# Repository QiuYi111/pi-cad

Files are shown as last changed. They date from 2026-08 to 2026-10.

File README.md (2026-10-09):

<p align="center">
  Reify · 器成 — Make ideas real.
</p>

<p align="center"><strong>From imagination to what exists.</strong></p>

[English](README.md) · [简体中文](README.zh-CN.md)




Reify is a desktop mechanical-design agent built on
[Prime Agent](https://github.com/PrimeIntellect-ai/prime-agent). Describe a part,
assembly, modification, or analysis. Reify can clarify the brief, explore a
concept, write deterministic CAD, build STEP geometry, inspect the result, and
keep the source, model, measurements, and review connected.

It uses your ChatGPT account through OpenAI Codex OAuth. No API key is required.

## Why Reify

Language models are good at searching a design space. Engineering work also
needs durable facts.

Reify gives the model a persistent Python workbench where requirements,
artifacts, calculations, and observations remain usable across a long task. A
small workflow card shows the current goal, available operations, required
deliverables, and legal next steps. The model stays free to reason and write
code; the runtime governs what counts as a valid build, measurement, review,
and release.

- **Programmable tools.** Prime composes CAD, probes, simulations, and image
  generation in a persistent IPython session.
- **Visual feedback by default.** A build returns useful model views to both the
  agent and the user.
- **Artifacts with identity.** Source, STEP files, images, and evidence retain
  their role and revision. Rebuilding invalidates stale evidence.
- **Workflows that enforce completion.** Missing obligations and invalid
  transitions are executable rules, not reminders.
- **Inspectable work.** The app shows model activity, STEP geometry, workflow
  state, processed trajectories, and distillation progress.

## See it work

### Design a new part

> Design a 100 × 80 × 5 mm mounting plate with four 5 mm corner holes. Keep at
> least 8 mm edge distance, add printable fillets, and export STEP.

Reify turns the brief into deterministic source and geometry, returns visual
feedback, measures the built result, and keeps the final files in your project.

### Build an assembly

> Design a compact foldable phone stand for portrait and landscape use. Make
> the hinge, stops, and clearances suitable for FDM printing.

The agent can explore a concept, define interfaces, build individual parts,
inspect the assembly, and revise the actual candidate.

### Modify or inspect an existing model

> Increase these mounting holes from 4.2 mm to 5.0 mm without changing the
> outer envelope. Verify the result.

> Inspect this STEP file and report its exact bounding box and solid count. Do
> not modify it.

Modification and analysis use separate workflows. Measurements remain bound to
the artifact that was actually inspected.

## Install on Windows

Download **`Reify-Setup-x64.exe`** from the latest release and open it.

The first-run setup uses the same interface as the main workbench. It:

1. checks WSL 2 and Ubuntu;
2. offers the standard Windows WSL installation when they are missing;
3. installs the bundled Prime and Reify runtime;
4. connects your ChatGPT account;
5. asks you to choose a project folder.

Administrator approval is only requested if Windows must enable WSL. Windows
may require one restart. Reify keeps its files and continues setup afterwards.

Requirements:

- Windows 10 version 2004 or newer, or Windows 11;
- virtualization enabled in firmware;
- permission to enable WSL when it is not already installed;
- internet access for ChatGPT sign-in and model calls.

The matching Prime Agent and Reify runtime ship inside the installer. Normal
setup does not clone repositories.

## Install on Linux

Download `Reify-Linux-x86_64.AppImage` or the matching `.deb`. Linux runs the
agent runtime directly; WSL is not involved. Install Bubblewrap with the system
package manager before first launch. The app supplies Prime, Reify, and Node,
then prepares its managed Python environment with `uv`.

## Install on macOS

Download `Reify-macOS-arm64.dmg`, drag Reify to Applications, and open it.
The Apple Silicon build runs Prime and Reify directly on macOS and uses the
system `sandbox-exec` boundary for author and reviewer processes. Public builds
must be Developer ID signed and notarized; unsigned CI artifacts are for
testing only.

## Optional FreeCAD part backend

For parts that are edited again and again, the agent can use `cad.part`: a
parametric FreeCAD model that it changes with small JSON operations. Every
change returns the seven standard views (changed faces in orange, features
labelled by name), a summary of what changed, and a structured error when it
fails. It is optional. Install it with `npm run setup:freecad` (about 4 GB, no
sudo; see `docs/installing-reify.md`). Without it, build123d works as before.

## First design

Open Reify, choose a folder, sign in, and enter a request in the Workbench.
Provider, model, reasoning level, reviewer, and workspace permissions are
available in Settings.

The desktop app includes streaming agent state, a workflow rail and editor, an
interactive STEP viewer, semantic tool cards, project switching, and trajectory
distillation.

## Command line

Developers can also run Reify directly on Linux, macOS, or WSL 2. The repository
and compatibility-facing command names remain `pi-cad` during the rename:

```bash
sudo apt-get update
sudo apt-get install -y bubblewrap libglu1-mesa ripgrep

git clone https://github.com/QiuYi111/prime-agent.git
git clone https://github.com/QiuYi111/pi-cad.git

cd prime-agent && npm ci
cd ../pi-cad
npm install
npm run setup:python
PRIME_AGENT_REPO="$PWD/../prime-agent" npm run prime:setup
```

Main workflows:

| Workflow | Purpose |
| --- | --- |
| `mechanical.one-shot` | New part or assembly through release |
| `mechanical.modify` | Controlled revision of an existing design |
| `mechanical.analysis` | Read-only geometric investigation |

Workflow packages may also define trusted Git actions at workflow start and
phase entry or exit. Reify can initialize a repository and commit changed
source files; generated STEP files and images stay outside Git. Remote pull and
push remain disabled unless the workflow explicitly enables them. Each
workspace commit records the matching Git revision.

## Scope

Reify currently targets Windows with WSL 2 and Ubuntu. It provides STEP-first
build123d authoring, B-Rep probes, managed visual feedback, workflow packages,
review isolation, concept-image generation, and packaged engineering recipes.

It does not replace physical tests, manufacturing review, or professional
engineering sign-off.

## License

[MIT](LICENSE). The Codex image-generation compatibility package retains its
upstream attribution in
[`packages/prime-codex-image-gen`](packages/prime-codex-image-gen).

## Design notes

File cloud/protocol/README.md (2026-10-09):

# @reify/cloud-protocol

Shared, dependency-free types and helpers for the Reify hosted service: the bridge
message types and binary frame codec (`src/bridge.ts`), workspace path checks
(`src/paths.ts`), and the exec helper shared with the desktop `NativeBridge`
(`src/native-exec.ts`). Consumers import the TypeScript source directly.

Run tests with `npm test`.

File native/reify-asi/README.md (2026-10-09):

# reify-asi

Command line feature analyzer for B-rep parts. It is the second DFM layer
(see `docs/dfm/implementation-plan.zh-CN.md`, section 7). It reads a `.brep`
file and writes JSON with holes, cavities, blends, per-face wall thickness and
dihedral angles. Face IDs are 1-based in `TopExp::MapShapes` order, the same
order as FreeCAD's `Shape.Faces`.

It links Analysis Situs `asiAlgo` (v2024.2, BSD-3-Clause) and OCCT 7.6 (LGPL-2.1
with the OCCT exception). The OCCT 7.6 toolkit is built from conda-forge
(`occt 7.6.3`, the `novtk` variant without VTK). No Qt, VTK or Tcl is used.

## Install

```sh
bash scripts/bootstrap-asi.sh            # installs to ${XDG_DATA_HOME:-~/.local/share}/pi-cad/runtimes/asi
bash scripts/bootstrap-asi.sh --force    # removes the env, sources and build, and rebuilds
```

Linux x86_64 only. Exit 2 on other platforms. The script downloads the
Analysis Situs archive, checks its SHA-256, applies
`patches/asiAlgo-utils-no-x11.patch`, and builds with the conda compiler.

Rebuild the program only (after editing `src/`), using the environment the
bootstrap created:

```sh
ASI=${PI_CAD_ASI_HOME:-$HOME/.local/share/pi-cad/runtimes/asi}
$ASI/env/bin/cmake --build $ASI/build -j4        # if the build tree still exists
# or a fresh tree:
$ASI/env/bin/cmake -S native/reify-asi -B /tmp/reify-asi-build \
  -DCMAKE_CXX_COMPILER=$ASI/env/bin/x86_64-conda-linux-gnu-g++ \
  -DCMAKE_PREFIX_PATH=$ASI/env \
  -DASI_SRC=$ASI/analysis-situs-2024.2/src \
  -DEIGEN_INCLUDE_DIR=$ASI/env/include/eigen3
$ASI/env/bin/cmake --build /tmp/reify-asi-build -j4
```

The `bin/reify-asi` wrapper sets `LD_LIBRARY_PATH` to the environment's
`lib/` and runs `bin/reify-asi-bin`.

## Command line

```sh
reify-asi analyze --in part.brep --out result.json \
  [--checks holes,cavities,blends,thickness,dihedral] [--thickness-samples 400]
reify-asi analyze --in part.brep --dump-faces     # face table to stdout, no analysis
reify-asi --version
```

- `--checks` defaults to all five. Only the requested checks appear in the JSON.
- `--thickness-samples N` is the number of sample points per face (default 400).
- `--dump-faces` prints `{"faces": [{"id", "centroid", "area"}, ...]}` (the
  values FreeCAD exposes as `Faces[id-1].CenterOfMass` and `.Area`) and exits.
  `--out` and `--checks` are ignored in this mode.

Exit codes: `0` ok; `2` bad command line; `3` input missing, unreadable or
empty; `4` an analyzer failed; `5` output could not be written. On failure one
line is printed to stderr.

Output (abridged; see `docs/dfm/contract.md`):

```json
{"version": 1, "asi": "2024.2", "faces": 10,
 "holes": [{"faces": [7], "diameter": 3, "depth": 5, "axis": [0, 0, 1], "through": true, "bottom": "none"}],
 "cavities": [{"faces": [7], "base_faces": [3, 5]}],
 "blends": [{"faces": [7], "radius": 2, "kind": "concave"}],
 "thickness": [{"face": 3, "min": 5, "at": [1, 0.75, 5]}],
 "dihedral": [{"edge_faces": [3, 4], "angle_deg": 90, "convex": true, "edge_dir": [1, 0, 0]}],
 "timing_ms": {"load": 0.6, "holes": 3.0}}
```

## How each check is computed

- `holes`: `asiAlgo_RecognizeDrillHoles` finds the hole faces. Connected groups
  of cylinder faces form holes. Through or blind is decided by probing the
  solid just past each end of the cylinder. A blind bottom is the face across
  the bottom circle (`flat`, `cone`, `sphere`, otherwise `unknown`). A through
  hole has `bottom: "none"`. `depth` is the cylinder length (the drill point is
  not included).
- `cavities`: `asiAlgo_RecognizeCavities`. `base_faces` are the faces the cavity
  opens into or sits on.
- `blends`: `asiAlgo_RecognizeBlends`. `kind` is the majority vexity recorded by
  the recognizer, or `unknown` when none was recorded.
- `thickness`: OCCT ray casting, not Analysis Situs' own routine (that routine
  needs the optional Mobius library and returns a mesh field). For each face,
  points are sampled over the trimmed face and a ray is cast along the inward
  normal. The face value is the smallest hit distance. Faces with no hit are
  omitted.
- `dihedral`: the AAG arcs from `asiAlgo_AAG`. `angle_deg` is the magnitude of
  the angle between the two face normals (the AAG reports it signed).
  `convex` comes from the AAG arc type. `edge_dir` is the unit tangent of the
  shared edge at its midpoint.

## Patch

`patches/asiAlgo-utils-no-x11.patch` removes the X11/OpenGL screenshot path from
`asiAlgo_Utils.cpp` (`GeneratePixmap` returns null). Nothing in this tool calls
it. The CMake project refuses to configure an unpatched source tree.

## License

- Analysis Situs (`asiAlgo`, `asiActiveData` parts used here): BSD-3-Clause.
  The LICENSE is in the source archive.
- OCCT 7.6: LGPL-2.1 with the OCCT exception. Distribution must follow the
  LGPL terms (dynamic linking, notice).
- The `reify-asi` sources in this directory: same terms as the repository.

## Files

- `CMakeLists.txt`, `cmake/asi_sources.cmake`: build; the list of Analysis Situs sources used.
- `src/`: CLI (`main.cpp`, `analyze.cpp`), checks (`holes.cpp`, `cavities.cpp`,
  `blends.cpp`, `thickness.cpp`, `dihedral.cpp`), face table (`faces.cpp`), JSON (`json.cpp`).
- `patches/`: source patch applied to Analysis Situs.
- `tools/make_test_parts.py`: builds test parts with FreeCAD's Part API (run with the FreeCAD env's Python).
- `tools/check_face_ids.py`: E0-b check; compares `--dump-faces` with FreeCAD's faces.
- `testdata/plate_4holes.brep`: fixture used by the bootstrap smoke test.
- `conda-linux-64.lock`: explicit conda lock for the environment.

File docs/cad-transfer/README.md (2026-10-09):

# cad.transfer: Fusion and SolidWorks files with feature history

`cad.transfer` sends a Reify part (a FreeCAD `.FCStd` document) to Autodesk Fusion (`.f3d`) or SolidWorks (`.SLDPRT`). The CAD program builds the part again, feature by feature. The file has a feature tree with the Reify feature names. The user can change a dimension in Fusion or SolidWorks and the model rebuilds.

The CAD program runs on the user's own computer. The Reify desktop app starts it. Reify never runs Fusion or SolidWorks on a server.

The wire formats are in [protocol.md](protocol.md).

## Setup

The text below is the same text as Settings > CAD exports in the desktop app.

### Autodesk Fusion

1. Install Autodesk Fusion on this computer.
2. Click **Install add-in**. Reify copies the ReifyExport add-in into Fusion.
3. Start Fusion. If Fusion is open, close it and start it again.
4. In Fusion, open Utilities, then Add-Ins. On the Add-Ins tab, select ReifyExport. Click Run. Turn on Run on Startup.
5. Sign in to Fusion. Then click **Test export**.

Keep Fusion open while you export. The card shows "Add-in running" when the add-in writes its heartbeat. It shows "Add-in not running" when the heartbeat is older than 15 seconds.

Add-in folder:

- Windows: `%APPDATA%\Autodesk\Autodesk Fusion 360\API\AddIns\ReifyExport`
- macOS: `~/Library/Application Support/Autodesk/Autodesk Fusion 360/API/AddIns/ReifyExport`

### SolidWorks (Windows only)

1. Install SolidWorks 2022 or a newer version. SolidWorks must run on Windows.
2. Start SolidWorks one time. Wait until SolidWorks is fully open. Then you can close it.
3. Click **Test export**. Reify starts the ReifyExport program that comes with Reify.

SolidWorks must be activated (licensed). The first export starts SolidWorks if it is closed. Close modal dialogs in SolidWorks before you export, because a modal dialog blocks the export program. The minimum version, 2022, is a proposal. It has not been tested.

The SolidWorks section is hidden on macOS and Linux. In a WSL setup, Reify copies the project files to Windows and back. You do not change any path.

### Test export

**Test export** builds a reference plate (40 x 30 x 5 mm, 4 through holes, 1 pocket), exports it, runs the equivalence check and shows pass or fail and the log path.

## API

```python
import cad

await cad.transfer.status()
# TransferStatus(fusion='ready', solidworks='not_installed')

features = await cad.transfer.features("parts/bracket.FCStd")   # dry run, no CAD program needed
# TransferFeatures(part='bracket', features=7, path='build/transfer/bracket.features.json')

job = await cad.transfer.export("parts/bracket.FCStd", target="fusion", output="exports/bracket.f3d")
result = await job.result()
# TransferResult(target='fusion', file='exports/bracket.f3d', check='passed', features=7)
```

- `doc` is a `.FCStd` path or a `PartDocument`. The tool reads the committed, recomputed document. It never changes it.
- `output` defaults to `exports/<stem>.f3d` or `exports/<stem>.SLDPRT`.
- `check=False` is for debugging. The result then has `check='skipped'`.
- `TransferResult` fields: `target`, `file`, `check_step`, `check`, `features`, `log`, `detail`. A result can be stored in a commit.

| Error code | Meaning |
|---|---|
| `TRANSFER_TARGET_NOT_READY` | The target is not set up. The hint points to Settings > CAD exports. |
| `TRANSFER_UNSUPPORTED_OP` | A feature is outside the supported set. `target` is the semantic path of the feature. |
| `TRANSFER_EXECUTOR_FAILED` | Fusion or SolidWorks could not build a feature. `target` names it. |
| `TRANSFER_CHECK_FAILED` | The exported shape differs. `target` is the first feature that differs. The files are kept for debugging. |
| `TRANSFER_TIMEOUT` | The CAD program did not finish in time. |
| `TRANSFER_UNAVAILABLE` | The Reify desktop app is not running for this project. |

Sidecar operations: `transfer-status`, `transfer-features`, `transfer-export`. In desktop read-only mode, `transfer-export` is denied. The dry run is allowed.

## How it works

1. `export_features` runs in the FreeCAD worker on the recomputed document. It writes canonical feature JSON (`reify.features/1`). It does not replay `ops.jsonl`.
2. The sidecar writes a request in `.pi-cad/transfer/requests/`. The desktop app picks it up. The UI button uses the same code.
3. The desktop app starts the executor: it writes a job file for the Fusion add-in, or starts `ReifyExport.exe` for SolidWorks. One job runs at a time for each executor.
4. The executor builds the part, writes the native file and a verification STEP, and copies the result back into the project.
5. The sidecar compares the verification STEP with the Reify STEP: relative volume error at most 1e-6, equal bounding boxes (1e-6 of the part size), and face fingerprints that match one to one.

The coordinate system stays Z up. A Y-up option is a later change. If it is added, it must also apply to STEP and assemblies.

## Supported features

| Reify feature | Fusion | SolidWorks |
|---|---|---|
| `pad` (length, `midplane`, `reversed`, `up_to_face` on a planar face) | yes | yes |
| `pocket` (length or `through_all`) | yes | yes |
| `hole`: through, blind, counterbore, countersink, drill point | yes (native hole) | yes (Hole Wizard) |
| `hole`: cosmetic thread | no (a warning is written; the diameter stays) | yes |
| `fillet`, `chamfer` (constant size, edges found by geometry) | yes | yes |
| `polar_pattern`, `linear_pattern` (axis along X, Y or Z) | yes | yes |
| `mirror` (origin plane or offset plane) | yes | base or offset plane |
| Sketch geometry: line, arc, circle | yes | yes |
| Sketch plane: XY, XZ, YZ plus offset, Body placement; sketches on planar faces | yes | yes |
| Sketch dimensions (level 1: values) | yes | yes |
| Reify parameters (level 2: user parameters / equations) | yes | yes |
| Density | yes (warning if the API cannot set it) | mass override only (always a warning) |
| Assemblies: part positions only | yes (one `.f3d`) | yes (`.SLDASM` plus part files) |
| Island inside a loop (nesting depth 2 or more) | yes (even-odd rule) | **no** |

In an assembly, a part can come in through `link` or through `import_step` of a STEP that Reify wrote from a project part. Reify records the source `.FCStd` and its hash in `<step>.source.json` when it writes the STEP. If the part changed since (`stale_step`), or the STEP has no record (`unknown_step_source`, for example a bought-in STEP), the export stops and names the unit. Use `link` for project parts.

When an expression is outside the supported grammar (numbers, parameter names, `+ - * /`, parentheses, `mm`, `deg`), the executor uses the value and writes an entry in `result.json` `warnings`. It never skips a feature.

Everything else stops the export with `TRANSFER_UNSUPPORTED_OP`, and the error names the feature: modeled threads, taper, midplane pockets, pad `up_to_last`/`two_lengths`, variable fillets, non-planar faces, bought-in STEP units in an assembly. Joints and mates are not exported: an assembly goes out with the pose its joints solved to (the parts are placed, not jointed), and the result carries a `notes` entry that says so. Reify never skips a feature silently. The canonicalizer deviations are in [protocol.md](protocol.md) section 8.

## Known limits

- The two executors have not run against a real Fusion or SolidWorks yet. Both READMEs list every API assumption that needs a real install: [Fusion](../../executors/fusion/README.md), [SolidWorks](../../executors/solidworks/README.md). The SolidWorks executor has not been compiled.
- A dimension change in Fusion or SolidWorks changes that file only. It does not change the Reify parameter. Parameters that Reify exports become user parameters (Fusion) or equations (SolidWorks), so one change there rebuilds all features that use it.
- The highest-risk unverified parts are the assembly code (both targets) and the SolidWorks Hole Wizard call. Its constants are placeholders. Record a macro in SolidWorks and replace them.
- Fusion shows the new document tab during a job. The add-in closes the document without a cloud save (`close(False)`). Check on a real install that nothing reaches the cloud project.
- The Fusion and SolidWorks API versions that were tested are not pinned yet. Record them after the manual checks.
- SolidWorks runs only on the customer's licensed copy.
- The C# executor needs a code signature, or Windows SmartScreen warns the user. The signing step is a hook in `apps/desktop/scripts/package-windows.mjs`. It does nothing until the signing variables are set.

## Manual checks before the issue closes

Record each result in the PR.

1. Export `body_shell`, `axle`, `roller_screw` and the reference plate to Fusion (and to SolidWorks), once from the UI and once from the agent. The equivalence check must pass.
2. The feature tree shows named features in the same order as Reify.
3. Change one dimension in Fusion or SolidWorks. The model must rebuild.
4. **WSL:** run one export from a project in WSL (`/mnt/c/Users/...` paths). The job folder crosses the Windows/WSL boundary, so check that the native file and the verification STEP come back into the project.
5. An assembly of project parts: export once with `link` and once with `import_step` of the part STEPs (the second must work only while the STEPs are current).
6. Record the Fusion and SolidWorks versions that were tested, and whether Fusion left anything in the cloud project.

## Phases

P0 and P1 (parts, through holes, polar patterns) and P2/P3 (the table above) are written. Nothing in the executors has run against a real Fusion or SolidWorks. Treat P2 and P3 as unverified until the manual checks in the issue pass.

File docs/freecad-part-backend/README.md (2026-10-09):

# FreeCAD part backend: implementation notes

This note records what was built for the plan "FreeCAD Part backend (one PR)", what was measured, and where the installed FreeCAD differs from the plan. The user-facing text is in `docs/installing-reify.md` and `skills/parametric-cad-modeling/references/freecad-part-ops.md`.

## Measured

| Item | Value |
|---|---|
| FreeCAD | 1.1.0 (conda-forge `freecad=1.1.0`, build snapshot `20260325`) |
| OpenCASCADE | 7.9.3 |
| Python in the FreeCAD environment | 3.11 |
| Disk use after install | 4.2 GB (4.1 GB environment + 18 MB micromamba; the download cache is cleaned) |
| Install time (`npm run setup:freecad`, fast network, Linux x86_64) | 41 s |
| Cold start (spawn worker, import FreeCAD, create a document) | 0.31 s |
| `worker.selftest` (Pad, Pocket, Fillet, STEP export) | 0.67 s including interpreter start |
| `part-apply`, first build (plate, 4 holes, fillet) with identity bind, geometry check, 7 renders, evidence | 5.5 s (includes the first start of the uv `cadctl` kernel) |
| `part-apply`, one edit, warm | 2.1 s (worker part about 0.15 s; the rest is bind, inspect and rendering) |
| `part-try`, warm | 1.7 s |
| `cad.model.build` (build123d), same part, for comparison | 1.3 to 1.6 s |
| Pose sweep, 33 samples with refine, two bodies | 0.35 s |

## What the views look like

Hole widened from 6 mm to 8 mm with one op, `{"op": "set", "target": "Params", "prop": "hole_d", "value": 8}`. Only the four hole walls are orange, `mount_hole` is labelled, and the first image's text says `volume -527.788 mm³`.

| Before (rev 1) | After (rev 2) |
|---|---|
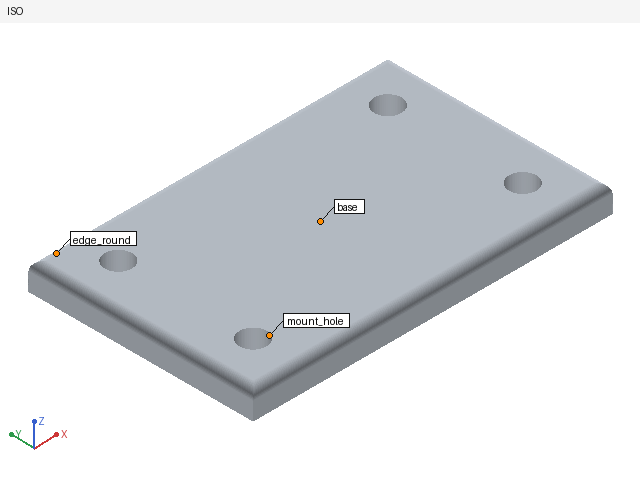
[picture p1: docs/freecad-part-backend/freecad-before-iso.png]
before
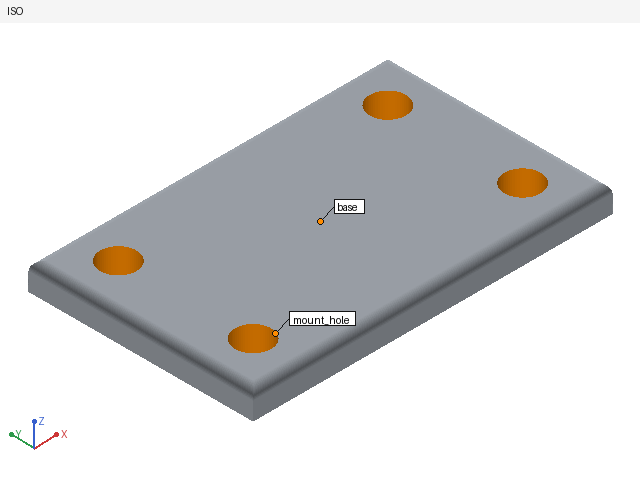
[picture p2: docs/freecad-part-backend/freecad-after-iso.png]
after
|  |  |

The same feature with build123d: a wider plate and one bigger hole, rebuilt with `cad.model.build`. The new faces are orange and the summary reports the volume and bounding box change.

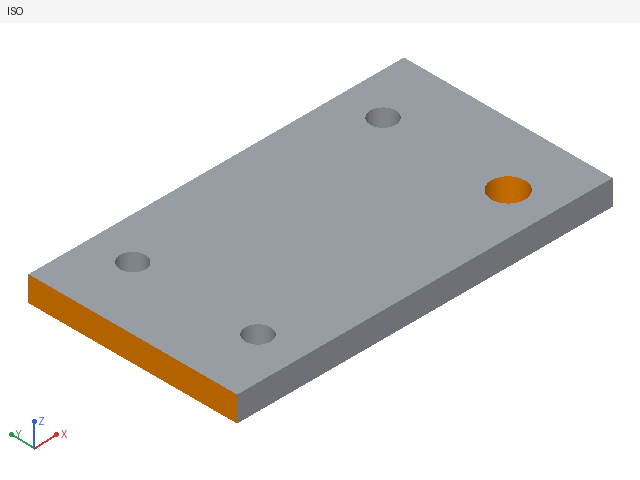
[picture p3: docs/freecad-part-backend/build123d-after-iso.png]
build123d


## Deviations from the plan

1. **micromamba comes from conda-forge**, not from `micro.mamba.pm`. The bootstrap script downloads `micromamba-2.9.0-0.tar.bz2` from the conda-forge channel and checks a pinned SHA-256. It is the same host that serves the FreeCAD packages, so one allowed host is enough.
2. **`FreeCAD.so` is in `<env>/lib`**, which is not on `sys.path`. `runtime.json` therefore has a `libPath` field, and the worker is started with `PYTHONPATH=<repo>/python:<libPath>`.
3. **Roles do not use FreeCAD's element map.** `getElementHistory` returns nothing for faces, and a mapped name changes when a later feature touches the face (a pad's top face after a hole is cut through it). Roles come from the geometry each feature defines: the faces a feature created are the faces of its result that are not inside a face of its base shape; a face of the final body belongs to a created face when both lie on one surface and the final face is inside it (`python/reify_freecad/roles.py`). `ROLE_FALLBACK_GEOMETRIC` is reported only when a role cannot be derived at all. The role-stability test records five edits (diameter, thickness, fillet, slot pocket) with the wall still the right cylinder.
4. **Rollback reloads the saved file** instead of `abortTransaction`. The disk file is the only trusted state. Transactions are still opened.
5. **The highlight shows new surfaces, not every touched face.** A plate that gains a hole keeps its top face grey; the hole wall is orange. `faces.new` and `faces.removed` still count every face whose fingerprint changed, with the rule of section 3.1. If more than 60% of the faces changed, nothing is coloured. Fingerprints carry one extra field, `ap` (a point on a cylinder or cone axis), for this.
6. **The identity selector grammar gained `axisPoint` and `bboxCenter`.** `centroid` of a curved face in cadctl is a parametric centre that depends on the seam. FreeCAD cannot reproduce it. See `docs/identity-protocol.md`.
7. **A `part-apply` that fails after the commit is undone.** If identity binding or the geometry check fails after the worker committed, the sidecar calls `undo` and reports `rolledBack: true`, so no half-applied revision remains.
8. **`part-open` of an existing document with geometry also builds and observes it**, so the Agent sees the model when it opens it. A document without geometry returns no images.
9. **Pose sweep views label the two parts** (centres of the two named bodies) instead of colouring them.
10. **No CJK label font.** The repository has none. Labels are ASCII; other characters become `?`.
11. **Not changed**: the desktop activity cards. A `doc.apply(...)` call shows as a generic Python card with its images.

## Assemblies and review fixes

- Units are `body`, `occurrence` and `reference`. The ops `link`, `import_step` and `joint` add them.
- An occurrence is an `App::Part` container that holds a `Part::Feature` copy of the part shape. The copy refreshes when the sha256 of the part file changes. This is a deviation from the plan: it does not use a cross-document `App::Link`, because that link is not stable when documents reload.
- A joint computes the child pose from role frames. Its `value` is bound by an expression. `apply_joints` runs after each recompute. `sweep` can sweep a joint value.
- Named export writes a flat STEP: one product per unit, named by its semantic path, with its pose. `cadctl assembly-tree` and render `focus`/`hide` use these names.
- `cad.part` is now the default modeling path. build123d stays for compatibility.
- If FreeCAD is not installed, the error is `FREECAD_NOT_INSTALLED`. Tell the user the one command (`npm run setup:freecad`, about 4.2 GB, no sudo, once) and stop. There is no silent build123d fallback.

## Version checks (plan section 7)

1. `App::VarSet` works. Dynamic properties (`ReifyPath`, the `Params` attributes, requirement fields) are stored in the `.FCStd` and survive a reopen (`test_the_document_reopens_with_the_same_model`).
2. Sketch properties `DoF`, `ConflictingConstraints`, `RedundantConstraints`, `MalformedConstraints` and `solve()` exist as named. Constraint expressions need units: `Params.w - 3` fails with a unit mismatch, so generated expressions write `3 mm`, and an `=expression` the user writes without units is reported as `EXPRESSION_INVALID` with a hint.
3. `ElementMap`, `ElementReverseMap` and `getElementHistory` exist, but see deviation 3.
4. `PartDesign::Hole`: `Diameter`, `Depth`, `DepthType` (`Dimension`, `ThroughAll`), `Threaded`, `ThreadType`, `ThreadSize` (spelled `M6x1`, so `M6` is expanded), `HoleCutType` (`Counterbore`, `Countersink`), `DrillPoint` (default angled, so a cone is a countersink only when the hole has one).
5. `import PartDesign` needs no GUI.
6. `openTransaction`, `commitTransaction` and `abortTransaction` work headless with `UndoMode = 1`.

Other differences that cost time:

- Features and sketches inside a body are in the body's local frame; only `Body.Shape` carries the pose. Roles are found in the local frame and moved to world coordinates by the body placement.
- A pattern must be added to the body after `Originals` is set (`doc.addObject`, then `body.addObject`). With `body.newObject` the body does not move its Tip to the pattern.
- `Pad.Type` values: `Length`, `UpToLast`, `UpToFirst`, `UpToFace`; `Pocket.Type` has `ThroughAll`.
- There is no `isTouched()`. "Recomputed" comes from a document observer that sees `Shape` assigned during `recompute()`. FreeCAD touches every object that references the `Params` object when one parameter changes, so `features.recomputed` lists those objects, not only the ones whose value changed.
- A body's single solid can come wrapped in a compound, which has no `CenterOfMass`; queries unwrap it.
- The conda-forge `freecad` package has newer weekly builds (`2026.09.16`). The environment pins `1.1.0`.

## Not verified here

- **osx-arm64.** The lock file was solved on Linux (`CONDA_OVERRIDE_OSX=11.0`) and has not been installed on a Mac. The default macOS install path contains a space (`Application Support`); conda environments in paths with spaces can break scripts with shebang lines. If the install fails there, set `PI_CAD_FREECAD_HOME` to a path without spaces.
- **Desktop manual demo** (acceptance item 4) was done through the Agent API, not through the Reify desktop window.

## Tests

| Where | What | Needs FreeCAD |
|---|---|---|
| `tests/test_reify_freecad_pure.py` | op schema, shared path vectors with cadctl, expressions, error mapping, no FreeCAD import in pure modules | no |
| `tests/freecad/` (34 tests) | nine features, recompute scope, rollback, conflicts, role stability, undo, pose sweep, budget, requirements, the examples in the reference document | yes |
| `tests/freecad-worker.test.ts` | worker bridge with a fake worker: order, timeout kill, restart and reopen, errors, abort | no |
| `tests/part-ops-authorization.test.ts` | `model.build` versus `probe.run`, read-only author, reviewer | no |
| `tests/part-e2e.test.ts` | open, build, edit, resolve the named hole, try, failing fillet, budget kill, undo | yes (skipped otherwise) |
| `tests/build-changes.test.ts`, `tests/test_face_fingerprints.py`, `tests/test_render_highlight.py`, `tests/test_bind_identity.py` | change summary, fingerprints (shared vectors), render highlight and labels (pixel-identical without them), identity binding | no |

Run the FreeCAD tests with `PYTHONPATH=python:<env>/lib <env>/bin/python -m unittest discover -s tests/freecad`.

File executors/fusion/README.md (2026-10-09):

# ReifyExport: Autodesk Fusion add-in

Executes Reify canonical feature JSON (`reify.features/1`) in Fusion and exports `.f3d` plus a STEP file for the equivalence check. The wire contract is `docs/cad-transfer/protocol.md` (sections 1 and 2). Version 0.2.0 (P0 to P3).

## Install

Copy the folder `ReifyExport/` to:

- Windows: `%APPDATA%\Autodesk\Autodesk Fusion 360\API\AddIns\ReifyExport`
- macOS: `~/Library/Application Support/Autodesk/Autodesk Fusion 360/API/AddIns/ReifyExport`

The desktop app reads `ReifyExport.manifest` (`version`) to show the installed version. `ReifyExport.py` `__version__` must match (a test enforces it).

## Enable

In Fusion: Shift+S (Scripts and Add-Ins), tab Add-Ins, select ReifyExport, Run. Tick "Run on Startup" so it starts with Fusion. The manifest has `runOnStartup: false` as a default.

## Job protocol (summary)

Job root: Windows `%LOCALAPPDATA%\Reify\transfer`, macOS `~/Library/Application Support/Reify/transfer`. Env `REIFY_TRANSFER_ROOT` overrides it.

- Add-in writes `fusion/heartbeat.json` every 5 s (atomic): pid, version, app, `signedIn`, `updatedAt`.
- Dispatcher writes `fusion/inbox/<jobId>.json` (tmp + rename). The add-in claims it by renaming it to `fusion/outbox/<jobId>/job.json`, builds, and writes `part.f3d`, `check.step`, `log.txt`, and last `result.json` (atomic).
- Result errors: `{code: EXECUTOR_FAILED | UNSUPPORTED_OP | BUSY, message, feature, step}`. `feature` is the Reify semantic name. Steps: `plan`, `document`, `sketch` (sketch failures report the feature that uses it), `profile`, `extrude`, `pattern`, `export`, `timeout`, `job`.
- One job at a time. Plan errors (unsupported feature) are raised before Fusion is touched.

## Code layout

Pure Python, no `adsk` import, unit tested with `python3 -m unittest discover -s tests/fusion_addin -v`:
`jobroot.py`, `jobs.py` (claim, validate, result, error mapping), `plan.py`, `profiles.py` (even-odd), `geom.py`, `workers.py` (watcher and heartbeat threads).
Thin Fusion layer: `fusion_exec.py` (all `adsk` calls), `ReifyExport.py` (run/stop, custom events).

Threading: the watcher thread only calls `app.fireCustomEvent`. The event handler runs on the Fusion main thread and does all API calls. The heartbeat thread uses a cached snapshot (refreshed by a tick event and after each job), so the heartbeat stays fresh while a long job blocks the main thread.

## What it builds (0.2.0)

Each group sits behind a flag of `plan.build_plan(enable_p1, enable_p2, enable_p3, native_holes, bind_params)` so it can be switched off.

- P0: `pad` (length, midplane), `pocket` (length or through_all).
- P1: extrude-cut `hole` of circles (used when `native_holes=False`), `polar_pattern` (CircularPatternFeature, origin axis X/Y/Z through the origin only).
- P2: `linear_pattern` (RectangularPatternFeature, one direction along a world axis, spacing mode), `mirror` (MirrorFeature; plane must be parallel to XY/XZ/YZ: origin plane when through the origin, else an offset construction plane; tilted planes are `UNSUPPORTED_OP` naming the feature), sketch `dimensions`, top-level `material.density_kg_m3`, assembly jobs.
- P3: user parameters, native `holeFeatures` (through/blind, counterbore, countersink, drill point flat/angled), `fillet`, `chamfer` (edges resolved by `edgematch.py`), `face_ref` (`facematch.py`) for sketches on tilted faces and for `pad` `up_to_face`.
- Sketch geometry: line, arc, circle, polyline. Each profile region is chosen with the even-odd rule (see `profiles.py`); profiles are never selected blindly.
- Anything else raises `UNSUPPORTED_OP` naming the feature (and the option) in the plan, before Fusion is touched. Nothing is skipped silently.

Behaviour worth knowing:

- **Parameters (level 2).** `parameters[]` become `design.userParameters`. A scalar `expr` is bound (as a Fusion expression string) only when it passes `params.py`: grammar of protocol section 7, known names, the expected unit dimension (length or angle), and it evaluates to the scalar's `value` (1e-6). A bare number next to a quantity adopts its unit (`=hole_d + 2` becomes `hole_d + 2 mm`). Anything else uses the value and adds `{feature, field, expr, reason}` to `result.json` `warnings`. If Fusion rejects an accepted expression at feature creation, the feature is rebuilt from the value and a warning `field: "expression"` is added. The feature is never skipped. Parameters are design-global, so assembly jobs do not create them (one warning per part).
- **Warnings.** `result.json` always has `warnings` (a list). Besides expressions it carries: cosmetic thread not created, hole-sketch dimensions not added (the hole sketch is rebuilt from `positions`), a dimension skipped because Fusion's sketch axes are rotated against the canonical u/v (horizontal/vertical is undefined), and a density that could not be applied.
- **Holes.** `native_holes=True` (default) uses `holeFeatures` with sketch points at `positions`. A `thread` is NOT created: a Fusion tapped hole changes the hole diameter, which would break the equivalence check, so the hole keeps its diameter and a warning is added. `thread.modeled: true` is `UNSUPPORTED_OP`.
- **Sketch dimensions.** Added after the geometry is drawn: `distance` (aligned), `distance_x`/`distance_y` (horizontal/vertical), `radius`, `diameter`, `angle`. A dimension that the API rejects fails the job with `EXECUTOR_FAILED`, `step: "dimension"`, and the message names the sketch. If the dimension carries a valid parameter expression, it is bound to the dimension.
- **Edge and face refs.** Edges are matched by curve type, midpoint, length (and radius/centre/axis/start/end when given) with tolerance `1e-4 x max(part diagonal in mm, 1)`. Zero or several matches fail with `step: "edge_ref"` / `"face_ref"` naming the feature. The tolerance reading of "1e-4 mm times the part diagonal" is ours (protocol section 7 is ambiguous).
- **Assemblies.** `job.kind == "assembly"` with `assembly` inline. One new design, one component per occurrence (`addNewComponent(matrix)`, matrix columns are the rotation columns, origin in cm), each built with the part's feature plan. The STEP and the single `part.f3d` contain the whole assembly. `feature_volumes` has one entry per occurrence name. Mirrored (det < 0) transforms are `UNSUPPORTED_OP`. `files.extra` is not produced.
- **Material.** The density is set by copying a library material (`design.materials.addByCopy`), setting `structural_Density` (kg/cm^3) and assigning it to the bodies. If anything fails it is a warning, never a failed job.

Other decisions and limits (from 0.1.0):

- A second `pad` joins the existing body (first pad is a new body). A `pocket`/`hole`/`fillet`/`chamfer` before any body is an error. Only one body per part.
- `polar_pattern` and `linear_pattern` need a world axis; `mirror` accepts patterns as originals, patterns do not. For angles below 360 the angle is the span from first to last occurrence.
- Distances are passed with `ValueInput.createByReal` in cm (the API unit), or `createByString(expression)` when a parameter is bound.
- Sketch plane: base origin plane when the offset is 0, else a construction plane by offset. Offset sign and extrude direction are measured against the real Fusion plane normal at run time (point mapping uses `sketch.modelToSketchSpace`), so a flipped Fusion normal is handled.
- Reify is Z-up. The add-in forces `defaultModelingOrientation = ZUp` while creating the document and restores the preference afterwards.

## Unsaved and cloud documents (read this)

- `app.documents.add(FusionDesignDocumentType)` creates a NEW, UNSAVED document in memory. It is not on the cloud until someone saves it (Save asks for a project and name). The add-in never calls `save` or `saveAs`.
- `doc.close(False)` closes the document and discards it; `False` means "do not save". The add-in does this in a `finally` block after the exports, also when the job fails.
- `design.exportManager` (`createFusionArchiveExportOptions`, `createSTEPExportOptions`, `execute`) writes to the local path we pass and does not upload anything.
- Side effects: the new document becomes the active document, so the user sees a tab appear and disappear while a job runs. The user's own open documents are not modified or closed.

UNVERIFIED - check on a real install (each becomes a PR risk):

1. `doc.close(False)` on a never-saved document closes without a prompt, and nothing appears in the cloud project list or the "Recent" list afterwards.
2. `documents.add` does not trigger a "save to project" dialog or a cloud autosave for a new document (for example when the user has autosave or "save on close" prompts enabled).
3. `Application.preferences.generalPreferences.defaultModelingOrientation` exists, applies to `documents.add`, and the exported STEP is Z-up. If it does not apply, the equivalence check will report a rotated bounding box.
4. `design.designType = ParametricDesignType` can be set on a fresh document without a dialog. `design.fusionUnitsManager.distanceDisplayUnits` exists (only affects display; failure is logged as a warning).
5. `ProfileCurve.geometry` is in sketch space. (If not, the code retries as model space and logs `WARN`.) `geometry.evaluator.getParameterExtents/getPointAtParameter` work on all profile curve kinds.
6. Timeline/sketch/plane `name` accepts `/` (otherwise the code falls back to `_` and logs a warning; the Reify semantic name is then not preserved in Fusion).
7. `ExtentDirections` lives in `adsk.fusion`; `setOneSideExtent`, `setSymmetricExtent(distance, isFullLength=True)` (total length), `setAllExtent(SymmetricExtentDirection)`.
8. `CircularPatternFeatureInput` accepts `ValueInput.createByReal` for `quantity` and `totalAngle` (radians), and the pattern of a cut feature recomputes correctly.
9. `physicalProperties.volume` is cm^3 and the sum over `rootComponent.bRepBodies` is the solid volume after each feature.
10. `app.currentUser` / `app.isOffline` give a usable `signedIn`. These are read on the main thread only.
11. `app.fireCustomEvent` from a non-main thread is safe (documented as thread safe) and `registerCustomEvent` after an unclean shutdown needs the `unregisterCustomEvent` we do first.
12. The add-in runs on Fusion's bundled Python; only the standard library is used.
13. A custom-event handler that runs for a long time (a minute or more) does not make Fusion show "not responding" or kill the add-in.
14. Through-all cut with `setAllExtent` cuts all material on the chosen side only (sketch plane is the top face in the sample).

### New UNVERIFIED items for P2 and P3

15. `features.rectangularPatternFeatures.createInput(entities, axis, quantity, distance, SpacingPatternDistanceType)` accepts an origin construction axis and feature entities; a negative distance reverses the direction.
16. `features.mirrorFeatures.createInput(features, plane)` accepts origin planes and offset `ConstructionPlane`s for feature mirroring.
17. `sketch.sketchDimensions.addDistanceDimension / addRadialDimension / addDiameterDimension / addAngularDimension` signatures (point/entity, text position), `DimensionOrientations` enum names, and that setting `dimension.parameter.expression` to a parameter expression does not move the geometry. Dimensions on a point of a mirrored sketch, and `originPoint` use.
18. `holeFeatures.createSimpleInput / createCounterboreInput / createCountersinkInput`, `setPositionBySketchPoints`, `setAllExtent(direction)`, `setDistanceExtent`, `isDefaultDirection` (assumed: default direction is opposite to the sketch normal), `tipAngle` (assumed: 0 means flat bottom, 118 deg default). Hole depth semantics (to the full diameter shoulder) versus FreeCAD.
19. Cosmetic threads are not created at all (see Holes above). A real implementation needs `HoleFeatureInput` tapped-hole options and a check that the hole diameter is unchanged.
20. `filletFeatures.createInput().addConstantRadiusEdgeSet(edges, radius, isTangentChain=False)` and `chamferFeatures.createInput2().chamferEdgeSets.addEqualDistanceChamferEdgeSet(edges, distance, False)`. If Fusion propagates the fillet along tangent edges anyway, the volume check will show it.
21. `BRepEdge.geometry.objectType` strings (`adsk::core::Line3D`, `Circle3D`, `Arc3D`), `BRepEdge.evaluator.getPointAtParameter` at the parameter midpoint equals the arc-length midpoint, `BRepEdge.length` in cm, `BRepFace.geometry.objectType == "adsk::core::Plane"`, `BRepFace.area` in cm^2, `BRepBody.boundingBox`.
22. `sketches.add(BRepFace)` for a sketch on a tilted face, and that `modelToSketchSpace` on it maps as assumed. `ExtrudeFeatureInput.setOneSideToExtent(face, matchShape, offsetDistance, directionHint)` signature (we pass `directionHint` by keyword).
23. `design.userParameters.add(name, ValueInput, units, comment)` with `createByReal` in internal units (cm, radians) for `mm`/`deg` and with an expression string; Fusion's reserved names (we reject a short list in `params.RESERVED`); `createByString("thickness - 2 mm")` style expressions evaluate in the units we assume.
24. Material: `app.materialLibraries`, `design.materials.addByCopy`, the property id `structural_Density` and its unit (assumed kg/cm^3), assigning `body.material`.
25. Assemblies: `rootComponent.occurrences.addNewComponent(Matrix3D)` and `Matrix3D.setWithCoordinateSystem(origin, x, y, z)`; whether `sketch.modelToSketchSpace` inside an occurrence's component uses component-local space (assumed) or assembly space; whether features of different components stay independent in one parametric design; the single `.f3d` and the root STEP export contain all occurrences at their transforms.
26. A pattern of a hole feature in a component, and a mirror of a pattern feature, recompute without error.

## Verified in a live Fusion (2705.1.25)

Items 5, 7, 9, 14, 15, 16, 20, 21, 22 (sketch on a tilted face), 23 and 25 held. These did not, and the code now follows what Fusion does:

- Hole direction: a hole's default direction is opposite to the sketch normal, and `PositiveExtentDirection` means that default direction. `isDefaultDirection` follows the same rule (item 18).
- Flat drill point: `tipAngle` 180 deg. 0 is rejected (item 18).
- `ExtrudeFeatureInput` has no `setOneSideToExtent`. Pad up to a face uses `setOneSideExtent(ToEntityExtentDefinition.create(face, False), direction)` (item 22).
- A sketch created on a face can come with auto-projected reference curves. They are deleted, otherwise they become extra profiles.
- `BRepEdge.geometry` can be `None`. Such edges are skipped when matching edge references.
- A negative dimension expression flips the sketch geometry, so it is not bound.
- A rotation rounded to 6 decimals is rejected by `addNewComponent`; the frame is orthonormalized first.
- The midpoint of a full circle is where the kernel's seam is, so circle edge references match on centre, radius and axis.
- The equivalence check places cylinders and cones by axis, not by centroid, for the same reason.
- A part keeps its place in the assembly (an aircraft tail is 800 mm from the origin) and the new document's camera looks at the origin, so the add-in fits the view before it writes the .f3d. Otherwise the file opens on an empty canvas, and `fit` on it does nothing: a body saved without display graphics draws nothing until Fusion generates them. Fitting before the save generates them and stores them in the file (checked by importing the .f3d again: camera on the body, solid drawn).
- Fusion refuses a dimension on geometry it already holds in place (`VCS_SKETCH_OVER_CONSTRAINTS`): the second of two concentric circles, rectangles that line up with each other. The dimension is skipped with a warning; the equivalence check still proves the shape.

Still UNVERIFIED: items 1 to 4, 6, 8, 10 to 13, 17, 19, 24, 26.

How it was run: the "Fusion MCP Addin" `execute_api_script` tool, loading the add-in sources from a copy and calling `jobs.process_job` per fixture. That reproduces a job without restarting the add-in.

## Tests

`python3 -m unittest discover -s tests/fusion_addin -v` (plain `unittest`, no Fusion).
`tests/fusion_addin/fake_adsk.py` is a stub of the used `adsk.core` / `adsk.fusion` surface. It catches typos, call order, unit conversion and sign handling. It cannot prove that the real API has these members or behaves the same (see its docstring).

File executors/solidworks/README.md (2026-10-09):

# ReifyExport (SolidWorks executor)

`ReifyExport.exe` is a small .NET console program. The Reify desktop app starts it once per job. It reads the job folder
`<jobRoot>\solidworks\jobs\<jobId>\job.json` (protocol: `docs/cad-transfer/protocol.md`, sections 1 and 2), builds a native
SolidWorks part with feature history through the SolidWorks COM API, and writes into the same folder:
`part.SLDPRT`, `check.step`, `result.json`, `log.txt`.

```
ReifyExport.exe --version        prints: ReifyExport 0.1.0
ReifyExport.exe --check          prints: {"version":"0.1.0","swInstalled":true,"swVersion":"2023"}
ReifyExport.exe --job <dir>      runs one job; exit code 0 = ok, 1 = failed (result.json says why), 2 = bad arguments
```

## Status: NOT COMPILED, NOT RUN

The environment this was written in has no `dotnet` SDK and no SolidWorks (the SDK download host was blocked by the proxy).
Nothing here was compiled, no test was run, and no call was made against SolidWorks. The code was written carefully from
knowledge of the public SolidWorks API. Treat the first build on a Windows machine as the first compile, and the first
job as the first test of every API call listed under UNVERIFIED below.

## Layout

| Project | Target | Content |
| --- | --- | --- |
| `ReifyExport.Core` | net8.0, no Windows/SW dependency | JSON models, planner (validation, unit and plane math), `JobRunner`, `result.json` writer, log, CLI parsing, `--check` logic behind `ISwProbe`, watchdog |
| `ReifyExport` | net8.0-windows, x64 | `Program` (mutex, watchdog, COM STA thread), `SwPartBuilder` (all SolidWorks calls), `RegistrySwProbe`, `ComHelper` |
| `ReifyExport.Core.Tests` | net8.0, xunit | parsing of a sample canonical file, plan order, mm to m, direction logic, error mapping, runner with a fake builder, `result.json` shape, `--check` with a fake probe |

All sequencing and error handling is in `Core.JobRunner` and talks to SolidWorks only through `IPartBuilder`, so it is tested without SolidWorks.

## Build

Tests (any OS):

```
dotnet test executors/solidworks/ReifyExport.Core.Tests
```

Executor (Windows, SolidWorks installed, or the two interop DLLs copied somewhere):

```
dotnet publish executors/solidworks/ReifyExport -c Release -r win-x64 --self-contained false
# interop DLLs not in the default location:
dotnet publish executors/solidworks/ReifyExport -c Release -r win-x64 --self-contained false /p:SwApiDir="D:\sw\api\redist"
```

The project references `SolidWorks.Interop.sldworks.dll` and `SolidWorks.Interop.swconst.dll` by HintPath
(`C:\Program Files\SOLIDWORKS Corp\SOLIDWORKS\api\redist` by default, override with `/p:SwApiDir`). They are not in the repo.
The packaging step supplies them; `Private=true` copies them next to the exe. Requires the .NET 8 Desktop/Runtime on the
customer machine (framework-dependent publish) or switch to `--self-contained true` in packaging.

## Signing

Sign `ReifyExport.exe` (and the interop DLLs if the packaging policy requires it) in the desktop packaging step, with the same
Authenticode certificate as the desktop app:
`signtool sign /fd SHA256 /tr <timestamp-url> /td SHA256 /a ReifyExport.exe`.
An unsigned exe started from `%LOCALAPPDATA%` can trigger SmartScreen ("Windows protected your PC") or be blocked by AV or
AppLocker. SmartScreen reputation builds per certificate, so use the app's certificate rather than a new one.

## Minimum SolidWorks version: proposal 2022

Proposal only, not a tested bound. Reasons: the calls used (`FeatureExtrusion3`, `FeatureCut4`, `FeatureCircularPattern5`,
`ModelDocExtension.SaveAs3`, `InsertAxis2`) are all older than 2022, but the author could not run any version, so 2022 is a
recent, still widely deployed release that the lead can confirm or move after the first real run. `--check` reports the newest
installed year it finds, so the app can gate on it.

## How the plan works

- Planning happens completely before SolidWorks is touched. Anything unsupported stops the job with `result.json`
  `ok:false`, `error.code: "UNSUPPORTED_OP"`, `error.feature` = the feature (never skipped silently): unknown feature type,
  unknown sketch geometry (only line, arc, circle, polyline), open loops, loop depth >= 2, oblique extrusions, extents other than
  length / through_all, multiple bodies, polar pattern axes not parallel to a world axis or not through the origin.
- Units: JSON mm / degrees. The SolidWorks API takes meters / radians / m3 regardless of document units. All conversion is in
  `Units`. The document is also set to mm. Reported volumes are mm3.
- Coordinates: Z-up world coordinates are used unchanged as SolidWorks model coordinates (no rotation). Mapping (UNVERIFIED):
  `XY` -> Front plane (SW normal +Z), `XZ` -> Top plane (normal +Y), `YZ` -> Right plane (normal +X). Base planes are the first three
  `RefPlane` features of the new part by type order (Front, Top, Right in the default template).
- Offset planes: a frame origin off the base plane creates a distance reference plane; offset = dot(frame.origin, SW plane
  normal).
- Sketch points: world point (m) -> `Sketch.ModelToSketchTransform` -> sketch (x,y). The transform is authoritative. Checks:
  the transformed point must lie on the sketch plane (|w| < 1e-7 m) else `EXECUTOR_FAILED` (wrong plane order or offset sign);
  a predicted mapping (`SketchMath.ExpectedSketchCoords`) is compared and only logs a warning. Arc direction is derived from
  the sketch-space images of the canonical U and V axes, so a mirrored sketch frame still gives the same arc.
- Nested contours: all geometry of a canonical sketch is drawn into one SolidWorks sketch, the sketch feature is pre-selected
  and the extrude/cut is called. SolidWorks builds the regions from the contours. A depth-0 loop with depth-1 loops inside (plate
  with holes, pocket ring) matches the protocol's even-odd rule. Depth >= 2 (island inside a hole) is rejected with
  `UNSUPPORTED_OP`: a pocket with an island is a known limit.
- Directions: pad default = +sketch normal, cut default = -normal (UNVERIFIED, one constant: `PlanConventions.CutDefaultsToMinusNormal`).
  `Dir` (reverse) is set when the canonical `direction` differs from that default. `midplane` -> `swEndCondMidPlane`.
  `through_all` -> `swEndCondThroughAll`. A pad that adds no volume, or a cut that removes none, fails the job with a clear message,
  which also catches a wrong direction convention.
- Hole: see P3 below (Hole Wizard, with a cut-extrude fallback for plain holes).
- Polar pattern: reference axis from two base planes (`InsertAxis2`), then `FeatureCircularPattern5`, equal spacing for a full
  circle; partial angle uses spacing = angle / (n-1).
- After every feature the volume is read and written to `feature_volumes` (mm3).
- Semantic names are applied to sketches and features (`Feature.Name`), e.g. `bracket/base`.

## P2 and P3 additions (protocol sections 6 and 7)

All planning stays in `ReifyExport.Core` (`Planner`, `ExprParser`, `EdgeMatch`, `FaceMatch`, `AssemblyPlanner`, `TransformMath`), so everything except the actual SolidWorks calls is covered by xunit tests with a fake `IPartBuilder`.

- `linear_pattern`: `FeatureLinearPattern5`, direction = the reference axis of the world axis (axis-parallel directions only; `reversed` -> reverse flag). Spacing is checked against `length/(occurrences-1)`.
- `mirror`: `InsertMirrorFeature2`. Normal must be axis-parallel. The base plane is used when the plane passes through the origin, otherwise a distance reference plane is created. Tilted mirror planes are `UNSUPPORTED_OP`.
- Sketch `dimensions`: added after the geometry is drawn (AddToDB off) with `AddDimension2` / `AddHorizontalDimension2` / `AddVerticalDimension2` on selected segments or points. The measured value is compared with the canonical value (circle = diameter, arc = radius in SolidWorks) and never overwritten. Failure -> `EXECUTOR_FAILED`, step `sketch_dimension`, message names the sketch and the dimension. `distance_x`/`distance_y` need an axis-aligned sketch and are `UNSUPPORTED_OP` on tilted-face sketches. Polyline geometry cannot be dimensioned.
- Material: `material.density_kg_m3` is applied as a mass override (`MassProperty.OverrideMass = density x volume`). The SolidWorks material is NOT set. A warning is always added to `result.json warnings` saying so (setting `MaterialPropertyValues` by index was judged too risky without a real SolidWorks).
- Assemblies (`job.kind == "assembly"`): each part is built and saved as `<part name>.SLDPRT` in the job dir, then closed. A new assembly (default assembly template) is created and each part inserted with `AddComponent5`, then `Component2.Transform2` is set from a `MathTransform` built with `MathUtility.CreateTransform` (`TransformMath.ToSwArray`: 9 rotation values, translation in meters, scale, padding). The assembly is saved as `output.native` (`part.SLDASM`), the whole assembly goes to `check.step`. `files.extra` lists the per-part `.SLDPRT` names. `feature_volumes` has one entry per occurrence (the final volume of its part; a rigid placement does not change it). `features_built` counts features over all parts.
- Parameters: `parameters[]` become global variables (`"name" = 40mm`) through `EquationMgr.Add3`. A scalar with an expression in the protocol grammar (numbers, names, + - * /, parentheses, mm, deg) whose evaluated value equals the exported value is bound with an equation `"D1@<feature>" = ("width" / 2)`. Bound today: pad/pocket depth, fillet radius, chamfer size, linear pattern spacing, sketch dimension values. Everything else with an `expr` (hole dimensions, counterbore ...) keeps its value and gets a `warnings` entry. Any expression problem (outside the grammar, unknown name, value mismatch, bind failure in SolidWorks) is a warning, never a skipped feature.
- Hole: `HoleWizard5` on a position sketch made of points (blind/through, counterbore, countersink, drill point flat/angled, cosmetic thread -> Tap type). The Hole Wizard constants and the Value1..12 slot meaning are PLACEHOLDERS (class `Hw` in `SwPartBuilder.cs`): record a Hole Wizard macro on the target version and copy the numbers. If the call returns null and the hole is plain (no counterbore, countersink, thread or drill point) it falls back to circles + cut and adds a warning; otherwise the job fails.
- Fillet and chamfer: `EdgeMatch.Resolve` (curve type, midpoint, length; circles by centre and radius, because the seam differs between kernels) on the edges of the body BEFORE the feature, tolerance 1e-4 x part diagonal (diagonal from the body box). Zero or several matches -> `EXECUTOR_FAILED`, step `edge_match`, names the feature. The matched `Edge` is selected with `Entity.Select4`; fallback `SelectByID2("", "EDGE", point)` using the edge midpoint. `SelectByRay` is NOT used (deviation from the brief, because the entity handle is already known from the body traversal).
- Face references: `FaceMatch.Resolve` (planar, plane contains the point, normal parallel either sign, area within 1e-4 relative). Used for tilted-face sketches (sketch on the selected face; direction logic uses the face normal) and `up_to_face` (end condition `swEndCondUpToSurface` with the face selected with mark 1).
- Nesting depth 2 (island inside a hole) is still rejected with `UNSUPPORTED_OP`: it cannot be done with confidence without running SolidWorks.

### Final unsupported list (all reported as `UNSUPPORTED_OP` naming the feature, before SolidWorks is touched)

Feature types other than pad, pocket, hole, polar_pattern, linear_pattern, mirror, fillet, chamfer; sketch geometry other than line, arc, circle, polyline; open loops; loop depth >= 2; oblique extrusions; pad extents other than length / up_to_face, pocket extents other than length / through_all; midplane together with through_all / up_to_face / holes; more than one body; polar pattern axes not parallel to a world axis or not through the origin; linear pattern directions not axis-parallel; tilted mirror planes; modeled threads; counterbore together with countersink; hole sketches with anything but equal-diameter circles, or sharing a sketch with another feature; edge_ref curves other than line, circle, arc; sketch dimension kinds other than distance, distance_x, distance_y, radius, diameter, angle; `distance_x/y` on a tilted-face sketch; dimensions on polylines. Planning errors that are not unsupported constructs (bad schema, duplicate names, unknown sketch, bad refs, inconsistent pattern spacing, bad assembly transforms) are `EXECUTOR_FAILED` with step `plan`.

## Runtime behaviour and COM caveats

- Licensing: the exe drives the customer's own licensed SolidWorks. It cannot run without it. Nothing is redistributed except
  the interop DLLs from the `redist` folder.
- First export starts SolidWorks (slow, often 30 to 90 s, part of `timeoutS`). A running instance is reused. The executor never
  quits SolidWorks.
- Jobs are serialized with the named mutex `Global\ReifyExport.SolidWorks` (waits up to min(timeoutS, 60) s, then
  `error.code: "BUSY"`).
- Timeout: a watchdog starts after the lock is taken. On expiry it writes `result.json` `ok:false`,
  `EXECUTOR_FAILED`, message `timeout after N s` (with the current feature and step) and exits with code 1.
- Modal dialogs: SolidWorks blocks every COM call while a modal dialog is open (rebuild error, missing template, license
  prompt). The worker thread then hangs and only the watchdog ends the job. The executor sets `UserControl = false` and uses
  `CloseDoc` and silent save options to avoid prompts, but it cannot dismiss a dialog. After a timeout the document may stay open in SolidWorks and the user may have to
  close the dialog by hand.
- The executor runs on an STA thread (`[STAThread]`).
- `Marshal.GetActiveObject` does not exist on .NET 8, so `ComHelper` calls the OLE `GetActiveObject` directly.

## UNVERIFIED API usage (for the PR description)

Everything below was written without running SolidWorks or compiling.

1. SolidWorks classic interop assemblies (built for .NET Framework) loading and casting under net8.0-windows (expect NU1701 warnings).
2. Plane mapping XY/XZ/YZ -> Front/Top/Right, and that the first three `RefPlane` features are Front, Top, Right (also for customer templates).
3. `Sketch.ModelToSketchTransform` + `MathUtility.CreatePoint(double[])` + `MathPoint.MultiplyTransform` + `ArrayData` as written; predicted sketch axes (Front (x,y), Top (x,-z), Right (-z,y)).
4. `SketchManager.AddToDB` while drawing, `CreateLine`, `CreateCircleByRadius`, `CreateArc(..., short direction)` argument order and direction sign.
5. `model.FeatureByPositionReverse(0)` returns the sketch / axis feature just created (type names `ProfileFeature`, `RefAxis`).
6. `Feature.Name` accepts names containing `/`.
7. `FeatureManager.InsertRefPlane` argument meaning and the sign of the distance for offset sketch planes.
8. `FeatureExtrusion3` (23 args) and `FeatureCut4` (27 args) parameter order; meaning of `Dir` for cuts; default cut direction (-normal); `D1` = total depth for mid-plane; through-all with `Dir`; nested contours with the whole sketch pre-selected (`Select2(false, 0)`).
9. `ModelDoc2.InsertAxis2(true)` creating an axis from two selected planes; selection marks 1 (axis) and 4 (features) for `FeatureCircularPattern5` (14 args); equal-spacing semantics; partial-angle spacing.
10. `ModelDocExtension.CreateMassProperty()`, `MassProperty.UseSystemUnits`, `.Volume` in m3.
11. `ModelDocExtension.SaveAs3` signature with null `ExportData` / `AdvancedSaveAsOptions`; STEP export by file extension; `swUserPreferenceIntegerValue_e.swStepAP` = 214.
12. `ModelDocExtension.SetUserPreferenceInteger(swUnitsLinear, 0, swMM)`; `swApp.UserControl = false`; `swApp.Visible = true`; `NewDocument` with the default template string; `RevisionNumber()` format for the app string.
13. Registry layout for `--check`: `HKLM\SOFTWARE\SolidWorks\SOLIDWORKS <year>` sub keys and `HKCR\SldWorks.Application\CLSID`.
14. `CloseDoc(title)` using `GetTitle()` after save (title may carry the `.SLDPRT` extension).
15. (P2/P3) `FeatureLinearPattern5` argument list and direction handling (reference axis with unknown sign); `InsertMirrorFeature2(BMirrorBody, BGeometryPattern, BMerge, BKnit, ScopeOptions)` and selection marks 1 (features) and 2 (plane).
16. (P2) Sketch dimensions: `ModelDoc2.AddDimension2/AddHorizontalDimension2/AddVerticalDimension2` placement coordinates (sketch space), `DisplayDimension.GetDimension2(0)`, `Dimension.Name` setter, `Dimension.SystemValue` in SI, `SketchSegment/SketchPoint.Select4`, `SketchLine/SketchArc.GetStartPoint2/GetEndPoint2/GetCenterPoint2`, origin selection `SelectByID2("Point1@Origin","EXTSKETCHPOINT")`; circle dimensioned as diameter, arc as radius.
17. (P2) `MassProperty.OverrideMass` as the density mechanism and that it persists in the saved file.
18. (P2) Assemblies: `swDefaultTemplateAssembly`, `OpenDoc6` silent open before `AddComponent5`, `AddComponent5` arguments, `MathUtility.CreateTransform(double[16])` data layout (rotation row order, translation at 9..11, scale at 12), `Component2.Transform2` setter, `ActivateDoc3`, STEP export of an assembly through `SaveAs3`, closing the opened part docs after the assembly.
19. (P3) `EquationMgr.Add3(-1, equation, true, swAllConfiguration, null)`, global variable syntax with `mm`/`deg` suffix, dimension full names `D1@<feature>` for extrude depth, fillet radius, chamfer size and pattern spacing (the default dimension name `D1` is a guess), and that names containing `/` work in equations.
20. (P3) `HoleWizard5` (27 arguments, all constants and the Value1..12 slot use are placeholders), selection of a point sketch for it, cosmetic thread through Tap type.
21. (P3) `FeatureFillet3` (14-argument recorded form with Options 195) and `InsertFeatureChamfer(0, 4 = equal distance, size, ...)`.
22. (P3) Body queries: `PartDoc.GetBodies2`, `Body2.GetBodyBox/GetEdges/GetFaces`, `Edge.GetCurve`, `Curve.GetEndParams/Evaluate2/GetLength3/IsLine/IsCircle/CircleParams`, `Face2.GetSurface/Normal/GetArea` (m2), `Surface.PlaneParams` layout `[nx,ny,nz,px,py,pz]`, `Entity.Select4` on edges and faces, `SelectionMgr.CreateSelectData().Mark`.
23. (P3) Sketch on a selected planar face: the sketch normal equals the face's outward normal (the reverse flag logic relies on it), and `swEndCondUpToSurface` with a mark-1 face for a boss.
24. Not handled: the exported STEP is whatever SolidWorks writes; the equivalence check is done afterwards by the Reify sidecar with cadctl (`src/agent-api/transfer-check.ts`).

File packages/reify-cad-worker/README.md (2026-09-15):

# Reify CAD worker MCP

A local MCP server that delegates CAD/mechanical work to the existing Prime Agent + Pi-CAD runtime. It is a transport/control layer: it launches the long-lived Prime RPC session, keeps cwd stable, returns compact status/events, and exposes artifact handles. It does not add a second CAD API or return the full Prime transcript.

## Tools

- `cad_worker.start(cwd, workflow?, prompt?, model?, permission?)`
- `cad_worker.send(session_id, prompt)`
- `cad_worker.status(session_id)`
- `cad_worker.events(session_id, after?, limit?)`
- `cad_worker.artifacts(session_id)`
- `cad_worker.steer(session_id, instruction)`
- `cad_worker.interrupt(session_id)`
- `cad_worker.cancel(session_id, reason?)`
- `cad_worker.request_checkpoint(session_id)`
- `cad_worker.close(session_id)`

`USER_DECISION_REQUIRED` and `BLOCKED` are preserved rather than guessed away. `events` is bounded and cursor-based. Results expose Linux/WSL plus Windows UNC paths when the caller is Windows.

## WSL Codex

From the Pi-CAD checkout, register the local server:

```bash
repo=$(realpath .)
codex mcp add reify-cad-worker -- node "$repo/packages/reify-cad-worker/mcp.mjs"
codex mcp list
```

The host must have Pi-CAD runtime dependencies, `/usr/bin/bwrap`, Prime credentials/config, and a project directory. The worker resolves Prime from `$PRIME_AGENT_REPO` or `~/.prime/agent/prime-cad.json`. Defaults can be overridden with `REIFY_PI_CAD_REPO`, `REIFY_NODE`, `REIFY_WORKER_PROVIDER`, `REIFY_WORKER_MODEL`, and `REIFY_WORKER_THINKING`.

## Windows Codex

Use the Windows Node executable to start the WSL bridge. Replace the Linux user
and checkout path with paths that exist on your machine:

```powershell
$entry='\\wsl.localhost\Ubuntu\home\<linux-user>\pi-cad\packages\reify-cad-worker\mcp.mjs'
$wslEntry='/home/<linux-user>/pi-cad/packages/reify-cad-worker/mcp.mjs'
codex mcp add reify-cad-worker --env REIFY_WSL_DISTRO=Ubuntu --env "REIFY_WORKER_WSL_ENTRY=$wslEntry" -- node.exe $entry
codex mcp list
```

It converts the MCP entry and Windows project paths through `wsl.exe`, then runs the identical WSL server. Set `REIFY_WSL_DISTRO` if the distro is not `Ubuntu`. Set `REIFY_PI_CAD_REPO` to a native WSL Pi-CAD checkout/runtime for best performance. No Windows-side Pi-CAD process is created.
The `cad_worker.start` project directory must already exist. Use a WSL absolute
path or `\\wsl.localhost\Ubuntu\...` for `cwd`. Windows mapped drives such as
`V:\...` cannot be converted reliably; conversion errors return a clear MCP
argument error instead of passing the Windows path to Prime. If the WSL login
shell cannot find Node, add `--env REIFY_WORKER_WSL_NODE=/absolute/wsl/node/path`
to the Windows registration command.

## Local checks

```bash
node tests/reify-cad-worker.test.mjs
```

The test suite covers lifecycle/follow-up/cancel/close/stale IDs, compact context boundary, canonical blocker/resume, repeated-failure monitoring, same-session steering/interrupt, MCP catalog/call mapping, and host path policy.

## Windows entry variables

On Windows the bridge needs a native WSL Node path when the default shell cannot find one:

```powershell
$env:REIFY_WSL_DISTRO="Ubuntu"
$env:REIFY_WORKER_WSL_ENTRY="/home/<you>/pi-cad/packages/reify-cad-worker/mcp.mjs"
$env:REIFY_WORKER_WSL_NODE="/home/<you>/.local/lib/nodejs/node-v22.23.2-linux-x64/bin/node"
node .\packages\reify-cad-worker\mcp.mjs
```

If the package is checked out on `C:\`, only `REIFY_WORKER_WSL_NODE` normally needs to be set. The bridge converts Windows `cwd` arguments through `wslpath`; artifact results contain Windows UNC forms.

## Limitations and recommendation

Keep this worker local-only for now. Prime credentials, CAD project files, bwrap isolation, and long-running sessions assume a trusted local desktop/WSL boundary; a remote worker would need an authenticated service boundary, workload authorization, artifact transport, and reconnectable sessions.

Current limitations:

- `pause`/`resume` are not exposed; `interrupt` preserves the session, but Prime controls whether queued steering is accepted.
- `request_checkpoint` consumes one Prime turn.
- Windows→WSL transport, path conversion, status, artifact handles, and a real `mechanical.quick-build` delivery E2E were exercised.
- `mechanical.mechanism-design` is not in the current workflow catalog; callers choose the closest available workflow such as `mechanical.design`.
- MCP status uses a child Agent API read; simultaneous status calls are best kept modest.

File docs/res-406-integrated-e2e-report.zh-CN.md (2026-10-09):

# RES-406 集成端到端验证报告

## 本次基线与场景

验证分支基于已合并的 Pi-CAD `master`：`306a7f1544ba8052690927fa3bba5985c6f86ead`（RES-420 PR #56）。Prime 源码固定为 `dfaee8067c5def339d1ca0d7b9f3573bc86c948c`。inline 路径使用 Prime 的真实 faux provider 与独立子代理；Desktop 路径通过生产 RPC sidecar 启动 Prime。两条路径均要求父代理和子代理调用 Prime typed image 通道。

集成夹具要求两个子代理各自先构造错误尺寸的模型、Probe、修正并再次 Probe。子代理 A 构造嵌套装配，改变销参数、插入无语义名称的 spacer 并逆序输出；验证器按 `arm/pin_a`、`arm/pin_b`、`arm/pin_a/hole_axis`、`arm/bracket_left/rib_face`、`arm/bracket_left`、`arm/bracket_right` 语义路径解析实例、孔轴与面组，确认重新排序后位置和实例数量保持，销体积从约 125.664 mm³ 变为 282.743 mm³。另验证旧实体引用失效、将 v1 清单错配至 v2 STEP 时拒绝 Probe、删除命名特征时构建失败。

同一轮还运行了 21 个离散运动姿态的真实干涉 Probe：两端无碰撞，首个碰撞样本位于归一化位置 0.3，最大交叠体积约 8000 mm³；结果明确标记样本之间的区间未验证。碰撞 pose 上注入 Boolean common 失败，集成 Probe 取得 `interference facts are unresolved` 错误；故障没有被分类为 clearance/contact，也没有返回零碰撞。另由真实 probe worker 抛出异常并核实错误显式返回。10 姿态批处理读取一次目标 STEP，完成 10 项、0 跳过、0 错误。inline 运行中，10 次独立 STEP 导入耗时 0.0697 秒，一次导入加批处理耗时 0.0324 秒；Desktop RPC 分别为 0.0815 秒和 0.0348 秒，返回 7621 字节 JSON。这是两次单机同轮微基准，不是旧版本对合并版本的端到端 Agent 对比，不据此宣称跨版本收益。

子代理在完成态 `done` 后读取工作流状态并使用显式、哈希绑定的 v2 `ArtifactRef` 执行 Probe；状态仍为 `done`。命名 commit `named-assembly-evidence` 仅包含 v2 ArtifactRef。inline STEP SHA-256 为 `e3c4b04fd60d224d36b2b09e0f374046a1ee6bb3067dadb17b3cbc76f4167fec`，manifest SHA-256 为 `42c5de608a5138e6c91e7e01266cc292b81e2b0cfa7778fa54cf6a8974700cf8`。Desktop RPC STEP SHA-256 为 `6395f22afa212d4a77167130508dc1d7c4b9876803db163273a784aa712c6694`，manifest SHA-256 为 `91f0f3f845e46775b384dd622a0ebc775417650cea1458caf5d5e5d2c2f98044`。两者的 Blender bridge 均对同一个文件返回相同 STEP hash，且四个语义 occurrence 均可见。

## 固定种子 Chaos

`node scripts/chaos.mjs reify run --runs 1 --seed 406 --max-commands 8 --json` 通过。生成并执行 8 项序列：`startRun → commitPlan → advance(plan_ready) → killKernelChild → raceLegalOrderSwap → missingDesktopProjection → concurrentBuild → history`。`concurrentBuild` 同时生成两个真实 STEP 输出，形成 build/export 交错。`killKernelChild` 与 `raceLegalOrderSwap` 注入并恢复。`missingDesktopProjection` 标记为 `NotApplicable`，原因是该轮未附加 Desktop runtime。验证的不变量包括无孤儿 kernel、run 所有权、终态稳定、artifact 完整性、恢复收敛和故障结果如实记录。此单轮不代表所有故障种类或并发压力均已覆盖。

另用生产 Pi-CAD sidecar 启动 Prime daemon。父代理先建立 CAD run 和 STEP/Probe 证据，再启动目标与兄弟两个独立 RLM child。父代理通过 Prime hosted API `await rlm.delete_subagent(target)` 删除目标，没有增加 Desktop API，也没有从 daemon harness 直接取消。验证目标从 roster 消失、目标 Python kernel 退出；父 run、父 kernel PID namespace、STEP 路径/hash、Probe hash 均不变。兄弟 child 仍为 running，原 Python kernel 持续存活，随后完成 8 mm 立方体 build 与 Probe（体积 512 mm³，STEP SHA-256 `00b440e287aa652fd9468aa3c46d52cf7c39325be3521a65fc5bdb5b75dea9f1`）。父代理再启动 A2，A2 与被删除目标、兄弟和父任务拥有独立 canonical run。最近成功运行 ID：父 `v7-1790180425934-71c43f3b`，目标 `v7-1790180435401-8a617696`，兄弟 `v7-1790180435447-577e39a5`，A2 `v7-1790180445037-a3dfde15`；目标 child `sub-41e8a975`，兄弟 `sub-684ee71c`，A2 `sub-32b1812d`。文件读取器也会重试尚未完成写入的 JSON 标记。此场景通过 `tests/prime-daemon-subagent-cancel-smoke.mjs` 运行；它覆盖 Pi-CAD production sidecar + Prime daemon 控制面，不代表 Electron RPC 已切换为 daemon 模式。

最新 fixture 修改后，inline 与 Desktop RPC smoke 均重跑通过。inline 同件 STEP/manifest SHA 为 `1c4d8666467a5bad5aaa6ecf190f54c204fe503e555c69176b7a38d0e83908e1` / `4b04795caea1cd4fae044966d34c03e3e9f20ce9689df0876ea1f18dc4ad00d6`；Desktop RPC 为 `f693b984d3dcf1201421d410d80457604ab6c5ec85655dd226e615016c8779ee` / `7121305430d8211f0fdcfc2f03f078b6d3af175e7979d1e3bb90e1eb540b9b20`。两条 bridge 都以各自当前 STEP hash 返回四个命名 occurrence、7 个对象；几何负例和 fail-closed 断言仍通过。

## 运行命令与状态

- `PRIME_AGENT_REPO=.scratch/res406/prime-agent-main PRIME_AGENT_KERNEL_VENV=.scratch/res406/prime-kernel-venv node tests/prime-subagent-smoke.mjs`：最新 fixture 复跑通过，含 Blender bridge 同件校验。
- `PRIME_AGENT_REPO=.scratch/res406/prime-agent-main PRIME_AGENT_KERNEL_VENV=.scratch/res406/prime-kernel-venv node tests/prime-desktop-rpc-subagent-smoke.mjs`：最新 fixture 复跑通过；隔离 parent/child/grandchild run、child 故障恢复、adoption 与 Blender bridge 同件 hash 检查通过。
- `PRIME_AGENT_REPO=.scratch/res406/prime-agent-main PRIME_AGENT_KERNEL_VENV=.scratch/res406/prime-kernel-venv node tests/prime-daemon-subagent-cancel-smoke.mjs`：通过；经 hosted `rlm.delete_subagent` 删除目标、父状态/产物不变、目标 kernel 终止、兄弟 kernel 继续完成 build/Probe、四个 canonical run 独立。
- `node scripts/chaos.mjs reify run --runs 1 --seed 406 --max-commands 8 --json`：通过。
- `npm run check:agent-contract`：通过。TypeScript harness：417 项，416 通过、1 跳过、0 失败（Toxiproxy 未安装）。Desktop Vitest：28 文件、217 项通过。Python unittest：214 项通过、7 项跳过、0 失败（385.183 秒）。两条 Prime smoke 也在更新后的 fixture 上通过，含孔轴/面组语义解析、Boolean fail-closed 注入和 probe worker 异常。

最新本分支 CI run `35881301148` 在 TypeScript harness 的 `tests/reify-cad-worker.test.mjs` 失败：该测试用固定 20 ms 等待模拟的 recovery turn，随后读取到 `progressing`，预期为 `idle`。本地复跑该文件通过；测试已改为有上限地等待假 Prime 状态归回 `ready`，修复后的最新 head CI 尚待重跑。旧 head `a62ab9fd` 的 required CI 曾通过，但不替代最终 head 验证。完整 Agent 级基线与合并版本的配对 KPI 尚未取得，因此不报告端到端时延或成功率差异。

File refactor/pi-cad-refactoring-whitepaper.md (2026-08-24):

# Pi-CAD 0.9 Architecture Refactoring White Paper

> Status: vision document. Phase numbering and implementation details
> follow `pi-cad-engineering-design-v2.md` (Phase 0-8). Where the two
> documents disagree, the engineering design document wins.

## Code-defined agent operation (2026-08 contract revision)

Pi-CAD's agent-facing architecture is now an explicit pipeline:

```text
Code-defined Agent Contract
→ generated skill references
→ current-state action card
→ cookbook-guided authoring
→ immutable Observation
→ indexed optional detail reads
```

Tool catalogs, phase grants, route transitions, and obligations are projected
into a schema-1 `AgentContract`; generated references and the machine contract
are checked for drift. Runtime state is not copied into prose: every turn gets
an authoritative action card with current write scope, tools, obligations,
bindings, legal events, recovery recommendation, and only genuinely ready
managed runtimes. Normal operation does not inspect implementation source.

Observation context is bounded while meaning is not. Each Probe or indexed
Simulation result stores one immutable compressed payload and a summary/catalog
snapshot. Large face, occurrence, interference, table, array, and log
collections are pageable with query-bound cursors. Storage-quota failure is
explicit; detail is never silently truncated. Backend/version-specific
cookbooks and executable assets teach solver authoring while Core remains
physics-agnostic and Simulation Evidence remains explicit-commit only.

## From CAD Agent Tool Collection to CAD Engineering Runtime

## 1. Motivation

Pi-CAD has already shown that practical CAD agents require more than
geometry generation. The core challenge is maintaining engineering
process state, design intent, evidence, and context over long workflows.

The refactoring goal is not to add more tools. It is to establish stable
engineering abstractions:

-   Control decides what must happen.
-   Modules decide how engineering work is executed.
-   Observation decides what the agent sees.
-   Context decides what the agent remembers.

## 2. Current Architecture Assessment

The current repository already contains strong foundations:

-   route-based workflow compilation;
-   phase-based mutation control;
-   obligation and evidence systems;
-   candidate generation and automatic review;
-   context memory and compaction.

The main limitations are:

1.  Tool surface grows with every capability.
2.  Workflow logic is coupled to backend implementations.
3.  Raw tool outputs are not separated from agent observations.
4.  Visual engineering context is not treated as a first-class runtime
    object.

## 3. Target Architecture

Pi-CAD evolves into four layers.

### Control Plane

Responsible for:

-   route;
-   workflow compilation;
-   phase contracts;
-   obligations;
-   acceptance;
-   state transitions.

This is the CAD-specific intelligence of Pi-CAD.

### Context Runtime

Responsible for:

-   canonical state;
-   working context;
-   archive;
-   compaction;
-   observation memory.

### Capability Modules

The agent-facing engineering capabilities become:

-   MODEL
-   PROBE
-   SIMULATE

### Observation Layer

All backend outputs are normalized into:

-   primary visuals;
-   key facts;
-   diagnostics;
-   provenance.

## 4. MODEL Module

MODEL creates engineering artifacts.

The current build123d flow becomes a backend adapter.

Future backends:

-   CadQuery;
-   OpenCascade;
-   FreeCAD.

All produce a common artifact contract.

MODEL creates candidates but does not decide acceptance.

## 5. PROBE Module

PROBE replaces many inspection tools with one programmable observation
interface.

Agent-facing API:

cad_probe

Internal presets:

-   visual;
-   geometry;
-   measurement;
-   section;
-   comparison;
-   assembly;
-   interference.

Advanced cases use programmable Python composition.

The principle:

Small interface, large implementation.

## 6. SIMULATE Module

Simulation becomes a unified engineering experiment layer.

Presets include:

-   structural FEA;
-   CFD;
-   thermal;
-   optimization.

The lifecycle:

specification -\> frozen inputs -\> solver -\> results -\> observation.

Simulation output follows visual-first ordering:

1.  engineering images;
2.  convergence;
3.  statistics;
4.  artifacts.

## 7. Control Plane Refactoring

Introduce PhaseContract.

A phase defines:

-   allowed capabilities;
-   required records;
-   required evidence;
-   valid decisions;
-   automatic transitions.

The workflow compiler produces contracts. The state machine executes
them.

## 8. Migration Roadmap

### Phase 1: Observation Foundation

Introduce:

-   ObservationBundle;
-   ObservationRenderer;
-   ObservationProfile.

No behavior change.

### Phase 2: Probe Registry

Move existing inspection implementations behind a common registry.

Existing tools become compatibility wrappers.

### Phase 3: Unified cad_probe

Expose:

-   preset queries;
-   programmable probe execution.

Keep canonical design immutable.

### Phase 4: Candidate Finalizer

Separate MODEL execution from candidate review.

Preserve current commit workflow.

### Phase 5: Simulation Module

Unify solver lifecycle.

### Phase 6: Phase Contract Compiler

Replace phase-specific tool lists with capability grants.

### Phase 7: Context Runtime Enhancement

Add observation index and visual rehydration.

## 9. Final Vision

Pi-CAD should not become an LLM with many CAD tools.

It should become:

A CAD engineering runtime that provides a controlled engineering process
around programmable computational modules.

The final architecture:

Control Plane + Context Runtime + Observation Layer + MODEL / PROBE /
SIMULATE

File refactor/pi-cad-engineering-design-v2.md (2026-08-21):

# Pi-CAD Refactoring Engineering Design Document v2

> Implementation status (branch `refactor/runtime-v2`): Phases 0–8 are
> implemented. Phase 3's old-tool retirement remains gated on a fuller
> agent-level benchmark campaign; legacy inspection tools stay as
> deprecated wrappers until then. See `refactor/review-and-plan.md` for
> the review that produced this plan.

## Title

Deep Module Architecture Migration Plan

From CAD Tool Collection to CAD Engineering Runtime

------------------------------------------------------------------------

# 1. Purpose

This document defines the engineering implementation plan for the next
major Pi-CAD architecture evolution.

The objective is not to add more CAD APIs.

The objective is to separate:

-   engineering process control;
-   computational capability;
-   observation;
-   context management.

The target architecture is:

Control Plane + Context Runtime + Observation Layer + MODEL / PROBE /
SIMULATE modules

------------------------------------------------------------------------

# 2. Current Repository Architecture Assessment

## 2.1 Existing strengths

Pi-CAD already contains several mature architectural ideas.

### Workflow compiler

The workflow compiler maps engineering intent into a process graph.

It already understands:

-   greenfield design;
-   legacy modification;
-   hybrid workflows;
-   assembly design;
-   manufacturing and release maturity.

The route ontology should remain.

------------------------------------------------------------------------

### State machine

The state machine currently owns:

-   phase transitions;
-   mutation authority;
-   candidate acceptance;
-   evidence requirements;
-   project head updates.

This should remain the authority layer.

------------------------------------------------------------------------

### Evidence and provenance

Artifacts are already associated with:

-   hashes;
-   evidence records;
-   simulation specifications;
-   solver results.

This becomes the foundation of future module boundaries.

------------------------------------------------------------------------

### Context memory

The context runtime already separates:

-   canonical state;
-   working context;
-   archived trajectory;
-   compaction lifecycle.

Future work should extend observation memory rather than replace it.

------------------------------------------------------------------------

# 3. Main Architectural Problems

## 3.1 Capability explosion

Current Agent tools expose implementation details.

Examples:

-   geometry inspection;
-   measurement;
-   sections;
-   surface analysis;
-   visual inspection;
-   simulation variants.

This creates tool-selection burden.

The Agent should reason about engineering actions, not backend APIs.

------------------------------------------------------------------------

## 3.2 Backend coupling

Today the candidate workflow knows too much about build execution.

A future CAD backend should not require a new workflow.

The dependency should become:

Workflow

depends on

MODEL interface

which depends on

Backend adapter.

------------------------------------------------------------------------

## 3.3 Observation is not a first-class abstraction

Backend output is not the same as useful Agent context.

The system needs a dedicated layer that decides:

-   what image should be shown;
-   what facts matter;
-   what diagnostics are useful;
-   what should be remembered.

------------------------------------------------------------------------

# 4. Target Module Architecture

## 4.1 Control Plane

The control plane is Pi-CAD's unique value.

Responsibilities:

-   route selection;
-   workflow compilation;
-   phase contracts;
-   obligations;
-   acceptance;
-   state transitions.

The control plane should never depend on:

-   build123d;
-   CadQuery;
-   solver implementation.

------------------------------------------------------------------------

## 4.2 Context Runtime

Responsibilities:

-   maintain engineering memory;
-   rebuild working context;
-   preserve failed attempts;
-   manage observation history.

Future additions:

-   observation index;
-   visual hydration;
-   phase-specific memory policy.

------------------------------------------------------------------------

## 4.3 MODEL

Purpose:

Produce engineering artifacts.

Input:

-   source;
-   backend;
-   execution context.

Output:

CandidateProposal.

MODEL does not decide:

-   acceptance;
-   review;
-   evidence closure.

------------------------------------------------------------------------

## 4.4 PROBE

Purpose:

Answer deterministic questions about artifacts.

Agent-facing interface:

cad_probe

Internal implementation:

Preset Registry.

Existing tools become presets:

-   visual;
-   geometry;
-   measure;
-   section;
-   compare;
-   assembly;
-   interference.

Advanced usage:

programmable Python composition.

------------------------------------------------------------------------

## 4.5 SIMULATE

Purpose:

Run controlled engineering experiments.

Presets:

-   structural analysis;
-   CFD;
-   thermal;
-   optimization;
-   analysis-model derivation.

------------------------------------------------------------------------

## 4.6 Existing Tool to Module Mapping

This table is the authoritative migration baseline. Every agent-visible
tool in `src/shared/protocol.ts` must have exactly one destination.

| Current tool | Destination | Note |
| --- | --- | --- |
| cad_route, cad_reroute | Control Plane | unchanged |
| cad_commit_requirements / frame_context / plan / assembly_design / interface_contracts | Control Plane | unchanged |
| cad_commit_candidate | Control Plane (Candidate Finalizer) | split in Phase 4, behavior byte-compatible |
| cad_transition, cad_wait_for_user, cad_finish | Control Plane | unchanged |
| cad_build_step | MODEL | build123d backend, Phase 5 |
| cad_inspect_visual | PROBE preset `visual` | Phase 2 |
| cad_inspect_geometry, cad_inspect_surfaces | PROBE preset `geometry` | Phase 2 |
| cad_inspect_section, cad_scan_sections | PROBE preset `section` | Phase 2 |
| cad_measure | PROBE preset `measure` | Phase 2 |
| cad_compare_geometry | PROBE preset `compare` | Phase 2 |
| cad_assembly_tree | PROBE preset `assembly` | Phase 2 |
| cad_inspect_interference | PROBE preset `interference` | Phase 2 |
| cad_probe_python | PROBE programmable mode | absorbed by unified cad_probe, Phase 3 |
| cad_simulate / cad_simulate_flow / cad_simulate_thermal | SIMULATE presets structural / flow / thermal | Phase 6 |
| cad_optimize | SIMULATE preset `optimize` | folds in, Phase 6 |
| cad_derive_analysis_model | SIMULATE preset `derivation` | MODEL-to-SIMULATE bridge, Phase 6 |
| cad_export | MODEL deliverable preset `export` | Phase 5/6 |
| cad_generate_drawing | MODEL deliverable preset `drawing` | Phase 5/6 |
| cad_render_scene | MODEL deliverable preset `render` | Phase 5/6 |

Deliverable generation (export / drawing / render / presentation) stays
inside MODEL as deliverable presets. It does not become a fourth module.

Simulation lifecycle:

1.  validate specification;
2.  freeze inputs;
3.  execute backend;
4.  collect results;
5.  produce observation;
6.  optionally create evidence.

------------------------------------------------------------------------

# 5. Core Interface Design

## 5.1 Artifact Contract

All modules communicate through ArtifactRef.

Required fields:

-   path;
-   hash;
-   representation;
-   role;
-   producer.

No module should exchange backend-native objects.

------------------------------------------------------------------------

## 5.2 Observation Bundle

All outputs should normalize into:

ObservationBundle

Contains:

-   visuals;
-   headline;
-   facts;
-   diagnostics;
-   provenance;
-   artifacts.

The Agent sees observations, not raw backend output.

------------------------------------------------------------------------

## 5.3 Phase Contract

Each workflow phase should compile into:

PhaseContract

Contains:

-   available capabilities;
-   required records;
-   required evidence;
-   valid decisions;
-   automatic observations;
-   context profile.

------------------------------------------------------------------------

## 5.4 Envelope vs Bundle Layering

`CadEventEnvelope` (and its payload types) is the wire contract between
the TypeScript runtime and `python -m cadctl`. It stays unchanged in
shape and is NOT the agent-facing surface.

`ObservationBundle` is the agent-facing rendering of an envelope (or of
a composition of envelopes).

The Observation Layer owns exactly this mapping:

    envelope (wire) -> ObservationBundle (agent rendering)

No tool should return an envelope directly to the agent after Phase 1.
No module should speak bundles to the Python side.

------------------------------------------------------------------------

# 6. Migration Strategy

## Phase 0: Freeze Behavior

Before refactoring:

-   add golden tests;
-   record current workflow behavior;
-   preserve state semantics.

Golden scope (must be pinned before any later phase merges):

-   `compileWorkflow()` output for every Route (full CompiledProcess
    snapshot);
-   `toolsForPhase()` and `mutationPolicyForPhase()` matrix over every
    phase and route;
-   state machine transitions / acceptance / evidence semantics (regression
    floor: existing tests plus new golden cases);
-   one archived CADTestBench + internal stratified benchmark run as the
    agent-level baseline.

Snapshots are checked in. Any intentional drift in later phases requires
an explicit review of the golden diff. No user-visible change.

------------------------------------------------------------------------

# Phase 1: Observation Layer

Implement:

-   ObservationBundle;
-   ObservationRenderer;
-   ObservationProfile.

Convert existing tool outputs.

Do not change tools yet.

------------------------------------------------------------------------

# Phase 2: Probe Registry

Create:

ProbeModule

Move existing implementations:

-   geometry;
-   measure;
-   section;
-   compare;
-   assembly;
-   interference.

Old tools become wrappers.

------------------------------------------------------------------------

# Phase 3: Unified cad_probe

Expose one Agent-facing observation tool.

Support:

-   preset mode;
-   programmable composition mode.

Keep design artifacts immutable.

Deliverables (frequently underestimated, must be planned):

-   rewrite every phase prompt in `src/prompts/` that references an
    inspection tool by name;
-   old inspection tools become deprecated wrappers (marked in their
    descriptions) until retirement;
-   benchmark gate: run the stratified benchmark before and after;
    success rate and token cost must not regress before old entry points
    are retired.

------------------------------------------------------------------------

# Phase 4: Candidate Finalizer

Split:

MODEL execution

from

candidate review lifecycle.

Current cad_commit_candidate behavior remains.

------------------------------------------------------------------------

# Phase 5: Model Backend Adapter

Introduce:

ModelBackend interface.

First backend:

build123d.

Future:

-   CadQuery;
-   OpenCascade.

Adding a backend should not modify workflow code.

------------------------------------------------------------------------

# Phase 6: Simulation Module

Extract shared simulation lifecycle.

Convert:

-   structural;
-   CFD;
-   thermal;

into backend adapters.

------------------------------------------------------------------------

# Phase 7: Control Plane Refactor

Introduce PhaseContract compiler.

Replace:

phase -\> tool names

with:

phase -\> capability permissions.

------------------------------------------------------------------------

# Phase 8: Context Runtime v2

Add:

-   observation index;
-   visual retention;
-   context hydration.

Goal:

After compaction, the Agent can recover the important engineering visual
state.

------------------------------------------------------------------------

# 7. File Migration Plan

## Existing files to preserve

src/core/state-machine.ts

Role:

control authority.

------------------------------------------------------------------------

src/workflows/compiler.ts

Role:

route to process compilation.

------------------------------------------------------------------------

src/shared/protocol.ts

Role:

canonical schemas.

------------------------------------------------------------------------

src/shared/store.ts

Role:

artifact/state persistence.

------------------------------------------------------------------------

src/core/context-memory.ts

Role:

context lifecycle.

------------------------------------------------------------------------

## Existing files with a migration destination

src/core/controller.ts (largest file in the repo)

Gradually migrates into src/control/control-engine.ts during Phase 4
(candidate finalizer split) and Phase 7 (phase contracts).

------------------------------------------------------------------------

src/core/policies.ts

Becomes a PhaseContract data source in Phase 7. toolsForPhaseBase()
switch is replaced by capability grants compiled from contracts.

------------------------------------------------------------------------

src/core/runtime.ts

Tool gating moves to capability grants (Phase 7); the tool_call guard
stays.

------------------------------------------------------------------------

src/prompts/ (28 phase prompt files)

Rewritten in Phase 3 when cad_probe replaces the inspection tools.

------------------------------------------------------------------------

python/cadctl/

Python side of the backend adapter boundary (Phase 5). The cadctl CLI
subcommand contract becomes part of the ModelBackend protocol.

------------------------------------------------------------------------

## Files to introduce

src/control/

-   phase-contract.ts
-   control-engine.ts

src/modules/model/

-   registry.ts
-   backend.ts
-   finalizer.ts

src/modules/probe/

-   registry.ts
-   runtime.ts
-   presets/

src/modules/simulate/

-   registry.ts
-   lifecycle.ts

src/observations/

-   bundle.ts
-   renderer.ts
-   profiles.ts

------------------------------------------------------------------------

# 8. Testing Strategy

## Contract tests

Every backend must prove:

-   deterministic output;
-   correct provenance;
-   correct artifact binding.

------------------------------------------------------------------------

## Workflow equivalence tests

Verify:

-   phase graph;
-   obligations;
-   transitions;
-   acceptance behavior.

------------------------------------------------------------------------

## Observation tests

Verify:

-   visual priority;
-   stable summaries;
-   artifact references.

------------------------------------------------------------------------

## Regression benchmark

Maintain:

-   CADTestBench regression;
-   complexity-stratified internal benchmark.

Measure:

-   exact success;
-   requirement satisfaction;
-   observation usage;
-   token cost;
-   runtime.

------------------------------------------------------------------------

# 9. Final Design Philosophy

The final Pi-CAD should not be:

An LLM connected to many CAD tools.

It should be:

A CAD engineering runtime.

The core separation is:

Control decides what is allowed and required.

Modules decide how engineering computation is performed.

Observation decides what the Agent understands.

Context decides what the Agent remembers.

This architecture allows:

-   unlimited backend expansion;
-   strict engineering process control;
-   lower cognitive burden;
-   stronger long-horizon CAD reasoning.

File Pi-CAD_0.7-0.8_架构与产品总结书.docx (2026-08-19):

Pi-CAD 0.7 → 0.8

架构与产品总结书

从“能生成 CAD”到“真实工程闭环”

核心命题

Agent 的核心不是几何生成器，而是一个强但不稳定的逆解器。Pi-CAD 的职责不是替它“变聪明”，而是通过 Context Constructor + Interpreter，把问题定义、执行边界、现实观测与证据闭环组织正确。

基线：Pi-CAD 0.7 · commit c12c0fab96a7fecb250ada7222452577646d17b5

整理日期：2026-08-19

# 使用说明

本文不是 README，也不是实现细节清单，而是一次阶段性“架构冻结 + 产品方向”总结。它整合了当前 0.7 已落地的能力、真实使用中暴露的体验缺陷，以及下一版围绕路由、装配、物理可实现性与发布交付的设计。

建议用途：作为 0.8 设计输入、实现 handoff、benchmark 设计依据，以及后续 GUI / workflow compiler / assembly interpreter 的共同语义基线。

## 目录

- 1. 当前结论与冻结原则
- 2. Pi-CAD 0.7 当前状态
- 3. 真实使用暴露的三个体验缺陷
- 4. 现有 Workflow 的结构性问题
- 5. Router V2：从“选路径”到“描述问题”
- 6. Workflow Compiler：把正交维度编译成流程
- 7. Part 与 Assembly 的不同设计过程
- 8. Reroute：只能增加义务，不能授予进度
- 9. Physical Realizability：干涉、装配与真实性
- 10. Analysis Model 与 Authoritative Design 分离
- 11. Release Presentation：Blender 成为正式交付链
- 12. Inspect / Section 当前能力与演进
- 13. Tools / Skills / Harness 的职责边界
- 14. 0.8 推荐实现顺序
- 15. 验收矩阵与 Benchmark
- 16. 最终架构图与决策冻结

# 1. 当前结论与冻结原则

一句话结论

0.7 已证明 Pi-CAD 可以把真实 CAD、结构仿真与 SU2 热流体求解统一成“canonical spec → deterministic interpreter → hash-bound evidence”。0.8 不应继续堆 feature，而应首先修正 Agent 所看到的问题结构：更好的 Router、更像人类工程师的 Assembly 设计流程、更严格的 Physical Realizability，以及 Release 级 presentation。

## 1.1 不变的核心边界

- Tools expose reality：工具是传感器/执行器，只给确定性事实，不做工程判断。
- Agent interprets reality：需求、架构、接口、物理含义与最终工程判断都属于 Agent。
- Workflow defines process：流程定义当前逆问题应该如何被分解。
- Harness enforces workflow：Harness 负责状态、权限、证据义务、版本绑定与闭环，不理解 Mach、应力或“这个设计好不好”。
- Skills improve reasoning：Skill 只编码特殊 policy / recurring correction，不做百科全书。

## 1.2 更高层理论

Harness = Context Constructor + Interpreter

Context Constructor: 决定模型此刻看到什么问题、什么历史、什么证据与约束
Interpreter: 把模型的语义输出落地成世界操作，并把世界结果翻译回可用语义

新的 Router / Workflow Compiler 本质上属于 Context Constructor；SU2、OCP、Gmsh、Blender、干涉检测、截面分析属于 Interpreter。

# 2. Pi-CAD 0.7 当前状态

截至本总结，仓库主线最新基线为 c12c0fab。0.7 已经形成了可工作的工程解释器骨架，而不是只会输出 STEP 的 CAD agent。

层 | 已落地能力 | 关键性质
Harness | Project/Run lifecycle、phase policy、tool overlay、evidence guards | 流程状态与工程语义分离；Pi-CAD 只管理自身 cad_* 工具
Evidence | artifactHash / subjectArtifactHash、inputArtifacts、FrozenInputs | 当前版本绑定；输入/输出可重验；求解中篡改会 discard
CAD | build123d → STEP、visual、geometry、surface selectors、measure、section、compare、assembly tree | 确定性观察；不做“好/坏”判断
Structural | torch-fem 结构仿真 + topology optimization skeleton | simulation 是横向 capability，不是独立 workflow
Thermal/Fluid | SU2 8.5.0：steady flow / solid heat conduction walking skeleton | 显式 units / viscosity / BC；not_converged 不生成 evidence
Packaging | drawing / export / presentation placeholder | release 工作流已有结构，但 presentation 仍不完整

## 2.1 0.7 最重要的工程证明

- 真实 nozzle CFD：canonical FlowSpec 被编译为 SU2 case，结果回译为 Mach / pressure / temperature / mass-balance evidence。
- 真实 thermal slab：导热结果可与 q = kAΔT/L 解析解对比。
- 收敛性属于执行有效性：未达到 residualTarget 的 run 可返回 raw fields 供诊断，但不能关闭 required case。
- Opaque simulation cases：Harness 只认 artifact + tool + caseId，不理解 CFD/FEA 语义。
- FrozenInputs：provenance 在 invocation 开始时冻结，结束后只验证，不重新定义。

# 3. 真实使用暴露的三个体验缺陷

体验问题 | 表象 | 根因 | 应修位置
Agent 偷懒 | 倾向做“看起来像”的 prototype / concept，而不是可制造、可装、可工作 | 终局条件太宽；maturity 只是标签，accepted evidence 主要仍是 visual + geometry | Context / obligations
设计顺序不对 | 复杂装配直接一口气生成成“一坨装配体” | greenfield 只有 concept → intent → build，缺 assembly / interface / part 分解 | Context / workflow
对干涉不敏感 | 穿模、重叠、异常装配未被明显发现 | 当前没有 deterministic interference sensor；assembly_tree 只给 hierarchy/transform | Interpreter

## 3.1 “Prototype”必须重新定义

Reality Floor

对于物理 CAD 任务，默认底线是 REAL / BUILDABLE / FUNCTIONAL。只有用户明确要求概念模型、示意几何或 mockup 时，才允许非真实设计。

推荐 maturity 语义：

- prototype：真实可制造、可装、可工作；允许非最终材料、较宽容差、简化外观与不完整生产文档。
- engineering：接口、材料、配合、零件、关键尺寸、装配方法与关键分析明确。
- manufacturing：增加制造定义、图纸、工艺、检验与可制造性 closure。
- release：在 manufacturing 之上增加 BOM、配置、装配服务、最终交付包与 presentation。

“concept”不再作为 maturity。它是设计过程中的 phase。

# 4. 现有 Workflow 的结构性问题

当前七条 workflow 把不同维度混成一个平面 enum。Agent 被要求在不互斥的选项中“选一条路”，这天然丢失信息，也给 quick 提供了逃生出口。

现有 workflow | 它实际上表达的维度 | 保留方式
quick | 执行捷径 / process depth | 删除；fast path 由 compiler 自然缩短
greenfield | lineage | 保留为 lineage=greenfield 的 process fragment
modify | lineage / change mode | 改写为 lineage=legacy
hybrid | lineage | 保留为 lineage=hybrid
analyze | task objective | 基本原样保留为 objective=analyze
convert | task objective | 基本原样保留为 objective=convert
release | maturity / delivery level | 变成 maturity=release overlay

## 4.1 当前流程为何会诱导捷径

quick: requirements → build → review → ready
greenfield: requirements → concept → intent → build → review
modify: requirements → baseline → plan → modify → review
hybrid: requirements → baseline → concept → intent → build → review
release: requirements → audit → gap_closure → package → final_review

“greenfield release assembly”在现实上同时属于 lineage=greenfield、structure=assembly、maturity=release；当前体系却只能在 greenfield 与 release 中二选一。因此 release 的义务无法自然叠加到设计主线。

# 5. Router V2：从“选路径”到“描述问题”

Router 新定义

Routing defines the problem, not the shortcut. Agent 不再选择一个完整 workflow；它只描述任务的正交属性，Harness 再编译出实际流程。

type Route =
| { objective: "analyze" }
| { objective: "convert" }
| {
objective: "design";
lineage: "greenfield" | "legacy" | "hybrid";
structure: "part" | "assembly";
maturity: "prototype" | "engineering" | "manufacturing" | "release";
};

## 5.1 Router 的层次化判断

1. Objective：这是 design、analyze 还是 convert？
2. Lineage（仅 design）：greenfield、legacy 还是 hybrid？
3. Structure：最终 deliverable 是单件还是装配？
4. Maturity：原型、工程、制造还是发布？

这几步可以在同一 agent turn 连续完成，不意味着每一步都要向用户提问；Harness 只是让每次 semantic decision 的问题更干净。

## 5.2 Fast path 仍然存在，但不再由 Agent 选择

删除 quick 不代表所有任务都变慢。一个完全约束的简单单件可以由 compiler 自动得到：

design / greenfield / part / engineering
→ requirements → part_design → build → review

而复杂 assembly 则自动得到更长流程。关键区别是：fast path 是问题结构的结果，而不是 Agent 的权限。

# 6. Workflow Compiler：把正交维度编译成流程

建议保留现有 WorkflowSpec / state-machine execution engine，替换 workflow definition mechanism：

旧： state.workflow → WORKFLOW_SPECS[state.workflow]
新： state.route → compileWorkflow(state.route) → CompiledProcess

## 6.1 Compiler 的三类输入

输入维度 | 贡献内容 | 示例
Lineage fragment | 决定是否需要 baseline、architecture exploration、compare / retained constraint | legacy：baseline → change plan；hybrid：baseline → concept
Structure fragment | 决定 part / assembly 的设计分解与集成检查 | assembly：assembly_design → interface_design → part_design → integration_review
Maturity overlay | 增加 obligations 与 release/manufacturing closure，而非复制整条流程 | release：BOM、assembly/service、inspection、presentation 等

## 6.2 推荐的 Compiler 输出

interface CompiledProcess {
phases: PhaseSpec[];
obligations: Obligation[];
acceptedEvidence: EvidenceRequirement[];
finishEvidence: EvidenceRequirement[];
mutationPolicies: ...;
}

这避免 3 × 2 × 4 = 24 条硬编码 workflow，也让 assembly 逻辑、release 逻辑、legacy 逻辑都只写一次。

# 7. Part 与 Assembly 的不同设计过程

## 7.1 Part

requirements
→ [concept if architecture is genuinely open]
→ part_design
→ build
→ review
→ ready

## 7.2 Assembly

requirements
→ system_concept
→ assembly_design
→ interface_design
→ part_design
→ build
→ integration_review
→ ready

## 7.3 Assembly Design 应回答什么

- 子系统 / subassembly 如何划分；哪些实体应当独立存在。
- 系统 datum、load/motion/energy path。
- 装配顺序、拆装顺序、服务路径与工具进入方向。
- 功能 envelope、运动 envelope、线缆/软管/维护空间。

## 7.4 Interface Design 才是 Assembly 的核心

A ↔ B
- purpose
- locating scheme
- constrained DOF
- fastener / joining method
- fit / clearance
- assembly direction
- tool access
- adjustment
- datum
- load transfer

零件设计应由其承担的 interface contracts 反推，而不是 Agent 先画零件再“想办法拼起来”。

# 8. Reroute：只能增加义务，不能授予进度

Reroute 三条硬约束

1) Rerouting may increase obligations, but never erase them without user authority. 2) Rerouting changes required context; it never grants forward progress. 3) Agent 不能指定 target phase。

## 8.1 用 obligation set 判断 downgrade

如果 O_old ⊆ O_new：允许 Agent 自主 reroute（只增加义务）
如果 O_old ⊄ O_new：说明有义务被删除，需要用户显式授权

这比手工维护“part→assembly 可以、assembly→part 不行”更一般，也自然覆盖 engineering→prototype、release→engineering、hybrid→greenfield 等降级。

## 8.2 Reroute 后 Harness 自己计算回退点

例如已在 BUILD 才发现其实是 assembly：Harness 重新编译流程，发现 assembly_design / interface_design 尚未满足，则自动回到最早 unmet phase；Agent 无权传 targetPhase=review。

## 8.3 用户授权如何表达

不要相信 Agent 自传 userApproved=true。应由显式用户确认 / UI action / slash command 生成一次性 downgrade authority，再允许删义务。

# 9. Physical Realizability：干涉、装配与真实性

目前 assembly_tree 只提供 occurrence label / hierarchy / local+world transform / leaf count；它并不检测真实几何干涉。因此复杂装配“穿模但看起来还行”不会被系统强烈暴露。

## 9.1 新增 deterministic interference sensor

cad_inspect_interference({ artifact })
→ pairwise candidates (AABB broad phase)
→ exact common volume / minimum distance
→ raw facts only

几何状态 | 确定性事实 | Agent 解释
penetration | intersectionVolume > tolerance | 通常是错误，也可能是有意过盈
contact | intersectionVolume ≈ 0 且 minDistance ≈ 0 | 可能是正确接触面
clearance | minDistance > 0 | 是否足够由 interface intent 判断

## 9.2 Assembly route 自动注入的 evidence obligation

当 structure=assembly 时，CompiledProcess 应自动要求 current-version assembly + interference observation。Harness 不判断穿模是否“坏”，只确保 Agent 不能在没有看过现实数据时宣布完成。

## 9.3 Candidate auto-action 建议

cad_commit_candidate
→ build
→ visual
→ geometry
→ assembly_tree (assembly only)
→ interference (assembly only)
→ review
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

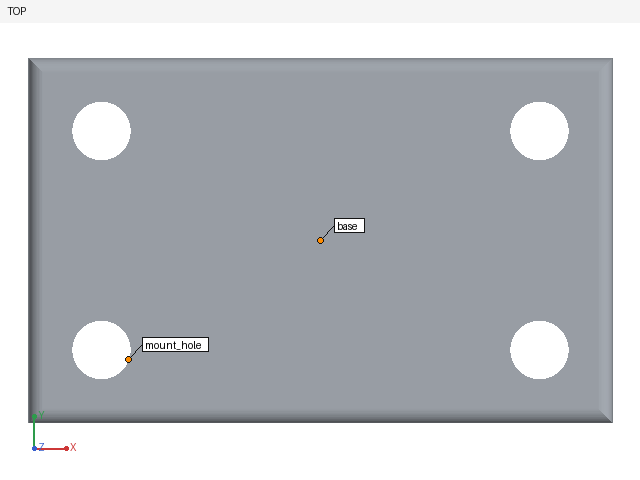
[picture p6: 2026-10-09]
docs/freecad-part-backend/freecad-after-top.png

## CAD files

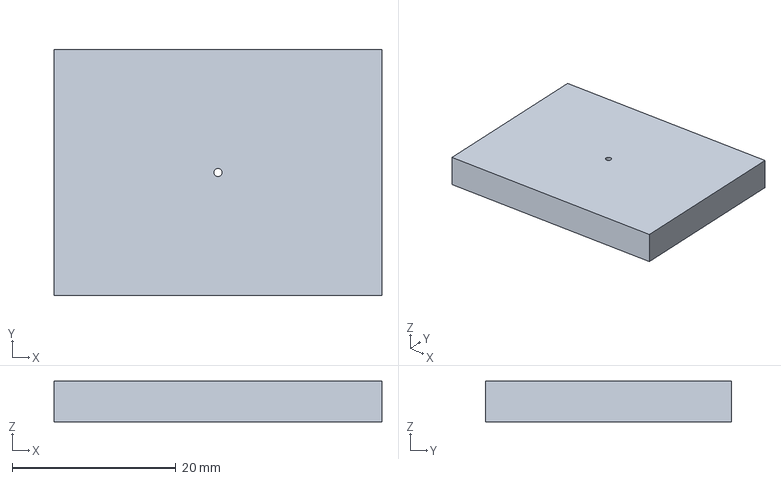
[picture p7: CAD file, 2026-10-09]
tests/fixtures/dfm/import_step_part/part.step
40.0 x 30.0 x 5.00 mm

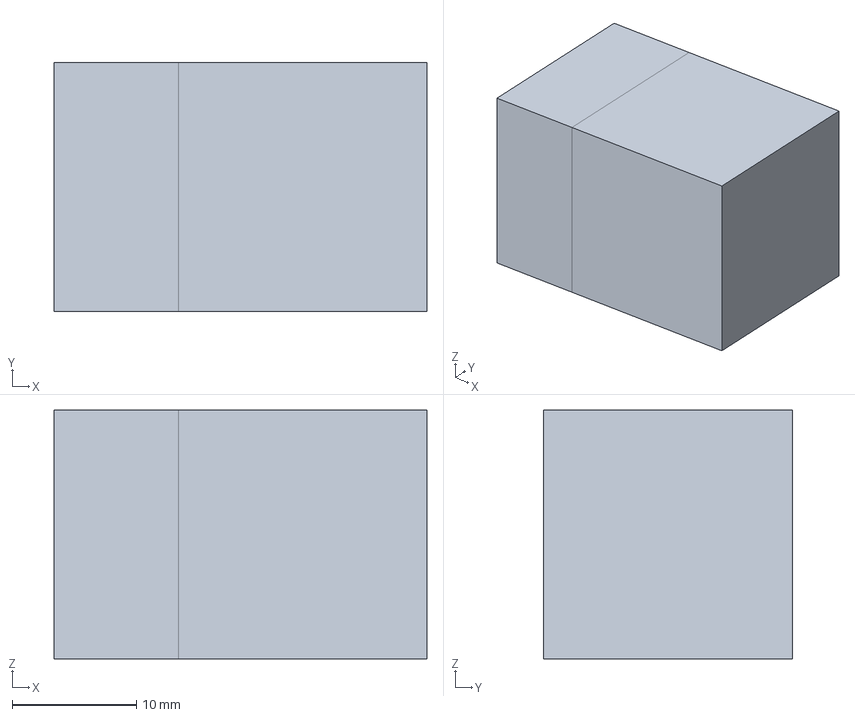
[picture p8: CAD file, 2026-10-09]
tests/fixtures/interference_penetration.step
30.0 x 20.0 x 20.0 mm

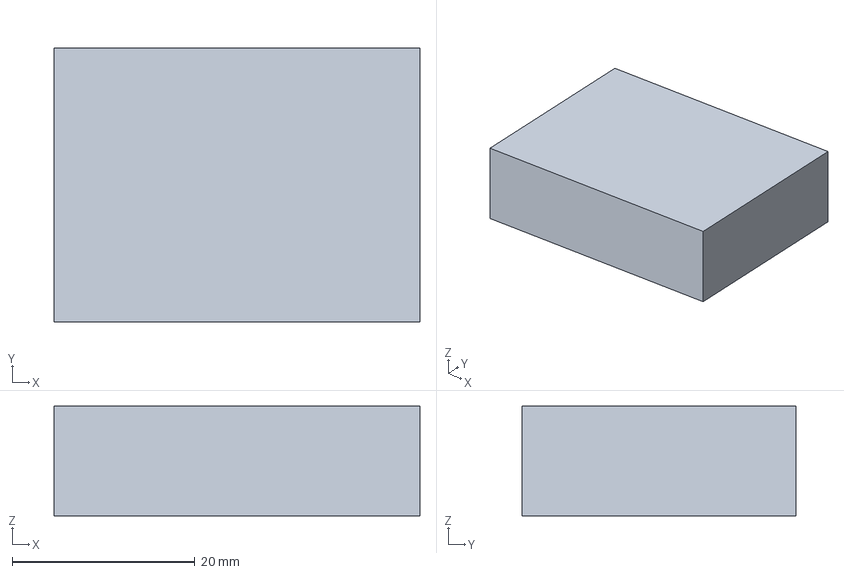
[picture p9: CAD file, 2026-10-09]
tests/fixtures/section_axes_box.step
40.0 x 30.0 x 12.0 mm

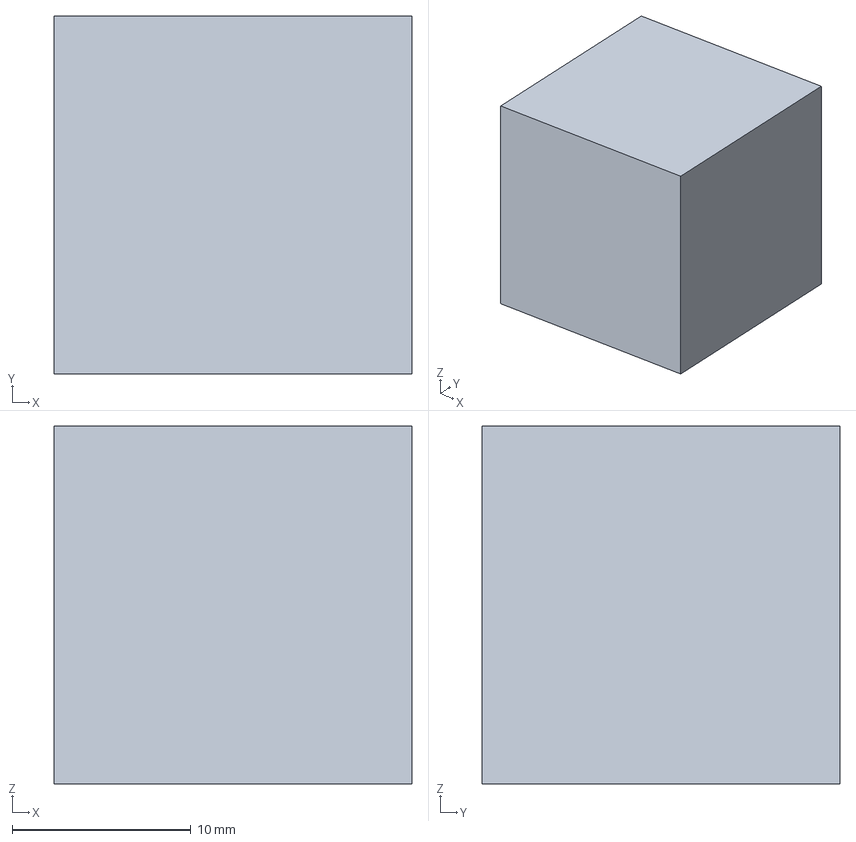
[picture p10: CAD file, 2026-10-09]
tests/fixtures/interference_single.step
20.0 x 20.0 x 20.0 mm

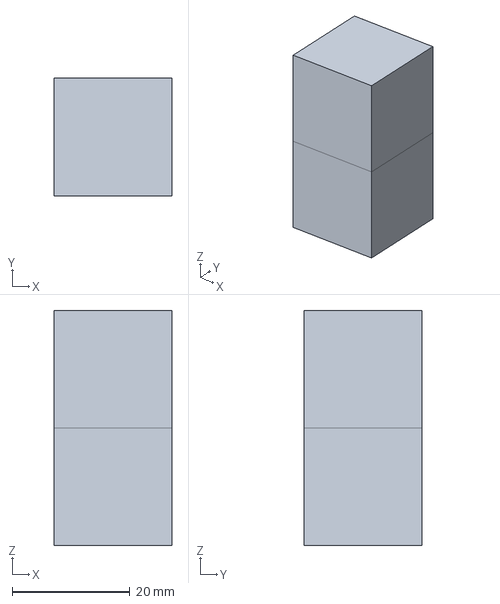
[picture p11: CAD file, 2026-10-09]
tests/fixtures/interference_contact.step
20.0 x 20.0 x 40.0 mm

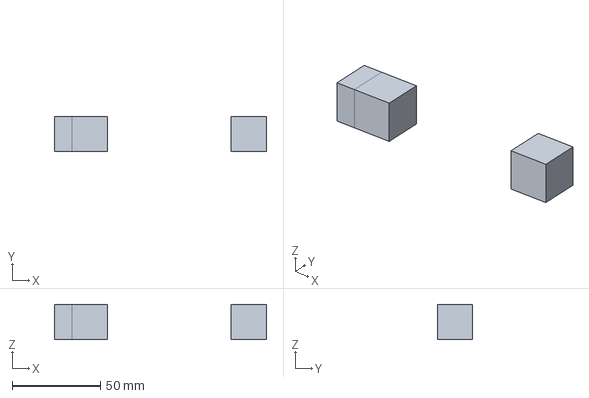
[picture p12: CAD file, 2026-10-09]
tests/fixtures/interference_three.step
120.0 x 20.0 x 20.0 mm

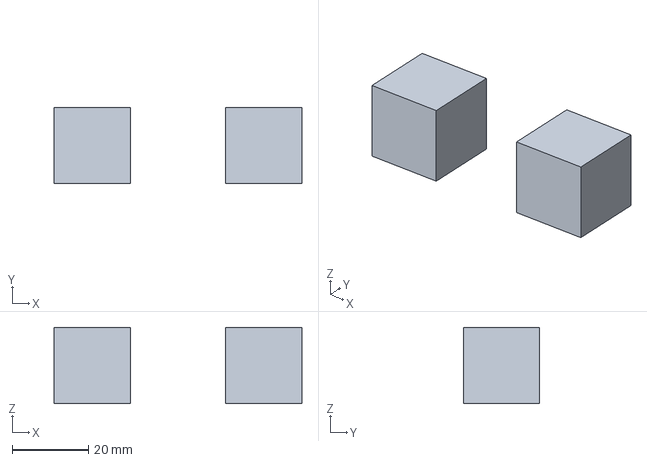
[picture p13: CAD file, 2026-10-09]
tests/fixtures/interference_clearance.step
65.0 x 20.0 x 20.0 mm

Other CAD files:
benchmarks/simulation-v2/openfoam14-box/domain.step

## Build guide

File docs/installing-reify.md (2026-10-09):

# Installing and updating Reify Desktop

Reify Desktop currently targets Windows 11 x64 with WSL 2 Ubuntu, Ubuntu 22.04/24.04 x64, and macOS 14+ on Apple silicon. Other Linux distributions and Intel macOS builds are not declared supported until exercised on those systems.

Projects live wherever the user chooses. Application preferences and credentials live in the operating system user-data directory, and the engineering runtime lives under the user's local data directory. Removing or replacing the application does not remove projects. Data deletion is a separate manual action.

## Windows

Use the signed NSIS installer for a normal installation or the Portable build only when an organization explicitly permits it. Reify detects the configured WSL distribution by exact name. Existing initialized Ubuntu environments are reused; missing WSL, missing distribution, and uninitialized distribution are separate recoverable states. WSL enables the isolated Linux CAD and authority runtime. Enabling WSL can require administrator approval and a Windows restart; Reify persists setup choices and checks again after restart.

Finish or stop an active Agent task before installing a newer version. Run the new installer through the same channel. The uninstaller preserves user data and projects. Keep the previous signed installer for manual rollback when the release notes declare the project schema compatible.

## Ubuntu deb

Install `Reify-Linux-amd64.deb` with the system package manager. The package supplies the Reify icon and desktop entry. The base CAD runtime is prepared separately from optional ParaView, Blender, and simulation components. Retry dependency setup from Settings after resolving network or package-manager permission errors.

Upgrade with a newer deb through the package manager. Do not switch an existing installation automatically to AppImage. For rollback, reinstall the previous deb only when its release manifest declares the existing project schema readable.

## Ubuntu AppImage

Mark `Reify-Linux-x86_64.AppImage` executable and run it. If FUSE is unavailable, use the AppImage extract-and-run option documented by the target system. Desktop integration is an explicit user choice. The AppImage file is separate from user data and project files, so moving or deleting it does not remove either.

Update by downloading a newer AppImage after stopping active tasks, verifying its published SHA-256, and replacing the application file. Keep the previous verified file for rollback. Do not mix AppImage and deb update instructions.

## macOS

The public DMG must be Developer ID signed and Apple notarized. Copy Reify to Applications, then start it normally. The release pipeline treats missing certificate, Apple ID, app-specific password, or team ID as a release blocker; disabling Gatekeeper is not an installation method. Native author and reviewer processes retain separate authority boundaries.

Quit active Agent work before replacing the app from a newer signed and notarized DMG. Keep the prior notarized DMG for compatible rollback. Removing the app preserves projects and user data.

## Optional FreeCAD part backend

The `cad.part` Python API builds parametric parts in FreeCAD (Part Design). It is optional. The build123d path (`cad.model.build`) works without it.

Install it with one command from the repository root:

```bash
npm run setup:freecad            # add -- --force to reinstall
```

The script supports Linux x86_64 (including WSL) and macOS arm64. It needs no sudo. It does not change shell configuration files. It downloads a pinned micromamba from conda-forge (SHA-256 checked), creates a private conda environment from the lock file in `python/runtimes/freecad/`, runs a smoke test (Pad, Pocket, Fillet, STEP export), and writes `runtime.json`.

| Item | Location |
|---|---|
| Linux / WSL | `${XDG_DATA_HOME:-~/.local/share}/pi-cad/runtimes/freecad` |
| macOS | `~/Library/Application Support/pi-cad/runtimes/freecad` |
| Override | `PI_CAD_FREECAD_HOME` (install) and `PI_CAD_FREECAD_PYTHON` (use another FreeCAD Python at run time) |

Check the result with `python -m cadctl doctor --json`. The `freecad` entry shows `ready`, `unavailable`, or `error`. Without the backend, `cad.part` calls fail with `FREECAD_NOT_INSTALLED` and the message `run: npm run setup:freecad`. The API never downloads FreeCAD by itself.

Disk use: about 4.2 GB (measured with FreeCAD 1.1.0 on Linux x86_64, after the download cache is cleaned). To uninstall, delete the `freecad` directory from the table above.

The osx-arm64 lock file was solved on Linux (`CONDA_OVERRIDE_OSX=11.0`) and has not been install-tested on a Mac. If it fails, the script prints the error. Delete the lock file to make the script solve `environment.yml` instead.

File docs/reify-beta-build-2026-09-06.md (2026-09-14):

# Reify Windows 内测候选包

日期：2026-09-06  
版本：0.1.0 beta candidate  
平台：Windows x64；主路径使用 WSL Ubuntu。

安装包 SHA-256：A34BB923FBEB54BE2E95D6508C0884734D8A21A72D9CBA7B1746CB3225DDA8CC
便携版 SHA-256：FE833D585C48EF541779C5D1D75C7B67B90F2406AFBDF497CD54D42EB6A60BB8

## 本版重点

- 正式桌面 App 使用现有 Reify 标志、字标、图标和暖白、深绿视觉。
- Viewer 常驻为大画布。完整对话从悬浮输入框后方展开。
- 输入框只挂载一次；切换不移动、不丢草稿、附件、视角或选择。
- 点击上沿细线切换；拖动调整位置；双击或“复位输入框”恢复默认。
- 位置按窗口保存；窗口缩放、高缩放和短窗口会限制到可见区域。
- 原 CAD、概念图、参数、失败恢复、任务排队、仿真、比较、审查、批准和本地交付能力继续使用真实数据路径。
- 首次启动使用统一品牌与中文三步设置。

## 自动验收

- 桌面生产构建：通过。
- 桌面单元与集成测试：72/72。
- 根目录 TypeScript 测试：300/300。
- Python 测试：129 项通过，7 项按环境跳过。
- 桌面完整主流程 E2E：通过。包含概念图、任务排队与停止、对话/画布切换、项目和会话恢复、参数失败及应用、仿真、比较。
- 悬浮输入框专项：1366×768、1920×1080、125% 缩放、920×680、拖动、重启恢复、双击复位通过。
- 最终打包程序：启动通过。
- Windows 当前用户静默安装、启动、快捷方式和卸载项：通过。
- 最终打包程序真实 STEP：解析、坏文件恢复、导出逐字节一致、源文件变化后刷新通过。

## 内测前人工项

- 使用真实 ChatGPT 账号完成登录、取消和重试。
- 在有 GPU 的目标电脑确认真实 3D 旋转、缩放和光照；自动化主机没有可用 WebGL，已验证降级提示。
- 验证目标电脑已有 WSL 的首次真实 Agent 建模流程。
- Blender 完整编辑采用外部窗口；本次最终 Windows 包尚未完成该电脑上的人工往返。
- 找一位未参与开发的工程师完成首次任务，并记录卡点。
- 安装包没有正式代码签名，仅用于组织允许的内测环境。

## 主流程

安装 → 首次设置 → 打开或创建项目 → 对话提出需求 → 查看成果 → 调整参数 → 处理一次失败 → 导出。

对话/画布快捷键：Ctrl + \\。  
输入框：点击细线切换，拖动细线移动，双击细线复位。

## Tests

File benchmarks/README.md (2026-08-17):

# Pi-CAD empirical benchmark

This directory measures the same task corpus across three configurations:

1. `bare` — Pi with no extensions and no CAD skill.
2. `cad-skill` — Pi with the frozen `ref/cad-skill` loaded as a skill.
3. `pi-cad` — the Pi-CAD package (default core/geometry/visual/ui).

## Metrics

| Metric | Source |
| --- | --- |
| success | process exit + expected files + `.pi-cad/state.json` phase |
| wall time | measured around the `pi -p` process |
| model tokens | sum of assistant message `usage.totalTokens` in the session JSONL |
| tool calls | count of `toolCall` entries in the session JSONL |
| user turns | count of `role=user` messages |
| iterations | count of `cad_commit_candidate` tool calls for Pi-CAD; analogous calls for cad-skill |
| error events | count of `output-error` tool results / non-zero exits |

## Runner

```bash
node benchmarks/run.mjs --tasks quick-plate --configs bare,cad-skill,pi-cad
```

Environment expected:

- `PI_CODING_AGENT_DIR` points to a writable agent dir with CodeX auth.
- `PI_CAD_REPO` defaults to this repository.
- `PI_CAD_MODEL` defaults to `gpt-5.6-luna`.
- `PI_CAD_THINKING` defaults to `medium`.
- `PI_CAD_TIMEOUT_MS` defaults to `600000`.

Results land in `benchmarks/results/<run-id>/`.

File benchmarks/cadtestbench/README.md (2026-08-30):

# CADTestBench × Pi-CAD Benchmark

Headless requirements screening can either continue into CAD or stop after a
recorded decision:

```bash
PI_CAD_HEADLESS_AFTER_GRILLING=build node run.mjs ... # default
PI_CAD_HEADLESS_AFTER_GRILLING=exit node run.mjs ...  # triage only
```

Interactive workflows enter the `grilling` phase and use the bundled
`grill-me` skill before engineering begins.

External deterministic benchmark loop for the Pi-CAD harness (plan v0.1,
Jira JIN-30). One command takes a CADTestBench prompt through the
**unmodified production harness** to a scored, fully-logged run:

```
CADTestBench prompt (adapted) → pi -p + Pi-CAD extensions → STEP artifact
  → bridge wrapper → CADTestBench evaluator → manifest + transcripts
```

## Status

| Phase | State |
| --- | --- |
| 0 experiment contract | ✅ frozen (see `experiment.json` per run + this file) |
| 1 bootstrap | ✅ dedicated venv, frozen dataset snapshot, official evaluator verified |
| 2 STEP bridge parity | ✅ 200/200 samples, see [parity findings](#bridge-parity-findings) |
| 3 one-command runner | ✅ `run.mjs` |
| 4 pilot-5 | ✅ 3/5 exact, 2 harness findings |
| 5 diagnostic-20 baseline | ✅ 18/20 exact, 249/257 CADTests (96.9%) |
| 6 failure analysis | ✅ `classify.py`, 2 DIM/GEOM (REQ-side) + 2 HARNESS stalls |
| 7 harness patch | ✅ commit `8fb170e` (autonomous decision boundary) |
| 8 paired regression | ✅ executed — **integrity audit pending** (see below) |

> **Integrity note (2026-08-20)**: the detailed-200 run was stopped at 89/200
> after a leakage audit found ground-truth material (parity outputs, frozen
> dataset) within the agent's filesystem reach; 4 of 89 samples were
> contaminated. All model runs to date (pilot-5, both diag-20 rounds,
> detailed-200) predate this discovery and their **scores are unaudited**;
> the `8fb170e` completion-rate attribution rests on direct transcript
> evidence and stands. Formal numbers require the isolation fix and a clean
> rerun. See `retrospective-v0.1.md` for the full postmortem.

## Layout

```
benchmarks/cadtestbench/
├── bootstrap.sh          # Phase 1 end-to-end (venv, install, freeze, smoke)
├── freeze-dataset.py     # HF → local parquet snapshot + dataset-lock.json
├── extract-prompts.py    # prompts + frozen adaptation policy
├── select-sets.py        # freeze pilot-5 / diagnostic-20 (deterministic)
├── bridge.py             # STEP→CadQuery wrapper generator (+baseline export)
├── parity.py             # bridge parity test A/B over full partition
├── classify.py           # failure taxonomy (plan §6 codes)
├── compare.py            # paired regression before/after (plan §8)
├── report.py             # first-report generator (plan §17)
├── run.mjs               # the benchmark runner (Phase 3 adapter)
├── dataset-lock.json     # frozen dataset provenance (committed)
├── sets/*.json           # frozen sample sets (committed)
├── data/                 # frozen snapshot + adapted prompts (gitignored)
├── external/CADTestBench/# upstream clone @ e29283c (gitignored)
└── results/              # all runs (gitignored)
```

## Experiment contract (Phase 0)

* **Model**: `openai-codex/gpt-5.6-luna`, thinking `max` — identical for
  baseline and regression.
* **Pi-CAD**: git commit recorded per run in `experiment.json`; production
  extensions only (`core,geometry,visual,ui`) via explicit `-e`, with
  `--no-skills --no-themes`. No benchmark-only tools, no workflow changes.
* **Benchmark**: upstream `CADTestBench` @ `e29283c`, dataset frozen from
  HF `dimitrismallis/CADTestBench` rev `2b9a4a9` into local parquet
  (`dataset-lock.json`, sha256 per file). Evaluation never touches the Hub.
* **Prompt adaptation (frozen policy)**: every CADTestBench prompt
  (200/200 both partitions) literally instructs "Write Python code using
  CADQuery". Pi-CAD is a build123d toolchain, so the code-generation
  instruction is stripped (regex, logged per sample in
  `data/prompts.<partition>.json`) and a fixed task frame is appended:
  *"Deliver the part as a STEP artifact with its Python source."*
  Requirement text (dimensions, features, spatial constraints) is preserved
  byte-for-byte. Same policy for baseline and regression runs.
* **Timeout / retry**: 30 min per sample, 1 attempt (retries only for
  provider transport failures).
* **Artifact resolution**: `project.head.artifactPath` → latest
  `runs.*.currentArtifactPath` → `NO_ARTIFACT`. CAD correctness and harness
  completion are reported as **independent** metrics.
* **Python isolation**: Pi-CAD runtime (build123d/OCP, repo-managed) vs
  evaluator runtime (cadquery 2.8.0 in `.venv/`, uv CPython 3.12.14) —
  the two stacks never share an environment; STEP is the only interface.

## Usage

```bash
./bootstrap.sh                                   # one-time
node run.mjs --set pilot-5                       # pilot
node run.mjs --set diagnostic-20 --label baseline
node run.mjs --sample-ids 00000007 --label probe
node run.mjs --set diagnostic-20 --dry-run       # inspect contract only
.venv/bin/python parity.py --partition detailed  # re-verify bridge
```

Per-sample output (plan §16): `results/<run>/samples/<id>/` contains
`manifest.json` (joined benchmark/agent/harness/evaluation/usage/execution
fields), `prompt.txt`, `session.jsonl` (agent transcript), `pi-cad/`
(state + events + records + evidence), `generated/` (STEP + source),
`cadtest/summary.json` (per-test detail), `stdout.log`/`stderr.log`.

## Bridge parity findings (Phase 2)

Full-partition A/B: official GPT-5.2 CadQuery code evaluated directly vs
the same geometry exported to STEP and re-imported through the bridge.
200/200 samples, 0 export failures. **Exact pass 96 → 94 (−2)**;
22 flipped tests of ~3 037 (0.7%): 13 lost, 9 gained.

Root causes (all documented in `results/parity/detailed/report.{json,md}`):

1. **Shell-based official models (3 samples, 6 tests)** — the official
   baseline itself produces Shell/Compound shapes (not valid solids).
   Direct evaluation sees an in-memory solid; STEP serialization exposes
   the shell structure (`solids=0`). This is a defect of the official
   baseline outputs, **not** of the bridge: Pi-CAD emits validated solids.
   Excluded from frozen sample sets; would be scored as-is if generated by
   Pi-CAD.
2. **STEP seam topology (1 sample, 4 tests)** — face/edge/vertex counts of
   an extruded hexagon change (8→12 faces) because STEP import splits
   periodic seams. Genuine STEP information loss, topology-category only;
   sample excluded from frozen sets.
3. **Tolerance-boundary volumetric flips (6 lost / 6 gained)** — symmetric
   noise around tolerance edges (e.g. shape factor exactly 1.0000), no
   systematic direction. Kept in sets; does not bias before/after
   comparisons since it is direction-symmetric.

**Verdict**: the bridge does not systematically change benchmark results
for valid-solid geometry; adapter noise is enumerated and excluded from
attribution.

## Metrics

Primary: exact task success (all CADTests passed), CADTest pass rate.
Per-category (topo/solid/dim/vol/space/geom) from evaluator
`category_breakdown`. Harness: artifact rate, workflow completion
(`state.json` phase/status), candidate commits, tool calls, error events.
Efficiency: input/cached/output tokens, wall time (from session JSONL
usage records).

## First regression cycle (Phases 5–8)

Baseline (commit `8c852ec`) → failure analysis → patch (`8fb170e`) →
paired regression, same frozen Diagnostic-20 / Luna Max / contract
(asserted identical by `compare.py`):

| metric | baseline | regression |
| --- | --- | --- |
| exact success | 18/20 | 18/20 |
| CADTests passed | 249/257 (96.9%) | 249/257 (96.9%) |
| harness completed | 18/20 | **20/20** |
| total cost | $0.598 | $0.466 |

* **Failure taxonomy** (baseline): 2× REQ-side DIM/GEOM (samples 00000960,
  00996457 — the agent misread "offset by X along the axis" as
  center-to-center distance; official GPT-5.2 fails 00000960 identically),
  2× HARNESS stalls (00000007, 00001490 — geometry already passing all
  CADTests).
* **Patch**: prompt-policy clarification of the autonomous decision boundary
  for `cad_wait_for_user` + maturity obligation warning on `cad_route`
  (production `src/core/controller.ts`, 97/97 TS tests pass). General
  guidance, no benchmark-specific hack.
* **Attribution**: zero score flips; the only changed outcome is that both
  stalled runs now close (12/12 and 14/14 CADTests, phase `done`), plus a
  22% cost reduction from not lingering in review.

Run bundle locations: `results/*_diag20-baseline/` (report.md,
failures.json), `results/*_diag20-regression/` (report.md,
comparison.md), `results/*_pilot5-luna-max/` (report.md).

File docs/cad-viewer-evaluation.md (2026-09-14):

# CAD Viewer 选型

更新时间：2026-08-31

## 结论

主视口建议采用 [`three-cad-viewer`](https://github.com/bernhard-42/three-cad-viewer)，不要继续维护自制坐标轴、方向控件、相机状态和模型树。

STEP 继续在 Pi-CAD/sidecar 中用 OpenCascade 系工具读取和离散化，再把带层级、名称、颜色、三角面和边线的数据传给 Viewer。第一版不要把 STEP 解析搬进 Electron 渲染进程。

建议分两层：

1. `three-cad-viewer` 管显示、相机、标准视图、坐标、选择和树。
2. Pi-CAD 自己补很薄的测量与剖切层；后续若确实需要浏览器内 B-Rep，再单独评估 OpenCascade.js。

CADAM 只作为视觉参考。That Open Engine 和 xeokit 都更偏 BIM/IFC，不适合作为当前 STEP-first 机械 CAD 的底座。

## 需求

当前最容易做错的不是材质，而是视口语义：

- 世界坐标、屏幕坐标和模型坐标必须一致。
- 右上角方向控件必须与相机 `up`、正视/俯视/侧视严格对应。
- resize、DPI、最大化和面板拖动后，画布与控件必须同步。
- 选择要能回到零件、实体、面和边。
- 需要适配模型树、隐藏、聚焦、剖切、测量和装配。

这些不该靠几块 DOM 和手写旋转矩阵拼出来。

## 对比

| 方案 | 许可证 | STEP | 标准视图/坐标 | 选择/树 | 剖切/测量 | 活跃度 | Electron/React 代价 | 判断 |
|---|---|---|---|---|---|---|---|---|
| three-cad-viewer | MIT | 不直接读 STEP；接收离散后的 Three.js 几何 | 内建视图与 `up: "Z"` 配置 | 内建层级 Shapes、显示状态和零件树 | 未见成熟的原生测量/剖切 | 仓库持续维护，专为 CAD 显示 | 低；ESM 组件嵌入现有 React 容器 | **首选** |
| CADAM | GPL-3.0 | OpenSCAD WASM，主要产出网格，不是 STEP/B-Rep Viewer | React Three Fiber 自建 | 当前设计树仍在需求/演进中 | 没有可直接复用的完整机械 CAD 检查层 | 很活跃，约 5k stars | 中高；只能摘设计，直接复用会受 GPL 约束 | 只参考视觉 |
| That Open Engine | MIT（核心组件） | 官方重点是 IFC/Fragments，不直接支持 STEP | 有相机、网格等底层组件；不是现成机械 CAD ViewCube | 有射线选择和 BIM 数据组件 | 有 Clipper、长度/面积/体积测量 | 很活跃，2026 年仍频繁更新 | 中；组件多，需要自行组装 UI，STEP 仍需转换 | 不选，方向偏 BIM |
| xeokit v2 | AGPL-3.0 或商业许可 | 不直接支持 STEP；常见入口是 XKT、IFC、glTF | NavCube、AxisGizmo、标准相机控制成熟 | TreeView、选择、隐藏、X-ray 成熟 | SectionPlanes 和距离/角度测量成熟 | 成熟且频繁发布 | 中；功能最全，但需格式转换与许可证评估 | 功能备选，不宜默认集成 |
| xeokit v3 | AGPL-3.0 | 多格式，但仍不以 STEP 为主 | 新架构包含 Viewer/View | 新工具栈 | 测量已有模块 | 仍明确标为 alpha | 高，API 仍可能变化 | 暂不采用 |
| OpenCascade.js | LGPL-2.1 | **原生 STEP/B-Rep 能力** | 无现成产品级视口控件 | 需要自行做拾取、树和 UI | 几何计算可做，但 UI 全要自建 | 最新正式 release 较早 | 很高；WASM 体积、初始化、worker、打包都有成本 | 只作为解析内核候选 |

## 各方案说明

### three-cad-viewer

这是最贴近现状的方案。官方把它定义为基于 Three.js 的 CAD Viewer，输入是已离散的顶点、三角面、法线和边；多个 Shape 可以组成层级树。它已有 CAD 显示需要的状态模型，支持每个节点的实体/边线显示状态，并允许明确设置 Z-up。

优点：

- MIT，可直接用于桌面产品。
- 输入与 Pi-CAD 当前的“后端读 STEP、前端显示网格”边界一致。
- 不需要在 renderer 内启动 OpenCascade WASM。
- 模型树、零件显示、边线和相机约定由一个组件统一维护。
- 可保留 Pi-CAD 自己的视觉样式，不必照搬完整界面。

限制：

- 它不是 STEP Loader。
- 官方资料没有证明它提供完整的尺寸标注和剖切工作流。
- 需要做一层 React 生命周期封装，并检查容器 resize 与高 DPI。

### CADAM

[CADAM 官方仓库](https://github.com/Adam-CAD/CADAM)使用 React 19、React Three Fiber 和 OpenSCAD WASM，整体采用 GPL-3.0。它是完整应用，不是独立 Viewer 包。

直接搬它的问题：

- GPL-3.0 会影响集成后的分发方式。
- 它的几何核心是 OpenSCAD/网格，不保留 STEP 的装配与 B-Rep 语义。
- 现有视口同样基于 Three.js/R3F 自行组装，不能从根上消除坐标、方向控件、DPI 和选择同步的坑。
- 官方 issue 中“参数化设计树 Viewer”仍是开放需求，说明它不是现成的完整装配树方案。

可以借鉴：全屏模型优先、轻量浮动控件、空状态和生成过程的视觉层级。不要复制代码。

### That Open Engine

[核心仓库](https://github.com/ThatOpen/engine_components)为 MIT，且维护活跃。官方已有 Raycaster、Clipper、Fragments 和长度/面积等测量组件；剖切示例证明它能从点击面创建和管理剖切平面。

问题是产品方向主要是 BIM/IFC。它能解决通用 Three.js 工具问题，却不能直接解决 STEP 读取、机械零件层级和 B-Rep 选择。集成后仍要自己搭 ViewCube、机械模型树和 STEP 转换，收益小于 three-cad-viewer。

### xeokit

[xeokit v2](https://github.com/xeokit/xeokit-sdk)的 Viewer 功能最完整：官方示例明确列有 NavCube、AxisGizmo、TreeView、ContextMenu、SectionPlanes 和测量。它适合大模型、BIM 和工程审阅。

主要阻碍：

- AGPL-3.0；闭源分发需要商业许可。
- 官方 Loader 重点是 XKT、IFC、glTF、OBJ 等，不含直接 STEP。
- 为当前单件/小装配机械 CAD 引入 BIM 数据链过重。

如果以后产品明确开源为 AGPL，或购买商业许可，并且目标扩展到大型 BIM/工厂模型，xeokit 才值得重新考虑。

[xeokit v3](https://github.com/xeokit/sdk)仍标为 alpha，暂不用于发布版。

### OpenCascade.js

[OpenCascade.js](https://github.com/donalffons/opencascade.js)是 OpenCascade 的 WebAssembly 移植，许可证 LGPL-2.1，确实能在浏览器侧处理 STEP 和 B-Rep。

但它是几何内核，不是 Viewer 产品。坐标轴、ViewCube、相机控制、树、选择外观、测量 UI、剖切交互都仍要自己做。若只是为了修正现有右上角控件，引入它不会解决问题，反而增加 WASM 打包和线程管理成本。

## 推荐落地

### 第一阶段：替换视口，不动几何链

- sidecar 从 STEP 提取层级、名称、颜色、变换、三角面、法线和可见边。
- 定义稳定的 `CadSceneDocument`，版本化传给 renderer。
- 用 `three-cad-viewer` 替换当前自制 canvas、坐标轴和右上角相机控件。
- 统一 Z-up；用基准模型验证 Front/Back/Left/Right/Top/Bottom。
- ResizeObserver 驱动画布尺寸，使用真实 `devicePixelRatio`。

### 第二阶段：补工程检查

- 测量通过后端 OpenCascade/Build123d 查询精确点、边、面，不以三角网格估算为权威结果。
- 前端只负责拾取和画标注。
- 剖切可先用 Three.js clipping plane；剖面面积等精确结果仍由后端计算。
- 模型树节点保存稳定 ArtifactRef/shape id，避免只靠数组下标。

### 第三阶段：再决定是否需要浏览器 B-Rep

只有出现离线即时 STEP 导入、浏览器内布尔运算或完全无 sidecar Viewer 的明确需求时，才引入 OpenCascade.js。

## 验收基准

替换后至少自动验证：

1. Z-up 模型六个标准视图方向正确。
2. ViewCube 点击后的相机方向与坐标标记一致。
3. 100%、125%、150%、200% DPI 下控件不漂移、不模糊。
4. 800×600、1280×720、1920×1080 和最大化下无裁切。
5. 拖动左右面板时 Viewer 实时 resize，不拉伸模型。
6. 选择零件后，树与视口双向同步。
7. 多零件 STEP 保留名称、颜色、层级和变换。
8. 隐藏、隔离、聚焦、正交/透视切换可恢复。
9. 测量结果与后端精确值一致，不把网格近似冒充尺寸。
10. WebGL context 丢失后给出可恢复错误，不显示空白画布。

## 官方来源

- [three-cad-viewer 官方仓库](https://github.com/bernhard-42/three-cad-viewer)
- [CADAM 官方仓库](https://github.com/Adam-CAD/CADAM)
- [That Open Engine 官方组织与仓库](https://github.com/ThatOpen)
- [That Open Clipper 官方示例](https://github.com/ThatOpen/engine_components/blob/main/packages/core/src/core/Clipper/example.ts)
- [xeokit v2 官方仓库](https://github.com/xeokit/xeokit-sdk)
- [xeokit 官方示例目录](https://xeokit.github.io/xeokit-sdk/examples/index.html)
- [xeokit v3 官方仓库](https://github.com/xeokit/sdk)
- [OpenCascade.js 官方仓库](https://github.com/donalffons/opencascade.js/)
- [OpenCascade 官方许可证说明](https://dev.opencascade.org/doc/overview/html/index.html)

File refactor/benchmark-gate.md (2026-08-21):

# Phase 3 Benchmark Gate Record

Date: 2026-08-21 · Branch: `refactor/runtime-v2` · Task: `quick-plate` (pi-cad config)

## Comparison

| Metric | Before (2026-08-20, commit 69225e8) | After (2026-08-21, phase 1–8 complete) |
| --- | --- | --- |
| success (checker) | false | false |
| missing artifacts | build/plate.step, models/plate.py | identical |
| piCadPhase | idle (checker reads post-finish state) | identical |
| toolCalls | 16 | 16 |
| candidateCommits | 1 | 1 |
| errors | 0 | 0 |
| tokens | 99,878 | 122,605 |
| wallMs | 86,780 | 111,038 |

## Interpretation

The `success:false` verdict is a **task-checker filename expectation**
artifact, identical before and after: the agent names its outputs
`models/mounting_plate.py` / `build/mounting_plate.step` while the
checker expects `plate.py` / `plate.step`. The workflow itself completed
end-to-end in BOTH runs:

- `cad_route → cad_commit_requirements → cad_commit_plan → source →
  cad_commit_candidate` (auto evidence bound) → geometry/section/surface/
  measure probes → `cad_transition(accepted)` → `cad_finish`
- zero tool errors in both runs
- identical tool-call pattern (16 calls) in both runs

The "after" run additionally exercised the refactored stack under a real
LLM driver: probe-registry wrappers answering legacy tool names
(`cad_inspect_geometry` etc.), observation-layer rendering, contract-
compiled phase tool sets, finalizer-driven candidate commit.

## Gate verdict

- **No capability regression**: identical workflow completion, identical
  checker outcome, zero errors, same tool budget.
- Token delta (+23%) and wall-clock delta (+28%) are within single-sample
  noise for this task; the before-run itself varies by driver caching and
  model load. Not treated as a regression signal; to be confirmed with a
  multi-task campaign before old-tool retirement.
- **Old-tool retirement stays gated**: the legacy inspection wrappers
  remain registered (deprecated) until a fuller campaign (multiple tasks
  × configs × seeds) confirms parity, per the v2 plan.

## Reproduce

```bash
node benchmarks/run.mjs --tasks quick-plate --configs pi-cad
```

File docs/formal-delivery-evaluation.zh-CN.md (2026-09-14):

# Reify 正式交付收益对照协议

每个 experimentId 固定模型及推理档位、任务文本、机器与 runtime 版本、token/时间预算和人工验收量具。按 `baseline`、`tiered`、`tiered-review` 三种变体执行；经验候选完成独立验证与采用后，追加 `tiered-review-experience`，不得用历史 benchmark 替代。

每个样本单独保存 JSON、Agent trace、构建/审查 evidence、人工验收记录和正式包 manifest。样本字段由 `scripts/summarize-product-evaluation.mjs` 强制检查，包括工程验收、误通过、人工介入、是否恢复、总时长、首个反馈、费用和 release state。脚本拒绝同 experimentId 下模型、任务、环境或预算变化的伪对照，并把全部原始样本嵌入报告。

负向样本固定覆盖：无人工批准、批准绑定版本过期、目标无权限、复制或推送中断。任何一个样本出现错误正式发布即停止结论发布并记录 finding。正式包需在另一目录重新计算 SHA，并把 acceptance summary、human approval 与 source revision 对回当前样本。

报告只陈述输入样本所测得的数值。缺少变体、真实平台、成本或人工验收时明确写入 limitation，不推算提升百分比。

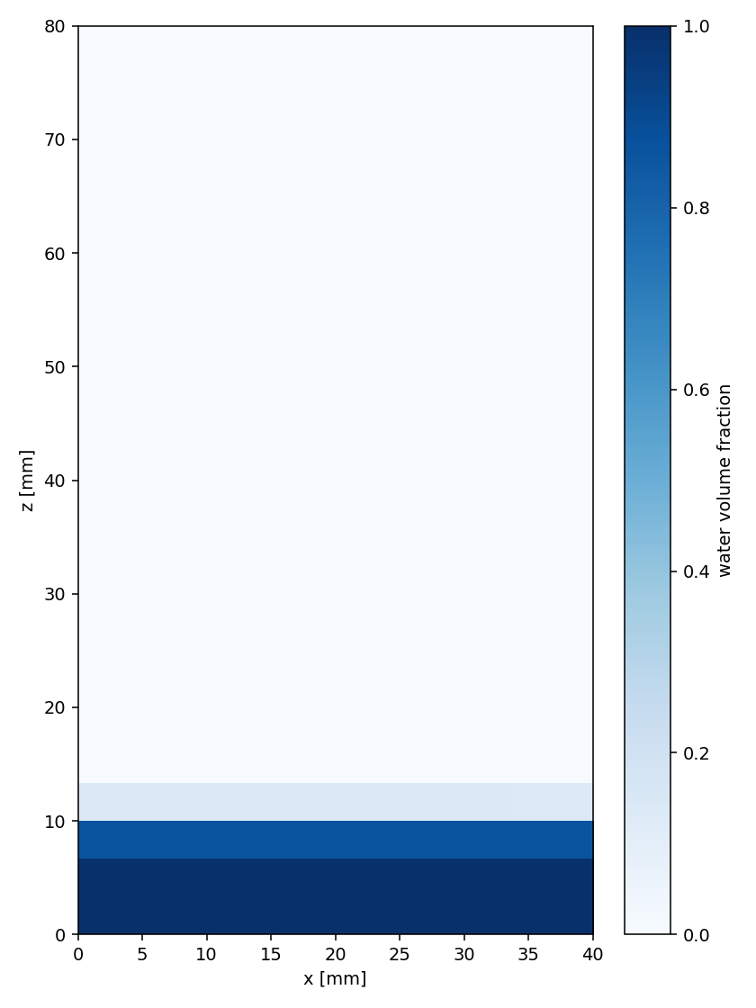
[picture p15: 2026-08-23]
benchmarks/simulation-v2/openfoam14-box/qualification-baseline/phase-distribution.png

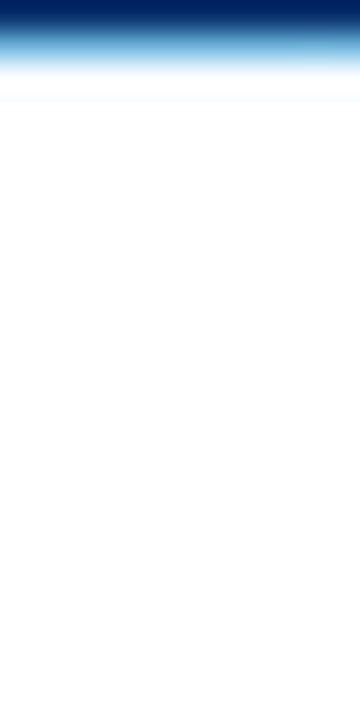
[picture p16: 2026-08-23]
benchmarks/simulation-v2/openfoam14-box/qualification-baseline/interface.gif

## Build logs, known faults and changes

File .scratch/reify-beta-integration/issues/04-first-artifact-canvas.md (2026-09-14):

# BI-04：首个真实成果接管画布

**What to build：** 从空项目一句需求得到真实 CAD，自然进入画布并继续修改。

**Blocked by：** BI-02 固定悬浮输入框完成真实对话

**Status：** implemented；自动流程通过，真实 Agent 首次建模待人工验收

- [ ] 成果由真实工具结果触发，绑定项目、会话和版本。
- [ ] 输入、阅读或选择文字时仅提示，不抢焦点；后续成果不擅自替换历史选择。
- [ ] 无成果、加载和失败有下一步；失败保留可用模型。
- [ ] 录制真实建模及继续修改，核对切换前后草稿和视角。
- [ ] 遵守整合计划的共同验收标准，提交真实操作证据。

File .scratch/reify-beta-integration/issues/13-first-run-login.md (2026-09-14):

# BI-13：首次启动登录并准备项目

**What to build：** 内测用户完成环境检查、真实登录和项目选择，进入工作区。

**Blocked by：** 无，可立即开始

**Status：** implemented；首启流程通过，真实账号取消和重试待人工验收

- [ ] 复用品牌资产与首启；中文步骤，基础 CAD 和可选组件分开。
- [ ] 固定本批支持 Windows、架构和 WSL 版本；已有 WSL 为首条保证路径。
- [ ] 真实账号登录由参与者完成，验证取消重试；凭据不进诊断。
- [ ] 首启不重复，旧配置可恢复；无 WSL 清楚引导并续接，未实测路径如实标记。
- [ ] 遵守整合计划的共同验收标准，提交真实操作证据。

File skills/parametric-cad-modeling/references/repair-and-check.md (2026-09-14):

# Repair and check

## Diagnose before editing

Classify the failure:

- Python or API error;
- empty or wrong result object;
- failed Boolean;
- invalid/open/inverted/self-intersecting B-Rep;
- wrong frame or transform;
- correct geometry with wrong design interpretation;
- acceptable nominal build that fails at a parameter boundary.

Read the exact error and the latest visual/geometry observation. Change one cause at a time.

## Boolean repair

Check that operands really overlap and are in the same frame. Remove exact tangency by extending cutters or using a justified geometric tolerance. Simplify compound cutters. Move decorative features after structural Booleans. If the operation still fails, isolate the smallest pair of shapes that reproduces it.

Do not hide a Boolean failure by returning the pre-cut solid or by exporting a different object than the one reviewed.

## Wrong pose or mirrored geometry

Probe front/back and both isometric directions. Check the world triad. Calculate a known endpoint or mating-plane normal. Repair the owning `Location`, axis, or sign; do not stack compensating rotations until one screenshot looks right.

## Fragile topology

Replace face-index selection with a geometric selector or named construction datum. Keep fillets late. If a feature can disappear over the supported parameter range, branch explicitly or narrow the declared range.

## Minimum regeneration matrix

Test the nominal value and meaningful low/high values for parameters that change thickness, spacing, count, angle, or clearance. For each build check:

- expected solid and occurrence count;
- positive bounds and volume;
- generic B-Rep validity;
- critical radii, distances, and alignments;
- visual orientation;
- assembly interference at relevant poses.

The checks report geometry, not whether the design meets the user's intent. Compare facts with the committed requirement and interface records yourself.

## Stop rules

Do not repeat an unchanged build. If geometry is sound but the requirement has two materially different readings, stop and ask. If an external standard or supplier interface is missing, identify the exact missing input rather than inventing it.

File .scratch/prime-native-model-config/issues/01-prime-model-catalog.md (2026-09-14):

# 01: 接入 Prime 原生模型目录

**What to build:** 用户在设置页浏览、搜索并选择 Prime Agent 当前版本提供的全部提供商和模型。列表、能力和认证状态均来自 Prime，不再由 Reify 写死。

**Blocked by:** None (can start immediately).

**Status:** ready-for-agent

- [ ] 设置页从 Prime `ModelRegistry` 获取完整目录，并区分完整目录与当前可用模型。
- [ ] 每个模型显示提供商、名称、图像输入和可用推理等级；不能把模型 ID 当自由文本输入。
- [ ] 认证状态绑定当前提供商；选择 Z.AI 时不能显示 ChatGPT 登录状态。
- [ ] Prime 更新、自定义模型变化或刷新后，界面无需修改硬编码名单即可显示变化。
- [ ] 目录在尚未启动对话会话时也能加载；加载、空目录和错误状态可恢复。

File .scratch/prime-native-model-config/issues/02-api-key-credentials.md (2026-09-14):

# 02: 完成 API key 配置链路

**What to build:** 用户可为任意 Prime API key 提供商填写、保存、替换、检查和删除凭据，并立即看到该提供商及模型变为可用或不可用。

**Blocked by:** 01: 接入 Prime 原生模型目录。

**Status:** ready-for-agent

- [ ] API key 通过主进程交给 Prime `AuthStorage` 持久保存，沿用 Prime 的文件锁、原子写入和文件权限。
- [ ] 保存后刷新认证状态和可用模型；失败时显示具体错误，不能显示虚假成功。
- [ ] 已保存的密钥不回传 renderer，不出现在日志、命令行、项目文件或普通设置文件中。
- [ ] 用户可替换密钥，也可只删除当前提供商的存储凭据；不能删除整个认证文件。
- [ ] 区分存储、环境变量、运行时和自定义模型配置等认证来源；环境变量凭据不得伪装成可由界面删除。
- [ ] Azure、Cloudflare 等需要额外字段的提供商不能被误判为只填一个 key 即配置完成。

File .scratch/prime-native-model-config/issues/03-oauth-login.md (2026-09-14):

# 03: 完成通用 OAuth 登录链路

**What to build:** 用户可对 Prime 注册的 OAuth 提供商完成登录、取消、重新登录和单提供商退出，界面只在 Prime 真正保存凭据后显示已连接。

**Blocked by:** 01: 接入 Prime 原生模型目录。

**Status:** ready-for-agent

- [ ] OAuth 提供商通过 Prime 注册表动态发现，包括扩展注册的 OAuth，不能写死为 ChatGPT。
- [ ] 登录支持打开浏览器、设备码、手工输入或回填 redirect URL、进度和取消。
- [ ] 浏览器成功页不能直接改变界面状态；必须等待 Prime 登录调用完成并保存凭据。
- [ ] OAuth token 由 Prime 保存和刷新，renderer 不接触 access token 或 refresh token。
- [ ] 重新登录替换当前提供商凭据；退出只清除当前提供商。
- [ ] ChatGPT、Claude 和 GitHub Copilot 的真实成功、取消、超时和恢复路径均有端到端验证。

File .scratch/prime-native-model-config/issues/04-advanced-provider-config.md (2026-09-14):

# 04: 支持高级与自定义提供商配置

**What to build:** 用户可完成非单一 API key 提供商及自定义端点的必要配置，并由 Prime 原生格式加载这些提供商和模型。

**Blocked by:** 01: 接入 Prime 原生模型目录；02: 完成 API key 配置链路。

**Status:** ready-for-agent

- [ ] Azure、Cloudflare、Bedrock 和 Vertex 按 Prime 要求显示对应的地址、账号、区域、项目或身份字段。
- [ ] 密钥与非敏感设置分开保存；密钥不得写入普通 Reify 设置。
- [ ] 用户可创建、修改和删除 Prime 原生自定义提供商、端点、请求协议和模型定义。
- [ ] 保存前使用 Prime 规则验证配置；错误指向具体字段，不能破坏已有可用配置。
- [ ] 保存后刷新 `ModelRegistry`，新增或覆盖的模型立即出现在完整目录中。
- [ ] 本地模型、OpenAI 兼容端点和至少一种云提供商完成真实连接验证。

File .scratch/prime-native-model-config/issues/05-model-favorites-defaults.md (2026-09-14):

# 05: 加入收藏、默认模型和快速切换

**What to build:** 用户可从完整目录收藏常用模型、排序、设置默认模型，并在对话中快速切换；配置沿用 Prime 的模型范围机制。

**Blocked by:** 01: 接入 Prime 原生模型目录；02: 完成 API key 配置链路；03: 完成通用 OAuth 登录链路。

**Status:** ready-for-agent

- [ ] 收藏列表保存精确的提供商、模型 ID 和该模型支持的推理等级，并映射到 Prime `enabledModels/scopedModels`。
- [ ] 用户可添加、删除和排序收藏；快速切换只遍历收藏模型。
- [ ] 用户可设置新会话默认模型和默认推理等级，并写入 Prime 原生默认模型配置。
- [ ] 切换当前模型立即生效，但不修改新会话默认模型。
- [ ] 收藏可包含暂未认证模型并明确标识；切换时进入对应 API key 或 OAuth 配置。
- [ ] 恢复会话优先恢复该会话原模型；删除收藏不强制改变正在运行的会话。
- [ ] Prime 的校验、推理等级限制和默认回退规则保持有效。

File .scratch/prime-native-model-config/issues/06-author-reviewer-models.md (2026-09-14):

# 06: 统一 Author 与 Reviewer 模型配置

**What to build:** 用户为 Author 和 Reviewer 分别选择默认模型及推理等级，两者共享同一套 Prime 模型目录、收藏和凭据。

**Blocked by:** 05: 加入收藏、默认模型和快速切换。

**Status:** ready-for-agent

- [ ] Author 与 Reviewer 使用同一个动态模型选择控件，不再使用独立自由文本或硬编码提供商。
- [ ] 两个角色可保存不同的默认模型和推理等级。
- [ ] 认证状态和凭据按提供商共用，不能因角色不同重复登录。
- [ ] 选择不可用模型时进入对应认证流程；取消后保留原选择。
- [ ] Reviewer 继承、固定模型和显式关闭等现有语义有清楚且可恢复的界面状态。
- [ ] 重启应用及恢复会话后，两个角色的选择与实际运行模型一致。

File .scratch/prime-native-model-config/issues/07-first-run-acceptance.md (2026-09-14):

# 07: 统一首次启动并完成真实验收

**What to build:** 新用户无需理解 Prime 配置文件，即可在首次启动中选择任意受支持提供商、完成认证、选择模型并开始第一段对话。

**Blocked by:** 02: 完成 API key 配置链路；03: 完成通用 OAuth 登录链路；04: 支持高级与自定义提供商配置；05: 加入收藏、默认模型和快速切换；06: 统一 Author 与 Reviewer 模型配置。

**Status:** ready-for-agent

- [ ] 首次启动根据所选提供商显示正确的 API key、OAuth 或高级配置流程，不再默认要求 ChatGPT 登录。
- [ ] 完成认证后只能选择该提供商实际可用的模型，并可同时设置默认模型与推理等级。
- [ ] 旧的 Reify 模型设置可迁移；无效 provider ID 和模型 ID 有明确恢复路径。
- [ ] 重启应用、创建新会话和恢复旧会话后，默认、当前及恢复模型符合 Prime 原生优先级。
- [ ] 在干净 Windows 安装环境中真实验证 API key、OAuth、收藏切换、退出登录和失败重试。
- [ ] 自动测试覆盖目录刷新、凭据隔离、秘密不泄漏、OAuth 完成判定、推理等级约束和设置持久化。

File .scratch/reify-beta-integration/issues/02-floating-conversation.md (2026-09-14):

# BI-02：固定悬浮输入框完成真实对话

**What to build：** 用户用同一输入框发送需求、查看真实回复，切换完整对话和画布。

**Blocked by：** BI-01 打开真实 STEP，进入新版工作台

**Status：** implemented；切换专项通过，真实账号对话待人工验收

- [ ] 接真实 Agent，不带假项目和示例消息。
- [ ] 输入框在窗口下半部，切换全程位置和尺寸不变；对话在其背后展开。
- [ ] 草稿、附件、焦点、滚动、视角和选择保留；快速反复切换无闪白。
- [ ] 统一快捷键和提示；替换旧三档顶部模式导航；键盘和减少动画可用。
- [ ] 遵守整合计划的共同验收标准，提交真实操作证据。

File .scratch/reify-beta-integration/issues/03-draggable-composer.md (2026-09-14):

# BI-03：拖动输入框并恢复位置

**What to build：** 拖动细线调整位置，缩放窗口和重启后继续使用。

**Blocked by：** BI-02 固定悬浮输入框完成真实对话

**Status：** complete；拖动、保存、缩放、复位专项通过

- [ ] 点击切换与拖动不误触；双击重置不触发两次切换；提供键盘重置。
- [ ] 按窗口比例保存并限制边界；最大化、短窗口、高缩放、跨屏和异常存储可恢复。
- [ ] 动画起点跟随输入框实际位置，输入框本体不动。
- [ ] 指针取消或失焦后不粘住；默认位置不挡关键操作；主动移动后可重置。
- [ ] 遵守整合计划的共同验收标准，提交真实操作证据。

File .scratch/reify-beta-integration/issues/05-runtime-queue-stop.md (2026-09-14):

# BI-05：运行中追加、停止和继续

**What to build：** 看到真实任务状态，排队需求、停止任务并继续工作。

**Blocked by：** BI-02 固定悬浮输入框完成真实对话

**Status：** complete；队列、停止、备注和失败路径自动验收通过

- [ ] 复用现有队列；完成后执行、编辑取消和仅记备注均真实生效。
- [ ] 停止并修改等旧任务结束；停止失败可重试，不启动重复修改。
- [ ] 无可靠分母不显示百分比和剩余时间；移除假进度。
- [ ] 状态变化不重建输入框；验证正常完成、停止竞争和工具失败。
- [ ] 遵守整合计划的共同验收标准，提交真实操作证据。

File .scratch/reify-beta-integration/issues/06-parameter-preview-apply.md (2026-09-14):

# BI-06：预览并应用真实参数修改

**What to build：** 选择有绑定部位，在新版面板修改、预览、重置并应用参数。

**Blocked by：** BI-01 打开真实 STEP，进入新版工作台

**Status：** complete；预览、迟到响应、失败、重置和应用自动验收通过

- [ ] 复用现有绑定和授权应用，显示单位、范围与已应用值。
- [ ] 无绑定提供对象引用入口，不伪造任意 STEP 调参。
- [ ] 迟到预览不覆盖新值；应用后几何和版本一致。
- [ ] 面板可关闭恢复，缩放不截断数值与按钮；用真实孔径核验。
- [ ] 遵守整合计划的共同验收标准，提交真实操作证据。

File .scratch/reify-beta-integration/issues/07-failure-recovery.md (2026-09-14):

# BI-07：修改失败后定位并修复

**What to build：** 保留上一可用模型，改值重试或让 Agent 修复失败修改。

**Blocked by：** BI-04 首个真实成果接管画布；BI-06 预览并应用真实参数修改

**Status：** complete；失败保留成果、改值重试和恢复自动验收通过

- [ ] 清楚区分失败修改和可用成果；显示真实错误与对象。
- [ ] Agent 修复携带失败操作和版本，引用可检查。
- [ ] 失败面板关闭后仍可找到状态；日志按需展开。
- [ ] 真实无效修改、修复、导出闭环；重复操作不应用错误成果。
- [ ] 遵守整合计划的共同验收标准，提交真实操作证据。

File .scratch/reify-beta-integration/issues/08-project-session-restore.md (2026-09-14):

# BI-08：切换项目、会话和重启恢复

**What to build：** 新版导航打开、新建、命名和切换真实项目与会话，重启后继续。

**Blocked by：** BI-04 首个真实成果接管画布；BI-05 运行中追加、停止和继续

**Status：** complete；项目、会话、草稿和重启恢复自动验收通过

- [ ] 复用现有存储，不使用写死最近项目。
- [ ] 草稿、引用、队列、成果和任务按项目会话隔离；位置作为用户布局保存。
- [ ] 迟到任务事件不串项目；重启显示真实中断及恢复入口。
- [ ] 在两个项目验证运行中切换、返回和重启；旧项目可打开。
- [ ] 遵守整合计划的共同验收标准，提交真实操作证据。

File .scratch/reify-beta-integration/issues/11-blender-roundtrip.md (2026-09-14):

# BI-11：Blender 编辑后返回刷新

**What to build：** 在新版预览场景，打开外部 Blender，保存后返回更新。

**Blocked by：** BI-01 打开真实 STEP，进入新版工作台

**Status：** implemented；外部编辑链路已接通，最终 Windows 包人工往返待验收

- [ ] 复用预览、渲染和外部编辑，不新增跨平台内嵌框架。
- [ ] 返回以新文件身份刷新，不用旧渲染冒充新结果。
- [ ] 缺组件、启动失败、未保存返回、渲染失败均有下一步。
- [ ] 在声明的 Windows/WSL 环境实际打开、保存和刷新；未验证环境不标可用。
- [ ] 遵守整合计划的共同验收标准，提交真实操作证据。

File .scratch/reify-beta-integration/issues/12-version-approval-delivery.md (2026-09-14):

# BI-12：新版版本、批准和交付入口

**What to build：** 找到已有比较、恢复、审查和批准能力，完成真实本地交付。

**Blocked by：** BI-01 打开真实 STEP，进入新版工作台

**Status：** complete；比较、恢复、批准和本地交付自动验收通过

- [ ] 复用原能力；新版导航不丢版本比较、恢复与审查入口。
- [ ] 成果、检查和批准版本一致；过期或撤销不能显示通过。
- [ ] 保留本地 OS 身份和权限边界，不声称已接组织身份。
- [ ] 实际交付并独立核验清单；过期批准阻止发布，不可写目录可恢复。
- [ ] 远端继续显式启用；验收默认本地包，不要求推送。
- [ ] 遵守整合计划的共同验收标准，提交真实操作证据。

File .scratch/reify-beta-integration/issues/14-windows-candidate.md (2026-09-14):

# BI-14：安装候选包完成主流程

**What to build：** 安装 Windows 候选包，建模、改参数、失败恢复、导出并继续旧项目。

**Blocked by：** BI-03 拖动输入框并恢复位置；BI-07 修改失败后定位并修复；BI-08 切换项目、会话和重启恢复；BI-13 首次启动登录并准备项目

**Status：** candidate-built；安装、启动、快捷方式和卸载项通过，升级回退及真实账号主流程待人工验收

- [ ] 保存现有改动并固定代码版本；记录提交或完整补丁身份、依赖锁定和包哈希。
- [ ] 打包包含图标字体及运行时，不依赖开发服务器或 Downloads 设计文件。
- [ ] 从安装程序实际完成登录到导出和重启；替身不能代替真实账号验收。
- [ ] 验证旧版本升级、项目保留、手动回退和卸载保留项目。
- [ ] 记录签名状态；未签名如实说明，只供组织允许的内测环境，不要求关闭安全机制。
- [ ] 遵守整合计划的共同验收标准，提交真实操作证据。

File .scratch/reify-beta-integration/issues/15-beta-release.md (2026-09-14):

# BI-15：最终验收并交付内测包

**What to build：** 交付可核验的 Windows 安装包、使用范围、已知限制和反馈方法。

**Blocked by：** BI-09 概念图比较并引用到对话；BI-10 真实仿真与过期结果查看；BI-11 Blender 编辑后返回刷新；BI-12 新版版本、批准和交付入口；BI-14 安装候选包完成主流程

**Status：** awaiting-user-acceptance；候选包和证据已交付，独立工程师主流程待验收

- [ ] 最终代码重新构建并验收，旧候选包测试不能代替最终包。
- [ ] 安装后按视觉矩阵截图和切换录屏；修复遮挡、错位、丢输入、串项目和假成功。
- [ ] 至少一位未参与开发的工程师独立跑主流程；阻断修复后重验，未执行保持待验收。
- [ ] 不保留可点击的无行为占位入口；声明能力都通过必要真实回归。
- [ ] Windows 目录交付安装包、SHA-256、版本、环境、限制、升级回退及去敏反馈方法。
- [ ] 逐票关联证据；原 Mac/Linux、组织身份与收益对照不自动标完成。
- [ ] 遵守整合计划的共同验收标准，提交真实操作证据。

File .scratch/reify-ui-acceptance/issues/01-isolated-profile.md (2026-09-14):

# UX-01：隔离测试配置，恢复正常启动

**What to build:** 真实安装版使用用户自己的项目；测试使用独立配置，失效目录能重新选择。

**Blocked by:** 无，可立即开始

**Status:** ready-for-agent

- [ ] 显式测试配置路径由主进程设置并验证；测试前后正式配置字节一致，测试目录不进入最近项目。
- [ ] 不存在目录在启动 Agent 前被识别，给出选择项目入口，保留草稿；WSL 不可用与目录缺失分别提示。
- [ ] 用有效项目取得真实 RPC 响应；再通过界面发送请求取得真实回复。get_state 不等于账号调用成功。
- [ ] 附真实操作和视觉证据；未执行项明确标记，不用已有测试通过代替本票验收。

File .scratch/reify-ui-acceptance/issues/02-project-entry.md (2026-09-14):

# UX-02：参考 ChatGPT 重建左侧导航，显露项目入口

**What to build:** 用户从常驻、可折叠侧栏找到新建项目和打开项目，进入真实工作区。

**Blocked by:** 无，可立即开始

**Status:** ready-for-agent

- [ ] 修复当前创建入口藏在画布项目下拉中、对话模式难以发现的问题；左侧导航直接显示“新建项目”和“打开项目”，无需先切换画布。
- [ ] 参考 ChatGPT 的导航层级：顶部新对话与搜索，中部项目及历史，底部设置；使用 Reify 品牌和视觉，不照搬 ChatGPT 品牌。
- [ ] 侧栏可折叠；对话、画布、设置、工作流和记录页均有明确的展开入口与当前位置，避免重复顶部导航和第二套项目菜单。

- [ ] 两次点击内打开创建表单；名称、位置、取消、同名、不可写路径有完整处理。
- [ ] 最近项目来自真实记录；可切换、移除失效记录，重启恢复；运行中切换遵守现有任务约束。
- [ ] 画布模式、设置页和短窗口都能找到项目入口；复用现有品牌资产，与参考稿逐项对照。
- [ ] 附真实操作和视觉证据；未执行项明确标记，不用已有测试通过代替本票验收。

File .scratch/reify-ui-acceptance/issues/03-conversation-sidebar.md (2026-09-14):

# UX-03：替换生硬的对话弹出列表，采用 ChatGPT 式历史侧栏

**What to build:** 用户在 ChatGPT 式侧栏新建、查找、切换和改名对话。

**Blocked by:** UX-02

**Status:** ready-for-agent

- [ ] 移除聊天标题栏里隐藏历史的更多按钮及狭窄弹出列表；历史放在左侧，当前对话与项目关系一眼可辨。
- [ ] 对话行以标题为主，日期分组；重命名等操作收进悬停或键盘可达的更多菜单，避免每行固定堆叠评分、时间和按钮。
- [ ] 顶部固定“新对话”和搜索；支持搜索当前项目会话，明确标注搜索范围；无结果可清除搜索。
- [ ] 项目下展开其会话；切换项目后列表刷新且不闪现上一项目内容，加载与失败不伪装成空历史。

- [ ] 明确区分项目与会话；当前会话高亮，按日期分组，长标题截断但可查看全名。
- [ ] 新对话无需立即启动 Agent；真实会话持久化，改名跨重启保留；菜单支持键盘与取消。
- [ ] 切换后消息、附件与成果归属正确，迟到请求不串项目；空、加载、失败均有状态。
- [ ] 附真实操作和视觉证据；未执行项明确标记，不用已有测试通过代替本票验收。

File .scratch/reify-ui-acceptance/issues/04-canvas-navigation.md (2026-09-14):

# UX-04：折叠侧栏并保持悬浮输入框

**What to build:** 从对话进入大画布，侧栏可折叠，输入框始终稳定可用。

**Blocked by:** UX-02、UX-03

**Status:** ready-for-agent

- [ ] 切换十次不移动或重建输入框；草稿、附件、焦点、历史滚动、相机和选择保留。
- [ ] 拖动与点击不误触，双击和键盘可复位；位置按窗口保存并限制边界。
- [ ] 1366×768、1920×1080、920×680及125%/150%缩放检查；不遮挡关键按钮，减少动画模式可用。
- [ ] 附真实操作和视觉证据；未执行项明确标记，不用已有测试通过代替本票验收。

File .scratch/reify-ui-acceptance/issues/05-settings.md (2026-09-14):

# UX-05：清除设置页旧 Vercel 风格，重做配置布局

**What to build:** 用户在统一视觉的设置页选择项目、模型、审查方式并保存，完成登录和运行环境检查。

**Blocked by:** 无，可立即开始

**Status:** ready-for-agent

- [ ] 明确移除旧黑底、深灰表单、蓝色强调、重复描边卡片和过小标签；不是仅替换背景色。
- [ ] 设置按项目、账号与模型、运行环境、高级选项分组；采用清晰的栏目与表单行，减少等大卡片堆叠，主要操作位置稳定。
- [ ] 输入框、下拉、登录状态、安装进展、错误、保存反馈、焦点和禁用状态全部使用同一套 Reify 视觉。
- [ ] 展开所有设置分组和下拉后截图检查，不能只验收页面首屏；长路径和错误文字完整可读。

- [ ] 统一暖白、石色、深绿、字体及控件，替换黑色卡片和蓝色强调色；基础设置与高级设置分组。
- [ ] 保存有成功、失败及未保存反馈；切页与再次打开不丢状态，保存失败不显示成功。
- [ ] 真实登录、取消、重试和已有登录分别验证；依赖检查显示实际状态，安装期间可见进展与失败恢复。
- [ ] 附真实操作和视觉证据；未执行项明确标记，不用已有测试通过代替本票验收。

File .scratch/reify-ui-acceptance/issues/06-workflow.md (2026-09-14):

# UX-06：清除工作流页旧 Vercel 风格，重做流程浏览与编辑

**What to build:** 用户从新版工作流页选择流程、查看阶段、保存自定义流程并用于新任务。

**Blocked by:** 无，可立即开始

**Status:** ready-for-agent

- [ ] 移除黑色流程库、蓝色选中阶段、黑色 YAML 编辑区、密集标签卡片；阶段选中、按钮、弹窗及错误使用 Reify 暖白、石色、深绿。
- [ ] 页面以选择流程、理解阶段、查看规则为主；源码编辑按需展开，不能默认占据半屏迫使普通用户读 YAML。
- [ ] 流程列表、阶段路径、详情和保存/采用操作层次清楚；长流程在局部滚动，页面本身不被撑宽。
- [ ] 为列表、选中阶段、源码展开、校验失败、保存成功和采用状态分别留视觉证据。

- [ ] 流程列表、阶段图和详情符合统一视觉；源码按需展开，短窗口无整页横向溢出。
- [ ] 保存校验错误可定位；保存后选中正确的 ID 与版本，再次打开一致。
- [ ] 采用流程只影响新任务；已有任务版本不变，空列表、读取失败有下一步。
- [ ] 附真实操作和视觉证据；未执行项明确标记，不用已有测试通过代替本票验收。

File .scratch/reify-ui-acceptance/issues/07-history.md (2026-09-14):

# UX-07：清除记录页及评价面板旧 Vercel 风格

**What to build:** 用户在新版记录页查看真实会话与工具结果，提交评价，检查经验候选。

**Blocked by:** 无，可立即开始

**Status:** ready-for-agent

- [ ] 移除黑色记录列表、深色气泡、蓝色选择框、黑色评分和经验浮窗，统一 Reify 的文字、表单、边框、颜色及阴影。
- [ ] 默认优先展示可读记录，评分与经验处理按需展开；避免底部常驻密集控件挤压列表。
- [ ] 对话历史负责继续工作，记录页负责回看与评价；导航名称和说明清楚区分两者。

- [ ] 列表、搜索、阅读区和评价统一视觉；工具详情按需展开，长内容可读，快速切换不显示旧请求结果。
- [ ] 空、加载、读取失败、无搜索结果各自明确；评价保存后能再次读取。
- [ ] 经验处理不显示假百分比；真实候选、验证、采用状态明确，未验证不可采用。
- [ ] 附真实操作和视觉证据；未执行项明确标记，不用已有测试通过代替本票验收。

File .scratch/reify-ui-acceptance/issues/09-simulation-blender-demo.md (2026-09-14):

# UX-09：验证仿真与 Blender 往返

**What to build:** 同一 Demo 查看真实结构分析结果，并在 Blender 保存修改后返回刷新。

**Blocked by:** UX-08

**Status:** ready-for-agent

- [ ] 分析前确定载荷区域、固定面、材料和单位；不把目标阈值当计算结果。
- [ ] 查看应力与位移，核对色标及来源；修改模型后旧结果标记过期，重新计算对应新版本。
- [ ] 真实 Windows/WSL Blender 打开、修改、保存、返回刷新；未保存和缺组件都有处理。
- [ ] 附真实操作和视觉证据；未执行项明确标记，不用已有测试通过代替本票验收。

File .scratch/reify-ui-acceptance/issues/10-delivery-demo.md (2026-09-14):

# UX-10：比较版本并完成批准交付

**What to build:** 用户比较和恢复 Demo 版本，批准当前成果，导出可独立核对的交付文件。

**Blocked by:** UX-08

**Status:** ready-for-agent

- [ ] 版本、几何、检查和批准对应一致；过期或撤销批准不能沿用。
- [ ] 实际本地交付后重新打开 STEP，检查尺寸、文件清单和版本；不要求远端发布。
- [ ] 不可写目录失败后可换目录重试；恢复旧版本后有明确状态。
- [ ] 附真实操作和视觉证据；未执行项明确标记，不用已有测试通过代替本票验收。

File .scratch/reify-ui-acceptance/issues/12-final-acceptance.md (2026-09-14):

# UX-12：验收最终包并交付证据

**What to build:** 对最终安装包完整执行 Demo 和逐页视觉检查，修复阻断后交付。

**Blocked by:** UX-09、UX-10、UX-11

**Status:** ready-for-agent

- [ ] 专项清查旧 Vercel 风格残留：设置全部分组、工作流阶段与源码、记录与评分、项目菜单、会话菜单、授权弹窗、错误提示、下拉和禁用状态；逐项截图关闭问题。
- [ ] 首次使用者从对话和画布均能直接找到新建项目，能说明当前项目与会话；不得用熟悉代码者知道隐藏入口作为通过依据。

- [ ] 最终包经 Computer Use 重新跑完整主流程；修复后生成新哈希并重验受影响路径。
- [ ] 参考稿和实际截图同尺寸对照，包含设置、流程、记录、侧栏及所有关键弹窗；记录差异而非主观声明一致。
- [ ] 安装到导出留截图与步骤记录；有录屏能力则录制，无能力如实说明。
- [ ] 至少一名未参与开发的工程师独立试用；未完成保持待验收。
- [ ] 交付安装包、哈希、环境、已知限制、反馈方法和逐票证据；跳过或受阻不得算通过。
- [ ] 附真实操作和视觉证据；未执行项明确标记，不用已有测试通过代替本票验收。

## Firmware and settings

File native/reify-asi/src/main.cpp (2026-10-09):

// reify-asi entry point. See README.md for the CLI and exit codes.
#include "reify_asi.hpp"

#include <cstdio>
#include <exception>

int main(int argc, char** argv)
{
  try
  {
    return runCli(argc, argv);
  }
  catch (const CliError& e)
  {
    std::fprintf(stderr, "reify-asi: %s\n", e.what());
    return e.code;
  }
  catch (const std::exception& e)
  {
    std::fprintf(stderr, "reify-asi: unexpected error: %s\n", e.what());
    return EXIT_ANALYSIS;
  }
  catch (...)
  {
    std::fprintf(stderr, "reify-asi: unexpected error\n");
    return EXIT_ANALYSIS;
  }
}

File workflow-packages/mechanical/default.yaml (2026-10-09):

schema: 1
id: mechanical.default
description: Reason from physics and whole-system form, recurse only when complexity warrants, then integrate and verify the real design.
tags: [cad, mechanical, default, recursive-design]
version: 4.0.0
workflow:
  schema: 1
  id: mechanical.default
  version: 4.0.0
  parametersSchema: {type: object, additionalProperties: false}
  initialPhase: plan
  versionControl:
    init: true
    allowRemote: false
    phases:
      plan: {onExit: [commit]}
  phases:
    plan:
      purpose: Understand the engineering problem, establish the physics and whole-system shape, and choose a sound decomposition before detailed CAD.
      guidance: >-
        Plan the engineering task itself, not the workflow. Before detailed geometry,
        understand what the device is physically doing and establish a coherent whole.
        The amount of analysis should match the problem, but important dimensions and
        interfaces must have reasons.

        Start from the governing physics. Identify loads, constraints, motion, power
        flow, fluid paths, heat paths, electromagnetic effects, contact, friction,
        tolerances, manufacturing limits, or other first-order mechanisms that can
        determine the design. Use the persistent IPython kernel as an engineering
        notebook: calculate quantities, compare options, search references when useful,
        and keep compact Python variables for requirements, assumptions, estimates,
        architecture, interfaces, and unresolved questions. Prefer calculations and
        evidence over arbitrary dimensions.

        Establish a rough whole-system form before delegating detailed work. Define the
        main envelope, datums and axes, spatial arrangement, moving volumes, force or
        energy paths, assembly direction, and the approximate location of major
        functions. A concept image or simple spatial sketch is optional. The goal is
        not a decorative concept; it is enough global shape to keep later parts
        mutually compatible.

        Then choose the architecture. Decide which functions belong together, what the
        main subsystems or parts are, what space each receives, and which interfaces
        are already constrained. Do not delegate ambiguity. A child should receive a
        bounded engineering problem only after the parent understands the surrounding
        system well enough to state its goal, relevant physics, envelope, datums,
        interfaces, neighboring parts, fixed constraints, freedoms, and expected
        outputs.

        Recursion is a complexity decision, not a goal. If one agent can understand and
        design the whole object coherently, keep the work local. If the whole assembly
        is coherent but contains several separable parts, design the assembly first and
        then delegate bounded part work. If a subsystem is itself a substantial
        engineering problem, delegate that subsystem and allow its child agent to apply
        the same method recursively.

        Commit the initial plan as plan. Keep current requirements and acceptance
        criteria separate from revisable execution strategy. Later user instructions,
        measurements, calculations, or returned child results may make the Plan stale;
        update it in COOK rather than treating the first plan as immutable.

        Happy-path examples are normative examples of reasoning, not fixed templates:

        Example A — simple load-bearing wall bracket, no delegation.
        The request is a wall-mounted bracket holding a 20 mm tube whose center is
        50 mm from the wall under a 100 N radial load, made by FDM. The parent extracts
        the load, offset, tube size, manufacturing process, mounting assumptions and
        safety needs. It sketches one coherent form: wall plate, cantilever, clamp and
        fastener pattern. It calculates the root bending moment, fastener force couple,
        rough section requirement, edge distances and print-orientation implications.
        It selects dimensions from those results, then proceeds to one parametric model.
        It does not create separate wall-plate, arm and clamp agents merely to obtain
        parallelism. The object is small enough that splitting would lose coherence.
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

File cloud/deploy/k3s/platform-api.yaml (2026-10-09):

# Platform API (plan section 5) in reify-system.
#   port 8080  public API. Reached only through Caddy (/v1, /invite, /reset).
#              Service platform-api, which Caddy uses.
#   port 8081  internal API (/internal/*). Reached only from workspace pods.
#              Service platform-api-internal, which only the reify-ws egress policy allows.
#              Caddy has no route to it, and the public Service does not expose it.
# The image tag is set in kustomization.yaml (images: reify/platform-api).
# Every variable that src/config.ts reads is listed here or in the Secret (secret.template.yaml).
apiVersion: v1
kind: ServiceAccount
metadata:
  name: platform-api
  namespace: reify-system
  labels:
    app.kubernetes.io/name: platform-api
    app.kubernetes.io/part-of: reify
---
apiVersion: v1
kind: ConfigMap
metadata:
  name: platform-api-config
  namespace: reify-system
  labels:
    app.kubernetes.io/name: platform-api
    app.kubernetes.io/part-of: reify
data:
  PORT: "8080"
  INTERNAL_PORT: "8081"
  # Caddy is the only proxy in front of the API. Its X-Forwarded-For carries the client address (plan 5.1).
  TRUST_PROXY: "true"
  MAX_ACTIVE_WORKSPACES: "6"
  WORKSPACE_NAMESPACE: "reify-ws"
  # Must match the tag of the image that cloud/platform-api/build.sh imported (see cloud/deploy/README.md).
  WORKSPACE_IMAGE: "reify-workspace:REPLACE_WITH_IMAGE_TAG"
  # Same file as the image copies to this path (Dockerfile). Rendered once per start by the controller.
  WORKSPACE_TEMPLATE_PATH: "/app/cloud/deploy/k3s/workspace-template.yaml"
  # Set by verify-runtime.sh (plan 0.5). RuntimeDefault and "true" are the defaults that passed the plan.
  WORKSPACE_SECCOMP_TYPE: "RuntimeDefault"
  WORKSPACE_HOST_USERS: "true"
  # Placeholder. The Windows host address that mihomo listens on, port 7890, without credentials.
  # The same address must appear in reify-ws-policy.yaml (ipBlock).
  HTTPS_PROXY_FOR_WORKSPACES: "http://REPLACE_WITH_WINDOWS_HOST_IP:7890"
  # Gateway address pattern. {name} is the workspace k8s name, the Service name in reify-ws.
  GATEWAY_URL_PATTERN: "ws://{name}.reify-ws.svc:7000/"
  # Base URL of the internal API. Workspaces report activity here (ACTIVITY_URL is built from it).
  # Cluster-internal only, and the host is the internal Service, not the public one.
  PLATFORM_INTERNAL_URL: "http://platform-api-internal.reify-system.svc.cluster.local:8081"
---
apiVersion: apps/v1
kind: Deployment
metadata:
  name: platform-api
  namespace: reify-system
  labels:
    app.kubernetes.io/name: platform-api
    app.kubernetes.io/part-of: reify
spec:
  replicas: 1
  # One replica. Recreate avoids two controllers running at once.
  strategy:
    type: Recreate
  selector:
    matchLabels:
      app.kubernetes.io/name: platform-api
  template:
    metadata:
      labels:
        app.kubernetes.io/name: platform-api
        app.kubernetes.io/part-of: reify
    spec:
      serviceAccountName: platform-api
      # The controller needs the API token to manage workspaces in reify-ws (platform-api-rbac.yaml).
      automountServiceAccountToken: true
      securityContext:
        runAsNonRoot: true
        runAsUser: 10001
        runAsGroup: 10001
        seccompProfile:
          type: RuntimeDefault
      containers:
        - name: platform-api
          # Replaced through kustomization.yaml (images). Built by cloud/platform-api/build.sh.
          image: reify/platform-api:REPLACE_WITH_TAG
          imagePullPolicy: IfNotPresent
          env:
            # tsx writes its compile cache to the temp directory. The root filesystem is read-only.
            - name: TMPDIR
              value: /tmp
          ports:
            - name: http
              containerPort: 8080
            - name: internal
              containerPort: 8081
          envFrom:
            - configMapRef:
                name: platform-api-config
            - secretRef:
                name: reify-platform-secrets
          readinessProbe:
            httpGet:
              path: /v1/healthz
              port: http
            initialDelaySeconds: 5
            periodSeconds: 10
          livenessProbe:
            httpGet:
              path: /v1/healthz
              port: http
            initialDelaySeconds: 30
            periodSeconds: 30
          resources:
            requests:
              cpu: 250m
              memory: 256Mi
            limits:
              memory: 1Gi
          securityContext:
            allowPrivilegeEscalation: false
            readOnlyRootFilesystem: true
            capabilities:
              drop: ["ALL"]
          volumeMounts:
            - name: tmp
              mountPath: /tmp
      volumes:
        - name: tmp
          emptyDir: {}
---
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

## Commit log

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2026-08-18 fix 0.6.1 P0 correctness: structured spec tools, strain math, fail-closed physics, analyze simulation guard
    cad_simulate / cad_optimize / cad_generate_drawing / cad_render_scene now take
    structured arguments; the harness canonicalizes specs into run-scoped
    evidence/<kind>/<id>/spec.json, so read-only phases (review/investigate) can
    run simulation without creating spec files and no tool exposes an outputDir
    mutation-policy bypass. Without an active run the tools fall back to
    .pi-cad/adhoc/<kind>/.
    Simulation correctness:
    - fourth solve() return is the deformation gradient F, not strain; strain is
    now 0.5*((F-I)+(F-I)^T) with F reported separately
    - reaction is the constrained-DOF internal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
2026-08-18 fix 0.6.1 review round: load-case provenance, pre-solve artifact binding, live doctor, CI
    Evidence identity: spec-driven evidence (simulation, optimization) is now
    identified by kind + artifactHash + specHash, so multiple load cases on the
    same artifact (normal / peak / shock / preload) coexist instead of
    overwriting each other; re-running one case replaces only itself, a stale
    candidate still invalidates all of them at once, and visual/geometry stay
    latest-wins. EvidenceRef records specHash and candidate manifests surface it.
    Artifact provenance: cadctl hashes the STEP BEFORE the solve and binds
    evidence to that pre-solve hash; the backend re-hashes after the solve and
    the CLI re-verifies,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
2026-08-18 fix strict spec schemas + CI fresh-install failures (ezdxf, venv shadowing, hardcoded paths)
    Strict object schemas: every engineering-spec object in cad_simulate,
    cad_optimize, cad_generate_drawing, and cad_render_scene now carries
    additionalProperties: false, so a typo'd key fails closed at the tool
    boundary instead of silently falling back to a default ("distribut" would
    default distribute to total; "dof" would default dofs to [0,1,2] and
    over-constrain the model). Region union members are strict as well.
    Backend key whitelists: validate_spec() rejects unknown keys on spec,
    physics, materials[], mesh, loads[], constraints[] (with the alias keys the
    backend reads still accepted), so direct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
2026-08-18 ci: install libglu1-mesa for gmsh on headless Linux
    The gmsh wheel's bundled libgmsh dlopens libGLU.so.1, which is absent on
    GitHub runners and minimal headless servers, so STEP meshing (and the
    artifact-mutation test that meshes a STEP) failed with OSError while the
    mesh.box path stayed green. Documented the system dependency in README.
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2026-08-18 fix P0 plugin composition: Pi-CAD owns a tool-policy overlay, not the global tool set
    setActiveTools() replaces the ENTIRE session tool set, so calling it with
    toolsForPhase(phase) uninstalled every other extension's tools (Goal,
    Ralph, ...) whenever a CAD run persisted state or a session started. The
    goal_complete/goal_blocked/goal_wait special-case patch treated the
    symptom; this fixes the ownership boundary instead.
    applyCadToolOverlay() now:
    - reads the actual current active set via getActiveTools();
    - removes and re-adds ONLY the Pi-CAD-owned cad_* tools per phase;
    - never touches builtin or other plugins' tools, including ones the user
    deliberately disabled (getAllTools is used only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
2026-08-19 fix 0.7 review: not_converged evidence gate, input provenance, viscosity contract
    P0: convergence is execution validity, not judgment
    - flow/thermal return status=not_converged when no residualTarget is
    declared or the declared target is missed; raw fields still returned
    for diagnosis but the harness records no simulation evidence, so an
    unconverged run can never close a required case
    - TS regression drives tool_result directly: not_converged records
    nothing and blocks accepted; solved closes the case
    P0: evidence re-verifies its hash-bound inputs
    - EvidenceRef.inputArtifacts [{path, sha256, role}] persisted from the
    envelope; flow/thermal CLI emit spec + artifact + fluidDomain
    -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
2026-08-19 0.8 M1: route ontology + workflow compiler, schema v4
    Replace the seven hand-written workflows with a compiler that derives
    processes from hierarchical routes:
    Route = objective (analyze|convert|design) x lineage (greenfield|legacy|
    hybrid) x structure (part|assembly) x maturity (prototype|engineering|
    manufacturing|release)
    - cad_route V2 takes the full tuple in one call; cross-field rules fail
    closed (design requires the tuple, analyze/convert forbid it).
    - quick is deleted: the fast path is *derived* (greenfield/part compiles
    to requirements -> part_design -> build -> review), never selected.
    - concept/review leave the maturity enum; maturity is the reality floor
    and only ov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
2026-08-19 0.8 M3: reroute with obligation monotonicity + interference sensor
    Reroute (whitepaper section 8):
    - cad_reroute({route fields, reason}) — no target phase, ever. The
    harness resumes at earliestUnmetPhase(): unmet baseline -> baseline
    phase; missing records -> the phase owing the earliest record; no
    current artifact -> source phase; unmet review evidence -> review
    phase. Reroute never grants progress.
    - Autonomy is mechanical: obligationsOf(old) ⊆ obligationsOf(new) AND
    maturity rank non-decreasing. Any drop needs the harness-issued
    one-time rerouteAuthorityToken.
    - Authority flow: rejected downgrade records pendingReroute -> Agent
    asks via cad_wait_for_user -> a REAL user t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
    [interference_clearance.step, interference_contact.step, interference_penetration.step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]
2026-08-19 0.8 M4: analysis-model separation, Blender presentation v2, section scan
    Analysis model vs canonical design (whitepaper section 10):
    - flow/thermal specs accept analysisModel {source, operations} with
    operations constrained to fused/bonded/simplified/defeatured/sectioned;
    validated fail-closed on both sides of the boundary.
    - verifyAnalysisModel(): when the simulation subject is not a canonical
    artifact of the workspace (current/baseline/head, compared by hash
    only — no geometry heuristics), an undeclared derived subject fails
    closed; a declared derivation rebinds the evidence SUBJECT to the
    authoritative source, which must itself be canonical (fake provenance
    fails closed).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
    [interference_clearance.step, interference_contact.step, interference_penetration.step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]
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2026-08-19 0.8 fix: disable Cycles denoising for distro Blender builds
    Ubuntu's blender package is built without OpenImageDenoise; Cycles
    lazy-loads OIDN during render and raises 'Build without
    OpenImageDenoiser' even when no denoising was requested. The
    presentation driver now sets use_denoising=False on the scene and all
    view layers — the renders never wanted denoising, so nothing changes
    where OIDN exists.
2026-08-19 prompts: mandate coordinate-frame confirmation in every baseline phase
    A user-supplied part's coordinate system is often arbitrary (legacy
    exports, vendor CAD, quick rebuilds) — a part can be lying on its side
    or mirrored relative to how it sits in the machine. Every later
    decision (load directions, datum faces, edit axes, up/front,
    world-referenced comparisons) inherits the frame mapping assumed at
    baseline, and a wrong assumption propagates silently into the plan,
    the geometry changes, and the review.
    baseline.md and source_baseline.md now make the frame mapping a
    mandatory gate on baseline_understood:
    - confirm the local-axes-to-functional-reality mapping with the user
    BEFORE leavin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
2026-08-19 0.8 review P0 (architecture): release suffix, single-source obligations, bound authority, record staleness
    Release is a SUFFIX, never a replacement (review P0-1):
    - compileWorkflow = designCore(lineage, structure) + releaseSuffix.
    greenfield/assembly/release now runs requirements -> system_concept ->
    assembly_design -> interface_design -> part_design -> build ->
    integration_review --accepted--> audit -> gap_closure -> package ->
    final_review, exactly as the whitepaper's process formula said.
    The design review's accepted hands INTO the suffix (transition table
    is authoritative for the accepted target; only final_review closes);
    gap_closure candidates land in audit via sourcePhas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
    [interference_clearance.step, interference_contact.step, interference_penetration.step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]
2026-08-19 0.8 review P0 (interpreters): fail-closed interference, exact sections, derivation records
    Interference fails closed (review P0-5):
    - A failed boolean common or distance computation raises
    InterferenceUnresolvedError instead of degrading to a distance-based
    classification: a solver failure must never be reported as "contact".
    The CLI surfaces the error envelope, so no interference evidence is
    recorded and integration review stays blocked until the facts can
    actually be computed.
    Section analytics are axis-symmetric exact (review P0-8):
    - _section_facts now builds an explicit (u, v, n) basis, recovers the
    raw global second moments from OCCT's planar-face inertia relations
    (M11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
    [interference_clearance.step, interference_contact.step, interference_penetration.step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]
2026-08-19 0.8 review P0-7: presentation consumes its spec + frozen provenance + multimodal preview
    The Blender interpreter now actually consumes the PresentationSpec
    instead of recording it in the manifest while rendering a fixed scene:
    Materials: the spec's family/pattern vocabulary (metal/plastic/
    composite/ceramic/rubber/glass × brushed/polished/cast/...) maps to
    Principled BSDF color/metallic/roughness per object. Unknown
    vocabulary fails closed at validate_spec AND in the driver — before
    pixels are made. Interpretation is recorded per object in the render
    report.
    Lighting: keywords parsed from the key/fill/rim strings scale the rig
    energies (softbox 1.0, bounce 0.5, sun 1.3, ...); an explici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
    [interference_clearance.step, interference_contact.step, interference_penetration.step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]
2026-08-19 0.8 review closure fixes: release closure semantics, structural derivation path, presentation freeze boundary
    P0-1 Release closure gate (controller): accepted's target comes from
    the transition table; presentation deliverables and the workstream
    completionGuard run ONLY when acceptedTarget === ready. The design
    review's accepted now enters audit demanding just the design-core
    evidence — previously the controller demanded release MP4s in a phase
    whose tool policy cannot even produce them.
    P0-2 Project Head atomicity (controller): updateHead runs only when
    result.state.phase === ready. A design-review accepted that hands into
    the release suffix no longer moves the head, so 'abort leaves the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
    [interference_clearance.step, interference_contact.step, interference_penetration.step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]
2026-08-20 clarify autonomous decision boundary for cad_wait_for_user and maturity routing
    Headless benchmark runs surfaced a harness weakness: agents paused in
    review (cad_wait_for_user) to ask about engineering judgment they own —
    nominal drawing content, coordinate conventions — and the run stalled in
    waiting_user with geometry already correct and all CADTests passing.
    General fix, prompt-policy layer:
    - cad_wait_for_user now states the decision boundary: user-owned decisions
    (scope/cost/risk/structural authority) vs engineer-owned judgment
    (requirement interpretation, nominals, conventions, evidence choices),
    and that headless pauses wait forever.
    - cad_route guidance now warns that matu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
2026-08-20 context memory MVP: proactive context rebuild for long agent runs
    - context/working.md holds the current engineering "brain" (understanding /
    intent / attempts / open questions); context/archive/ctx-NNN.json keeps the
    FULL raw pre-compaction trajectory (inline base64 images stripped, visuals
    persist under evidence/), indexed by context/refs.jsonl
    - session_before_compact handler serves manual/threshold/overflow paths:
    archive first (pure I/O, survives LLM failure), then one fresh LLM call
    over a budgeted serialized copy refreshes working.md, then a minimal
    compaction entry is returned; LLM failure falls back to Pi's default
    summary with the archive still durable
    - agent_settled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
2026-08-20 context-memory review fixes: forced continuation, full mission, reasoning, image assets
    P0
    - maybeAutoContinue gains { force } to bypass nudgedVersions (phase/status
    checks still apply); post-rebuild resume forces the continuation because
    the rebuild typically fires on the second+ autonomous continuation of the
    same phase+artifact version, whose nudge key was already consumed —
    without force the run stalls after compaction
    P1
    - Mission now renders preferences/assumptions/openUnknowns too, labelled
    provisional ("do not silently promote an assumption into a constraint"):
    the topology-optimization drift was exactly a tentative volume-fraction
    assumption hardening over a long ru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
2026-08-20 context-memory: reject truncated refreshes, mark stale working context
    - fresh working-context call raises maxTokens 4096 -> 8192: the Responses
    API's max_output_tokens covers hidden reasoning AND the visible working.md
    text, so medium reasoning + a ~3000-word document would hit length at 4096
    - a resolved-but-truncated refresh (stopReason !== "stop"; aborted/error
    already throw in the adapter) now returns updated=false and falls back to
    Pi's default compaction instead of persisting half a document as the next
    phase's "current brain"
    - when a refresh fails, the existing working.md is marked stale in
    context/working.meta.json and skipped at injection until the next
    successful re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
2026-08-20 requirement closure + geometry digest: minimal harness patch (closure-v1)
    First-round convergence of the CADTestBench failure analysis
    (failure-mechanisms-and-improvements-v0.2.md). Four minimal changes,
    no schema/state/compiler/Python-backend changes:
    - requirements.md: requirement closure — every explicit acceptance
    instruction becomes its own must[] item; interpretation decisions
    (units, dimension referents, resolved ambiguities) recorded in
    assumptions[]; conflicts that are engineering judgment get the most
    defensible reading + recorded rejection, never a headless stall.
    - review.md: accepted requires closing every Mission Must; bores/pockets/
    cuts verified for depth/through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
2026-08-21 cad_probe_python: programmable read-only B-Rep probe + absolute read_only bash fence
    Observability, not authoring. The Detailed-200 loss analysis showed
    failures concentrate in derived-quantity verification (volume/shape
    factor/symmetry/hole spacing) that no typed inspection tool expresses;
    the agent had computation but no legitimate read-only channel for it.
    New capability (review/compare/integration_review phases only):
    - python/cadctl probe: exec agent Python against the harness-resolved
    current/baseline STEP; scope preloads shape/bd/np/math/statistics with
    whitelisted builtins only (no open/__import__/exec/eval/subprocess);
    SIGALRM kills runaway loops; result must be JSON-serializ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
2026-08-21 phase 2: probe registry — src/modules/probe with 9 presets (visual/geometry/surfaces/measure/section/sections-scan/compare/assembly/interference); legacy inspection tools become thin wrappers; profil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
2026-08-21 phase 3: unified cad_probe — one observation tool over the probe registry (10 presets incl. programmable python mode, subject=current|baseline resolution from run state); legacy inspection tools mark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
2026-08-21 phase 6: SIMULATE module — shared lifecycle (freeze→execute→hash-resolve→observe) in src/modules/simulate; structural/flow/thermal become adapters; cad_simulate/cad_simulate_flow/cad_simulate_thermal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
2026-08-21 acceptance gate: three-layer adversarial review — T1 deterministic numeric reconciliation (checks[] claims vs evidence digest: bbox/volume/topology counts, 1% tol, counts exact, fail-closed), T2 one-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
    [interference_clearance.step, interference_contact.step, interference_penetration.step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]
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2026-09-17 fix(desktop): track Prime runtime phases and settle terminal turn outcomes
    ## Summary
    Desktop only knew `agent_start -> streaming` and `agent_end -> ready`, so Prime
    intermediate and abnormal states were invisible and a terminal turn could fall
    back to a non-terminal state. The desktop runtime now owns the state machine,
    and the rework passes tightened the terminal semantics and the watchdogs that
    drive them.
    - New `PrimeRuntimeState` maps raw Prime RPC events to `phase`
    (`starting_turn`, `waiting_provider`, `thinking`, `responding`,
    `running_tool`, `compacting`, `retrying`, `provider_wait`, `stalled`,
    `stopping`) and keeps one turn record per turn: `startedAt`,
    `phaseStartedAt`, `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
2026-09-17 fix(desktop): show the runtime's real Prime turn phases
    Rework of #24 after human review: the renderer no longer decides the turn
    state. RES-288 / PR #22 owns the runtime state machine, and this PR only
    displays what that runtime reports.
    **Base: `master`.** #22 was squash-merged into master as `0132a0e0`; this branch
    is rebased onto that commit, so the diff below is only this PR's work.
    What changed:
    - `ChatMessage.stream` lost its state. `ChatStream` keeps only `startedAt`,
    `firstTokenAt` and `finishedAt`, so the reducer assembles text and nothing
    else. `activity.ts` no longer invents `waiting` / `thinking` / `responding`
    from event types and no longer classifies termi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
2026-09-18 chore: refresh the generated agent contract (#29)
    The observe_programmable semantics changed on master without regenerating
    assets/registry-contract.json, so the ci workflow fails on
    `check:agent-contract` for every branch. Regenerate it from the current
    registry.
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2026-09-18 fix(probe): run arbitrary analysis on disposable STEP copies (#16)
    (cherry picked from commit 1218f67067598bab8b20ef8a3d451817a7c09ef5)
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2026-09-19 fix(desktop): detect and repair a broken managed CAD Python (#27)
    (cherry picked from commit a43ea8af161e0ed44c212248bb743081d006ccb5)
2026-09-19 fix(workflow): isolate workflow runs per Prime conversation (#31)
    * feat(workflow): bind workflow runs to Prime conversations
    Summary:
    - add a durable conversation to run binding: a hidden
    pi-cad.workflow-binding transcript entry owned by each Prime
    conversation, plus a project conversations registry so the stateless
    Python kernel socket can name its own conversation
    - resolve every sidecar/Agent API run through one scoped chokepoint, so a
    conversation sees only its bound run and an unbound conversation sees
    no run at all instead of the project current/promoted run
    - start conversation runs without touching project.currentRunId, keep
    Project HEAD promotion for finished conversat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
2026-09-19 fix(desktop): project workflow state per Prime conversation (#32)
    * fix(desktop): bind the workflow projection to one conversation
    - track which Prime conversation the Desktop window shows and read
    workflow-current / viewer-catalog for exactly that session, instead of
    the project-global workspace status projection
    - select a new conversation without opening an empty Prime transcript: the
    projection drops to unbound at the click, and Prime opens the session on
    the first prompt
    - announce the selected conversation to the renderer so the workflow rail,
    the rating reading and the viewer re-read their projections on every
    new, switch, restore and stop
    - return the phase pict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
2026-09-21 fix(workflow): preserve default workflow contract wording
    [default.yaml]
2026-09-21 feat(chaos): Reify 系统 invariant catalog 与自动 checker
    建立一套 Reify 系统 invariant catalog，并把每条规则接成读真实状态、能给出证据的自动 checker。本单只把规则写清并接上检查，不扩大随机故障空间，也不做长时间 campaign。
    - `docs/chaos/system-invariants.zh-CN.md`：19 条 invariant（P0 9 / P1 10），每条都写明 scope、why、state sources、check condition、grace/budget、failure evidence、known exceptions。
    - `src/chaos/invariants/**`：checker 框架。只读 Reify 真实落盘状态：project store、run store、已发布的 transaction 链、workspace commit、recipe-run 记录、锁、staging 目录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
2026-09-21 feat(chaos): 最小 Chaos 系统 POC + 真 Reify vertical slice
    RES-384：不要重造 Antithesis，先做一套能真的发现系统级问题、并跑通一条真实故障链的最小 Chaos 系统。
    最终形态是两层：
    1. `chaos/` harness + `chaos/sut/`：自写的、形状和 Reify 一致的 POC 系统，用来验证 harness 本身。
    2. `chaos/reify/`：**真 Reify vertical slice**，直接打 Reify 本体。
    ## 这条链路
    ```
    fast-check 生成 action/fault 序列
    → 注入真故障（SIGKILL/SIGSTOP/SIGCONT、Toxiproxy 外部 API 故障）
    → invariant 失败
    → 存 artifact（seed / path / 序列 / trace / ID / 时间线）
    → replay 复现
    → fast-check shrin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
2026-09-23 fix(prime): scope one-shot gates and verify subagents
    - Check one-shot completion against the conversation bound by this launch.
    - Allow naked workflow runs to finish through their declared transition.
    - Add real Prime CLI and Desktop RPC CAD smoke coverage for parallel
    children, a grandchild, typed image delivery, failure isolation, and
    explicit parent adoption of child artifacts.
    - Update the CLI boundary smoke for conversation-owned workflow runs.
    - Conversation runs intentionally do not set a project-global pointer.
    The launcher must therefore check the root conversation's run after
    Prime exits. Child output remains isolated until the parent adopts it.
    Tests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
    [naked.yaml]
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2026-10-09 deploy: close k3s gaps for platform-api, controller error and trash tasks
    Image and build
    - cloud/platform-api/Dockerfile: node:22-bookworm-slim, repo layout kept so
    default paths resolve, non-root uid 10001, migrations then server in CMD.
    - tsx moves to runtime dependencies so `npm ci --omit=dev` keeps it.
    - cloud/platform-api/build.sh builds reify/platform-api:<short sha> and
    imports it into k3s (--no-import to skip).
    Manifests
    - platform-api-config sets every variable the server reads that was missing:
    TRUST_PROXY, WORKSPACE_TEMPLATE_PATH, WORKSPACE_SECCOMP_TYPE,
    WORKSPACE_HOST_USERS, GATEWAY_URL_PATTERN. PLATFORM_INTERNAL_URL now points
    at the internal Service.
    - New Service p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
    [platform-api.yaml, reify-ws-policy.yaml]
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2026-10-09 test(dfm): end-to-end fixtures for the 铨洲 rules and the threaded-hole diameter spike
    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
    [part.step]
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2026-10-09 perf(render): rasterise triangles in batches, same pixels
    The renderer made about 25 numpy calls per triangle. Seven views of an 81-part
    assembly (60 000 triangles each) took 23 s, and every build renders them.
    Triangles of similar size are now tested together and the covered pixels are
    resolved at once: the greatest depth wins, and of equal depths the earlier
    triangle, as the loop's strict > gave. Rasterising 23 s to 7 s. The 7 views of the
    cow assembly are byte-identical to the old renderer's, the pinned pixel hashes
    still match, and a test compares both rasterisers on random triangles.
    [interference_clearance.step, interference_contact.step, interference_penetration.step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]
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
